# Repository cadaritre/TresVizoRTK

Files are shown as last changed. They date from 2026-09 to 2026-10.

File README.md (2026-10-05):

# TresVizoRTK

**Alimentación — 02/10/2026:** LiPo 1S 3.7 V / 3000 mAh confirmada. Lectura MAX17048 y apagado coordinado Mk2 implementados; falta identificar el elevador de 5 V y validar físicamente el conjunto con UM980. Ver `hardware/wiring.md` desde la raíz. La carga es autónoma por hardware; USB impide el corte total de batería.
TresVizoRTK es un proyecto personal para desarrollar un prototipo funcional de receptor GNSS RTK de triple banda con IMU y lector microSD, orientado a trabajos de topografía. El repositorio reunirá el firmware de un ESP32-S3, una aplicación móvil, la documentación electrónica, la lista de materiales y los archivos mecánicos de una carcasa imprimible en 3D. La cobertura de bandas del conjunto receptor y antena deberá verificarse con el hardware real.

El objetivo es disponer de un software de instrumento robusto en el ESP32-S3, tomando la experiencia de equipos Emlid como referencia de producto. El firmware concentrará la configuración y operación del equipo; una app independiente, todavía sin iniciar, resolverá levantamientos, replanteos y trazo. Esta referencia no implica equivalencia de funciones o rendimiento validada.

El objetivo de desarrollo es alcanzar aproximadamente 2 cm de precisión en condiciones favorables. Esa cifra no representa una capacidad implementada, medida ni garantizada. La operación bajo árboles es un interés de investigación del proyecto y tampoco implica una garantía de precisión bajo vegetación.

## Estado actual

El firmware **0.8.0** está adaptado y compilado para **SparkFun Thing Plus ESP32-S3 WRL-24408**. El equipo conserva el nombre **MeridianV**, el panel, BLE, NTRIP y los servicios GNSS. La nueva placa sustituye a la Tiny; las pruebas físicas históricas de esa placa no validan este montaje.

Esta entrega añade OLED SSD1306 I2C de 128×64, microSD integrada por SDIO y una identidad de hardware independiente para las imágenes firmadas. La pantalla muestra calidad GNSS, satélites, correcciones, grabación e IP; caduca la calidad cuando dejan de llegar datos. La tarjeta no se formatea automáticamente.

El panel identifica la placa, muestra el estado de OLED y microSD y controla el registro según la disponibilidad real y el cierre de archivos. Las descargas incompletas conservan `.part`. Cargador USB y diagnóstico BLE actualizados para la nueva placa; [detalle del software](docs/panel-campo.md).

El almacenamiento se llama **Memoria interna del dispositivo** en la interfaz y en las etiquetas de la API para aplicaciones; en la OLED, **MEM INT.**. El soporte físico sigue documentado como microSD. Grabación, cierre, catálogo y descarga implementados; comprobación física pendiente.

**Pendiente de banco:** primera carga en Thing Plus, OLED recibida, microSD, enlace UART y operación prolongada. La adaptación no cargó firmware en ningún equipo. **Encendido/apagado con el SparkFun Soft Power Switch implementado; prueba física pendiente.** Durante el banco, Thing Plus y UM980 mantienen alimentación USB separada y GND común.

**Sin integrar:** IMU, radio UHF y aplicación móvil. La carcasa diseñada para Tiny requiere revisión para la Thing Plus y la OLED; no se ha dado por compatible ni se ha regenerado CAD.

El [cableado vigente](hardware/wiring.md) reúne los pines y la primera instalación. Detalle de cambios y pruebas en el [README del firmware](firmware/esp32/README.md). Las imágenes OTA llevan la [firma del propietario](tools/firmware_signing/README.md).

## Alcance previsto

El prototipo busca llegar a:

- Operación como rover RTK o como base.
- Recepción y transmisión de correcciones por los enlaces que se validen.
- Acceso a correcciones NTRIP.
- Registro de observaciones GNSS para postproceso externo.
- Integración GNSS/IMU y compensación de inclinación del jalón, todavía por desarrollar y validar.
- Configuración y operación del instrumento gestionadas por el firmware del ESP32-S3.
- Aplicación móvil independiente para levantamientos, replanteos y trazo, con acceso a configuración y estado mediante el protocolo del instrumento.
- Registro de diagnósticos para análisis y mejora del sistema.

## Arquitectura resumida

- **Receptor GNSS:** calcula la solución GNSS/RTK y produce observaciones y mensajes compatibles con su modelo y firmware.
- **ESP32-S3:** controla el receptor, enruta RTCM, adquiere la IMU, gestiona tiempos, almacenamiento, comunicaciones y apagado seguro. La fusión GNSS/IMU es trabajo futuro.
- **IMU BMI088:** aporta aceleración y velocidad angular para la futura integración GNSS/IMU y compensación de inclinación.
- **Lector y tarjeta microSD:** proporcionan almacenamiento local de observaciones, datos IMU y diagnósticos bajo control del ESP32-S3.
- **Aplicación móvil independiente:** gestiona mapas, proyectos, levantamientos, replanteos, trazo e intercambio de archivos; consulta el estado y solicita cambios de configuración al firmware.

La aplicación se comunicará mediante un protocolo propio del instrumento, separado de los comandos específicos de Unicore o u-blox. BLE se prevé como enlace principal de control y telemetría; el objetivo de 20 Hz está pendiente de pruebas. Wi-Fi, conectado al hotspot del teléfono, permitiría al ESP32 acceder a NTRIP. USB se reserva para desarrollo y diagnóstico, y Wi-Fi o USB para transferencias grandes.

La [arquitectura](docs/architecture.md) describe las responsabilidades y los flujos de datos con mayor detalle.

## Hardware previsto

La base considerada incluye:

- Unicore UM980 en una placa de desarrollo o carrier como GNSS principal.
- u-blox ZED-F9P disponible para posibles pruebas.
- SparkFun Thing Plus ESP32-S3 WRL-24408, con 4 MB de flash y 2 MB de PSRAM Quad según fabricante.
- Bosch BMI088 en breakout.
- Socket microSD integrado de la Thing Plus, SDIO de cuatro bits y tarjeta FAT32.
- OLED Tecneu 0.96 pulgadas I2C, cuatro pines y 128×64; driver SSD1306 según referencia del vendedor.
- Antena Helix, cuya compra confirmó el propietario; modelo y bandas por verificar. La HA-901A mencionada inicialmente no está confirmada.
- Batería LiPo de una celda, nominal 3.7 V y 3000 mAh, confirmada por el propietario.
- SparkFun Soft Power Switch JST 2 mm comprado; integración de encendido/apagado implementado; prueba física pendiente.
- Carcasa cilíndrica impresa en 3D y montaje sobre jalón.

El enlace GNSS usa RX del ESP32 en **GPIO44** y TX en **GPIO43**, con GND común; ambos equipos reciben alimentación USB por separado. La OLED usa **SDA8/SCL9 y 3.3 V**. El pinout de la Tiny (18/17) queda como historial. La disponibilidad de PPS en la carrier UM980 concreta está pendiente de verificación. Consulta la [lista de materiales](hardware/bom.md) y el [cableado vigente](hardware/wiring.md).

## Mapa del repositorio

| Ruta | Contenido previsto |
| --- | --- |
| `firmware/esp32/` | Firmware del controlador ESP32-S3. |
| `app/` | Aplicación móvil del instrumento. |
| `hardware/` | BOM, módulos comerciales, conexiones y referencias del hardware vigente. |
| `mechanical/` | V1 para imprimir y fuentes necesarias para regenerarla. |
| `docs/` | Arquitectura, estado, hoja de ruta y entorno de desarrollo. |
| `tools/` | Puente USB, diagnóstico GNSS/BLE, empaquetado y actualización de firmware. |
| `tests/fixtures/` | Datos de prueba pequeños y anonimizados. |

## Documentación

- [Arquitectura del sistema](docs/architecture.md)
- [Estado del proyecto](docs/project-status.md)
- [Servicios actuales del ESP32 (0.5.0)](docs/esp32-services.md)
- [Configuración avanzada del receptor (0.6.0)](docs/gps-advanced.md)
- [Panel reorganizado para campo (0.6.0)](docs/panel-campo.md)
- [Hoja de ruta](docs/roadmap.md)
- [Entorno y prácticas de desarrollo](docs/development.md)
- [Lista de materiales](hardware/bom.md)
- [Identificación del hardware recibido](hardware/identification.md)
- [Interfaces y conexiones](hardware/wiring.md)
- [Mecánica vigente, V2.2](mechanical/README.md)
- [Auditoría de la carcasa V1](mechanical/AUDITORIA-V1.md)
- [BOM de tornillería](mechanical/v2.2/SCREW-BOM.md)
- [Revisión de integración de V1, antecedente](docs/INTEGRATION_REVIEW.md)

No se ha seleccionado una licencia. El contenido del repositorio no debe interpretarse como publicado bajo una licencia específica hasta que el propietario la defina expresamente.

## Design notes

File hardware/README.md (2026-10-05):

# Hardware vigente

- [power-modules](power-modules/README.md): alimentación por módulos comerciales, arnés, panel y compras.
- [bom.md](bom.md), [identification.md](identification.md) y [wiring.md](wiring.md): inventario e interfaces del receptor.
- `references/`: evidencia de la batería y esquemas de Waveshare usados como referencia; no son una PCB propia para fabricar.
- [V2.2 mecánica](../mechanical/v2.2/README.md): carcasa, soportes y montaje vigentes.

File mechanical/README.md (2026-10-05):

# Mecánica vigente — TresVizo V2.2

**Abrir [TresVizo-V2.2.FCStd](v2.2/generated/TresVizo-V2.2.FCStd) con FreeCAD**, o
`v2.2/view_v2_2.py` para verlo con colores. Generado y comprobado con FreeCAD 1.1.

| Carpeta / archivo | Uso |
| --- | --- |
| [v2.2](v2.2/README.md) | **Vigente.** Montaje, criterio de diseño, parámetros y límites. |
| [v2.2/generated/stl](v2.2/generated/stl/) | Imprimir: cinco piezas rígidas y dos bandas de TPU. |
| [v2.2/generated/step](v2.2/generated/step/) | STEP por pieza para otros CAD, en posición cerrada. |
| [v2.2/SCREW-BOM.md](v2.2/SCREW-BOM.md) | Compra: 15 tornillos, la tuerca de latón del jalón y el conector de carga JST-XH. Los dos del IMU, avellanados. |
| [AUDITORIA-V1.md](AUDITORIA-V1.md) | Por qué se rehízo la carcasa desde cero. |
| [referencias](referencias/) | Cotas de los componentes comprados y datum del BMI088. |

## Qué cambió de V2.1 a V2.2

| | V2.1 | V2.2 |
| ---: | ---: | ---: |
| Diámetro exterior | 69 mm | **64 mm** (67.4 con las bandas de TPU) |
| Altura, del asiento del jalón a la cara de la antena | 136.9 mm | **129.9 mm** |
| Batería | LiPo 955565 en el trineo | **18650 detrás del respaldo** |
| Panel frontal | 66° × 58 mm, con USB-C | **86° × 83 mm**, con OLED 0.96", botón metálico de 12 mm y conector de carga JST-XH |
| Rosca del jalón | inserto de McMaster con brida: solo entraba pausando la impresión | **tuerca hexagonal 5/8"-11 de latón**, metida por dentro de la base |
| Panel auxiliar | sí | **no** |
| Interior | trineo atornillado a la base | **respaldo ranurado en el tubo y cuatro toalleros**; todo se amarra con bridas |
| IMU | repisa del trineo, con los agujeros en el eje (el chip quedaba 5.65 mm fuera) | **plataforma incrustada en la tapa**, con el chip en el eje |
| Bayonetas | entraban en tres posiciones | **una sola posición** |
| Protección | — | **bandas de TPU** arriba y abajo |

Las versiones anteriores (V2, V2.1 y la opción del domo para V2.1) se quitaron
del repositorio el 04-10-2026. Siguen en el historial de git: la última vez que
están completas es el commit `94f00f9`.

## Regenerar

```sh
python3 mechanical/v2.2/regenerate.py
```

Localiza FreeCAD solo, también en macOS. Comprueba sólidos, mallas,
interferencias, el paquete y la 18650 en el respaldo, los toalleros, la entrada
de la tapa del panel con todo montado, los pilotos del IMU, las uñas de la
plataforma, las bayonetas indexadas, la alineación de los seguros, la tuerca
del jalón con sus retenes, el bolsillo del JST y los tornillos bajo las bandas,
y devuelve código distinto de cero si algo falla.

## Estado

**Nada de V2.2 se ha impreso ni ensayado.** La geometría es coherente en CAD; eso
no es validación. Antes de imprimir la plataforma del IMU hay que medir en la
placa real dónde está el chip (ver el README de V2.2), y medir la tuerca del
jalón y el header JST que se compren: el modelo usa las medidas de norma y del
plano de JST.

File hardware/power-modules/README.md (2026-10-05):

# Alimentación e interfaz con módulos comerciales

> **Histórico — 02/10/2026:** esta propuesta corresponde a la Tiny. La placa definitiva es Thing Plus ESP32-S3 y el control del Soft Power Switch está implementado; la distribución portátil del UM980 sigue pendiente. No aplicar este arnés al montaje nuevo; consultar [cableado vigente](../wiring.md).

Revisión del 20 de septiembre de 2026. Sustituye la propuesta de PCB personalizada por módulos comprables y un arnés. Se conservan la Tiny, su Tiny-Adapter y cable original, el UM980, BMI088, microSD y batería. El receptor V2 (hoy [V2.2](../../mechanical/v2.2/README.md)) integra los paneles y los soportes internos; el firmware se conserva.

**Resultado: tres módulos principales, pulsador y dos ventanas de luz en el panel.** El USB-C exterior se usa para alimentación/carga y para el USB nativo del ESP32. El botón exterior acciona el encendido electrónico; el cierre de archivos antes de apagar requiere integración en firmware. No hay PCB que mandar fabricar.

Es una selección y un diseño de interconexión para prototipo, contrastados con documentación. No es un montaje ensayado ni una declaración de cumplimiento USB. Las limitaciones concretas de corriente del host, detección VBUS y protección se indican abajo; no están resueltas simplemente por comprar las tres placas.

## Lista principal

Precios publicados al consultar; excluyen envío e impuestos adicionales. Se distinguen USD y MXN. Véase [suministro para México](SOURCING_MX.md) para vendedores y disponibilidad real observada.

| Función | Producto comprado ya montado | Cantidad | Precio |
| --- | --- | ---: | ---: |
| Cargador LiPo 1S, power-path y elevador | [Adafruit PowerBoost 1000C, 2465](https://www.adafruit.com/product/2465) | 1 | $19.95 |
| Pulsador electrónico, apagado por software y forzado | [SparkFun Soft Power Switch Mk2 JST 2 mm, PRT-26993](https://www.sparkfun.com/sparkfun-soft-power-switch-jst-2mm.html) | 1 | $7.32 |
| USB-C exterior y desconexión de datos | [Adafruit TS3USB30, 5871](https://www.adafruit.com/product/5871) | 1 | $3.95 |
| Pulsador bajo un actuador impreso al ras | [Steren AU-101, momentáneo NA](https://www.steren.com.mx/micro-switch-de-push-con-4-terminales.html) | 1 | $2 MXN |
| Indicador de estado RGB | [Steren LED-5/RGB, ánodo común](https://www.steren.com.mx/led-de-5-mm-rgb.html) | 1 | $5 MXN |

**Los tres módulos suman $31.22 USD; pulsador y RGB suman $7 MXN.** El presupuesto anterior de $35.72 USD empleaba dos periféricos Adafruit y queda sustituido por esta selección local. Añadir cable USB corto, cableado, resistencias, transistores, fusibles, tornillos, piezas ópticas y envío/importación. El costo total entregado no está cotizado; tampoco incluye una protección de batería adicional si el pack carece de ella ni las ampliaciones USB descritas abajo. No se compró nada.

El indicador de carga aprovecha los LEDs amarillo y verde del PowerBoost mediante guías ópticas hacia una segunda ventana. Así funciona con el receptor apagado y no requiere otra placa ni modificar las salidas del cargador.

## Conexión general

```mermaid
flowchart TD
  PC[Computadora o cargador USB] --> U[USB-C exterior: Adafruit 5871]
  U -->|USB_VBUS; ramal de carga desconectable| P[PowerBoost 1000C]
  B[Batería LiPo 1S protegida] <--> P
  P -->|VS: antes del elevador| S[SparkFun Soft Power Switch Mk2]
  BTN[Pulsador al ras] -->|BTN / GND| S
  S -->|VOUT: señal de habilitación| EN[EN del PowerBoost + 10 kohm a GND]
  EN --> P
  P -->|Salida regulada SYSTEM_5V| LOAD[Tiny + UM980 + demás cargas verificadas]
  U -->|D1+ / D1-; sólo datos y masa| C[Cable interno USB-C con alimentación separada]
  P -->|SYSTEM_5V al VBUS del cable interno| C
  C --> A[Tiny-Adapter original]
  A -->|FPC original, sin cambiarlo| ESP[ESP32-S3-Tiny externa]
  ESP <-->|PUSH / OFF| S
  ESP -->|GPIO y drivers del arnés| RGB[LED RGB detrás de ventana]
```

**USB_VBUS del conector exterior y SYSTEM_5V son redes distintas.** La alimentación del cable USB interno hacia Tiny-Adapter proviene de SYSTEM_5V. No se conecta a los pads de alimentación de las salidas del TS3USB30: esos pads están unidos a USB_VBUS y no son salidas aisladas.

El PowerBoost integra MCP73871 para reparto entre fuente/carga/batería y TPS61090 para elevar a aproximadamente 5.2 V. La protección contra descarga inversa del cargador y la separación del arnés evitan la ruta directa batería → host. Debe comprobarse el conjunto montado. [Esquema oficial](https://github.com/adafruit/Adafruit-PowerBoost-1000C), [MCP73871](https://www.adafruit.com/datasheets/MCP73871.pdf).

## Encendido y apagado

Se alimenta el SparkFun desde **VS**, no desde la salida de 5 V. Su salida controla **EN** del PowerBoost y una resistencia de 10 kΩ asegura el estado apagado. No transporta la corriente de todas las cargas. Esto permite apagar el elevador, cargar con el equipo apagado y conservar el apagado forzado por hardware.

El esquema oficial del PowerBoost Rev B tiene un pull-up de 200 kΩ en EN. Con 10 kΩ a masa, apagado queda nominalmente a 0.0476 × VS, por debajo del límite LOW de 0.2 × VS del TPS61090. Encendido sigue a VS y supera 0.8 × VS. Es un cálculo del circuito, pendiente de ensayo del conjunto. [Archivos Adafruit](https://github.com/adafruit/Adafruit-PowerBoost-1000C), [TPS61090](https://www.adafruit.com/datasheets/tps61090.pdf).

El pulsador se conecta a BTN/GND; PUSH informa al ESP32 y OFF alto corta. Una pulsación sostenida unos diez segundos corta por hardware. Abrir los jumpers de LEDs IN/OUT del SparkFun evita luz y consumo internos innecesarios. El consumo de toda la instalación apagada debe medirse; el dato de reposo del módulo no representa el sistema completo. [Guía SparkFun](https://docs.sparkfun.com/SparkFun_Soft_Power_Switch_Mk2/single_page/).

## Qué permite el puerto único

| Estado | Comportamiento previsto |
| --- | --- |
| Batería, equipo ON | Operación normal; el puerto exterior no suministra 5 V al host. |
| USB, equipo OFF | Carga; sin consola porque el ESP32 está apagado. |
| USB, equipo ON | Carga/alimentación y datos simultáneos, dentro de la corriente disponible. |
| Debug detenido en un breakpoint | Alimentación mantenida por el módulo; no necesita heartbeat del firmware. |
| Firmware bloqueado | Pulsación larga corta; para recuperar el firmware quedan BOOT/RUN del Tiny-Adapter. |

El USB nativo proporciona flashing, consola Serial/JTAG y depuración del **ESP32**. El UM980 se consulta desde esa consola mediante su UART y software de puente/diagnóstico que debe implementarse. **No se promete que el programa de actualización de Unicore pueda reflashear el UM980 a través del ESP32 sin ese puente y sin verificar su protocolo.** No hay acceso JTAG al UM980 a través del JTAG del ESP32. [Espressif USB Serial/JTAG](https://docs.espressif.com/projects/esp-idf/en/stable/esp32s3/api-guides/usb-serial-jtag-console.html).

## Límites que condicionan el montaje

1. **Corriente del USB.** PowerBoost está configurado para fuente de pared y carga de hasta 1 A; no negocia por sí mismo el presupuesto de un puerto de computadora. Para carga y operación simultáneas usar una fuente/puerto documentado de 5 V y al menos 2 A, compatible con su margen de entrada. Las resistencias CC de la placa USB no autorizan a tomar 2 A de cualquier puerto. Para un puerto de datos de capacidad desconocida, abrir el ramal interno `CHARGE_LINK` y operar desde batería: el mismo USB-C sigue dando datos. Para automatizar carga limitada en todos los puertos haría falta gestión adicional de corriente; no se presenta como resuelta.
2. **Batería.** La referencia 955565 anunciada es 1S, 3.7 V/5000 mAh. Antes de conectarla se comprueban polaridad, protección PCM y admisión de carga a 4.2 V/1 A. PowerBoost no sustituye una protección de pack ni incorpora un termistor pegado a esta batería. La carga de una celda cuya protección y límites se desconocen no queda validada. Se conserva la [evidencia original](../references/BATTERY_REFERENCE.md).
3. **USB self-powered.** El TS3USB30 permite desconectar los datos cuando está sin alimentación y seleccionar un canal vacío cuando Tiny está apagada. Eso **no demuestra** los umbrales de detección VBUS ni el tiempo de desconexión. Espressif indica detección válida por encima de 4.75 V, inválida por debajo de 4.35 V y señal baja en 3 ms al desconectar. Los condensadores de los módulos pueden retener VBUS. El prototipo requiere medirlo y completar detector/descarga si procede; no es una solución certificada. `self_powered` y `vbus_monitor_io` pertenecen a TinyUSB/OTG, no configuran Serial/JTAG ni ROM. [Espressif](https://docs.espressif.com/projects/esp-idf/en/v5.4/esp32s3/api-reference/peripherals/usb_device.html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), [TI TS3USB30](https://cdn-shop.adafruit.com/product-files/5871/ts3usb30.pdf).
4. **Protección y corriente del sistema.** El módulo USB no trae una matriz TVS dedicada; la especificación HBM del chip no acredita ESD del equipo. Para uso de campo debe completarse esa protección y ensayarse. El elevador se selecciona para un presupuesto inicial de hasta 1 A; comprobar arranque, radio, microSD, ruido GNSS y margen térmico con todos los módulos. Verificar las entradas de alimentación reales antes de distribuir 5.2 V. No aplicar 5.2 V al chip BMI088 ni a señales de 3.3 V.

Estos puntos separan el prototipo económico de la anterior propuesta de producto con protecciones adicionales; no deben ocultarse en una lista de compras presentada como equivalente.

## Archivos y alternativas evaluadas

- [Cableado y control](WIRING.md).
- [Montaje al panel y dimensiones para mecánica](PANEL.md).
- [CAD, STEP, STL y montaje de V2.2](../../mechanical/v2.2/README.md).
- [Proveedores para México](SOURCING_MX.md).
- [Diagrama inicial del reparto](panel-and-modules.svg), anterior a seleccionar pulsador y RGB Steren; no usar sus precios como presupuesto vigente.

El [Adafruit bq25185 + boost 6106](https://www.adafruit.com/product/6106), de $8.95, ahorra $11, pero su guía advierte arranque con cargas por encima de 200 mA y un temporizador de carga fijo de seis horas. No se elige sin resolver esas condiciones para el GNSS y la batería de 5 Ah. [Limitaciones oficiales](https://learn.adafruit.com/adafruit-bq25185-usb-dc-solar-charger-with-5v-boost-board/pinouts).

El [DFRobot MP2636 DFR0446](https://www.dfrobot.com/product-1613.html), de $8, es otra alternativa documentada con power-path, pero requiere cerrar corriente de carga/entrada, control OFF y transiciones de fuente de la placa concreta antes de sustituir el PowerBoost. El biestable verde que ya tiene el proyecto puede reutilizarse sólo después de identificar sus señales y comprobar apagado controlado/forzado; no se atribuyen esas funciones por su anuncio. CP2102N queda fuera.

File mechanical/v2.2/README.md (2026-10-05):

# TresVizo V2.2 — Ø64 × 130, panel con pantalla y botón, IMU en la tapa, bandas de TPU

Revisión de V2.1 pedida por el propietario el 2 de octubre de 2026:

1. **Diámetro máximo 64 mm** (sin contar las bandas de TPU) y altura de unos
   130 mm. La batería es una **18650**: no hace falta el ancho que pedía la
   955565 de V2.1.
2. Panel frontal con la pantalla OLED y el botón metálico de 12 mm que compró,
   cada uno con su montaje, más el conector de carga y los dos LEDs. Sin panel
   auxiliar.
3. Fuera el trineo universal. Todo se amarra con bridas a un respaldo que forma
   parte del tubo, con huecos grandes en sus costillas, o a cuatro toalleros.
4. El IMU va en una plataforma que se incrusta en la tapa de antena, con el
   **chip** en el eje del receptor, y con un paso amplio para el coaxial.
5. Tapa plana, como V2.1, y dos bandas de protección de TPU, arriba y abajo.

El 4 de octubre pidió dos cambios más: la rosca del jalón con una tuerca que se
compra hecha ([Tuerca del jalón](#tuerca-del-jalón)) y, en el panel, un JST-XH
de 2 pines en lugar del USB-C, para simplificar la carga.

El primer borrador de V2.2 medía Ø79 (commit `5d196e6`). El propietario fijó
después Ø64 como máximo. Entre medias, una revisión independiente del modelo
encontró fallos que quedan corregidos (ver [abajo](#lo-que-corrigió-la-revisión)).

V2.1, V2 y la opción del domo se quitaron del repositorio el 4 de octubre.
Siguen en el historial de git: la última vez que están completas es el commit
`94f00f9`.

**Nada de V2.2 se ha impreso ni ensayado.** La geometría es coherente en CAD y
pasa las comprobaciones automáticas; eso no es validación.

## Qué cambió frente a V2.1

| | V2.1 | V2.2 |
| --- | ---: | ---: |
| Diámetro exterior | 69 mm | **64 mm** (67.4 con las bandas) |
| Del asiento del jalón a la cara de la antena | 136.9 mm | **129.9 mm** |
| Largo útil interior | 114 mm | **107 mm** |
| Batería | LiPo 955565 en el trineo | **18650 detrás del respaldo** |
| Panel frontal | 66° × 58 mm: USB-C, botón de 10.4, dos LEDs | **86° × 83 mm**: OLED 0.96" en su marco, botón de 12 mm, JST-XH de carga a ras, dos LEDs |
| Panel auxiliar | 50° × 40 mm con USB-C | **no hay** |
| Rosca del jalón | inserto de McMaster con brida | **tuerca hexagonal 5/8"-11 de latón**, por dentro de la base |
| Interior | trineo atornillado a la base | **respaldo ranurado en el tubo y cuatro toalleros** |
| IMU | repisa del trineo, con los **agujeros** en el eje (chip 5.65 mm fuera) | **plataforma incrustada en la tapa**, con el **chip** en el eje |
| Bayonetas | tres dientes iguales: la tapa cerraba en tres posiciones | **un diente índice**: una sola posición |
| Protección | — | **bandas de TPU** arriba y abajo |
| Piezas | 6 | 7 (5 rígidas y 2 de TPU) |
| Tornillos con largo definido | 13 | 15 |
| Material rígido | 187 cm³ | 156 cm³ |

## Tuerca del jalón

La rosca del jalón es una **tuerca hexagonal 5/8"-11 UNC de latón**, estándar:
15/16" entre caras y 35/64" de alto. Sustituye al inserto de McMaster que venía
de V2, que solo entraba pausando la impresión.

- Entra **por dentro** de la base, con el tubo quitado, en un alojamiento
  hexagonal de 24.1 mm entre caras que no la deja girar.
- Apoya en un **anillo de 2 mm**. La cara de abajo de ese anillo es el asiento
  contra el bastón: se imprime sobre la cama, plana y a escuadra con el eje. Al
  apretar, el perno jala la tuerca contra el anillo y el anillo contra el hombro
  del bastón: todo trabaja a compresión.
- El perno cruza el anillo con 0.36 mm de holgura por lado, por una entrada a
  45°, y no rosca en el plástico.
- Por arriba la detienen **dos M3×8 con arandela ancha DIN 9021** (9 mm),
  frente a dos caras del hexágono. Cada arandela pisa 1.4 mm de tuerca y deja
  2.6 mm al perno. Solo trabajan mientras entra el perno o con el equipo suelto.
- Se imprime sin pausa, y si se daña la rosca se cambia la tuerca.
- La altura no cambia: la cara de arriba de la base sigue en z = 15.9 y el ARP
  en 129.9 mm.
- En un mismo bastón el receptor queda siempre en el mismo ángulo; en otro
  bastón, en otro. El frente es el panel: se gira el bastón para tenerlo
  enfrente, como pide Emlid con su Reach RS3.

**Qué tuerca comprar:** hexagonal estándar de 5/8"-11 UNC de latón (en ferretería,
"5/8 NC" o "rosca estándar", 11 hilos). No sirven la pesada (1-1/16" entre
caras), la de rosca fina 5/8"-18 ni las de seguridad con nylon. Una que se
encontró el 04-10-2026:
[Los Tornillos, "TUERCA HEXAGONAL NC ESTANDAR 5/8 LATÓN"](https://lostornillos.mx/products/tuerca-hexagonal-nc-laton-5-8-11),
51.79 MXN. Al recibirla, medirla: hasta 24.0 entre caras y 13.9 de alto entra
tal cual. Si no, se cambia `tuerca_jalon` en `parameters.json` y se regenera.

## El IMU: qué estaba mal en V2.1 y cómo queda

En el BMI088V1.0 los dos agujeros están en el borde largo **opuesto** a los
pines, y el chip queda **5.65 mm** hacia los pines. V2.1 ponía en el eje la línea
que une los agujeros (x = ±9.25, y = 0): el sensor acababa 5.65 mm fuera del eje,
y su ajuste de ±1.5 mm no alcanzaba para corregirlo. Además lo sujetaba con M2 en
ranuras, con tuerca y arandela.

Posición del chip en la placa, cruzando el plano del vendedor, un render del
programa de diseño del PCB (KAIHCHIP, AliExpress 1005009869623539) y dos fotos:

| Cota | Valor |
| --- | --- |
| Centro del chip a la recta de los agujeros, hacia los pines | **5.65 ± 0.15** |
| Corrimiento a lo largo de esa recta, lejos del selector IIC/SPI | **0.25 ± 0.15**: 9.0 del agujero lejano y 9.5 del de junto al selector |
| Agujeros | Ø3.0, a 18.5 entre centros |
| Hilera de pines | a 14.0 de la recta de los agujeros |
| Contorno | el plano dice 23.5 × 18; el render y las fotos, **23.1 × 17.4-17.7** |

Como el contorno no es fiable y la relación chip-agujeros sí, V2.2 coloca la
placa **por sus agujeros**:

- Los pilotos están en **x = −9.0 y +9.5, y = +5.65**: ahí tienen que caer los
  agujeros para que el centro del chip quede en X = 0, Y = 0.
- Se sujeta con dos **M2.5×6 de cabeza avellanada**. El cono de la cabeza
  asienta en el canto del agujero de 3.0 y centra la placa sobre el piloto. Con
  cabeza cilíndrica quedarían 0.25 mm de juego por lado.
- Alrededor no hay topes: queda sitio para la mayor de las dos placas, con la
  palanca del selector.
- Orientación: cara de componentes arriba, agujeros al frente (+Y), pines atrás,
  selector a +X. Los ejes serigrafiados (+X hacia el selector, +Y hacia los
  agujeros, +Z fuera de la cara de componentes) coinciden con los del equipo.
  Como la plataforma y la tapa solo entran en una posición, no pueden quedar
  girados.
- La cruz grabada en la plataforma, fuera de la placa, y la flecha al frente
  permiten comprobar el centrado con una regla con todo montado.

Error esperado del chip respecto del eje: ±0.15 de la posición del chip en la
placa más lo que se desvíe la impresión de los pilotos, unos ±0.1. Para
confirmarlo antes de imprimir, medir con vernier en la placa real la distancia del
centro del chip a la recta de los agujeros: si no da 5.65, se cambia
`imu.chip.desde_linea_agujeros` y se regenera.

## Plataforma del IMU

Cuarta pieza. Disco con falda que entra por abajo en el cuello de la tapa.

- **Centrado y altura.** La falda entra en el taladro del cuello con 0.2 mm de
  holgura por lado y su borde superior asienta contra la cara inferior de la
  tapa: la plataforma queda concéntrica con la antena y paralela a ella, porque
  las dos van en la misma pieza.
- **Retención.** Tres uñas en lengüetas de 12 × 6 × 1.6 entran en tres ventanas
  del cuello. La cara de retención va a 45° y la ventana se coloca de modo que la
  lengüeta quede todavía doblada 0.3 mm: ese resto empuja la plataforma contra la
  tapa y le quita el juego. Absorbe de −0.30 a +0.40 mm de error en la altura de
  la ventana. La flexión al entrar es del 1.2 %.
- **Para sacarla**, con la tapa fuera del tubo: tirar con firmeza. A 45° la uña no
  se autobloquea con rozamientos normales.
- **Una sola orientación.** Las uñas están a 35°, 145° y 320°: girada, alguna no
  encuentra su ventana.
- **Sitio para el coaxial.** Quedan 17.4 mm entre los componentes del IMU y la
  tapa, para el SMA macho acodado que conecta la antena (15 mm más margen). El
  coaxial y los cables del IMU salen por el **paso trasero**, de 70° y desde
  r = 15, justo encima del canal del respaldo.
- Separadores de 1.5 mm: el dorso de la placa no lleva componentes.

## Respaldo de amarre, 18650 y toalleros

**Respaldo.** Placa vertical de 49 mm de ancho casi en el centro del tubo (su cara
de apoyo en y = −7.5), unida a la pared trasera por dos costillas:

- **Delante**, el carrier UM980 y la Thing Plus, lado a lado.
- **Detrás**, en el canal entre las costillas, la **18650**. Queda a 0.6 mm de la
  pared y a 1.45 de cada costilla. Sin portapilas, que no cabe: la celda con su
  funda termoencogible, sobre una tira de fieltro o espuma.
- 24 ranuras cuadradas de 4.5 mm en cuatro columnas (x = ±5 y ±18.5) y filas cada
  10 mm, de z = 33 a 83. Admiten bridas de 2.5 a 3.6 mm en cualquier sentido.
  Una brida que entra por la ranura de −5 y sale por la de +5 rodea la 18650 por
  detrás de la placa.
- **Costillas con huecos:** cada costilla lleva tres huecos hexagonales de
  10 × 16 mm. Por ahí pasan bridas y cables de una celda del canal a otra.
- El canal está abierto abajo y arriba: por arriba bajan el coaxial y los cables
  del IMU desde la tapa.
- Los extremos libres de la placa quedan a 3.2 mm de la pared: una brida puede
  dar la vuelta por detrás.

**Toalleros.** Cuatro barras de amarre por dentro, para componentes extra:

| Barra | Ángulo | Altura z | Separación de la pared |
| --- | ---: | ---: | --- |
| Vertical | 30° | 40-80 | 4.5 mm |
| Vertical | 150° | 40-80 | 4.5 mm |
| Horizontal, 14 mm | 10° | 92 | 4.5 mm en los postes |
| Horizontal, 14 mm | 170° | 92 | 4.5 mm en los postes |

Barra de 4 × 4. Una brida la rodea por detrás. Los postes llevan escuadra a 45°
por debajo.

**Paquete comprobado** (objetos `ref_*` del modelo): 18650 del peor caso
(Ø18.6 × 69) detrás del respaldo, de z = 22 a 91; carrier UM980 y Thing Plus
delante, desde z = 22. Quedan **2.1 mm** entre el botón con sus cables y el UM980,
**11.7 mm** entre la pantalla con sus cables y las placas, y más de 5.2 mm hasta
los toalleros. Nada por debajo de z = 22: ahí está el collar inferior.

## Panel frontal

Tapa curva a ras de 86° × 83 mm. Todo va montado en la tapa y entra por la
ventana del tubo al cerrarla. Sus rebordes de arriba y de abajo, con sus dos
tornillos, quedan bajo las bandas de TPU.

| Elemento | Altura z | Montaje |
| --- | ---: | --- |
| Conector de carga JST-XH, 2 pines | 93.5 | Header vertical B2B-XH-A (7.4 × 5.75 × 7.0) en un bolsillo de 7.7 × 6.05, con la cara 0.25 mm bajo la superficie. Entra por fuera, cables primero, hasta el fondo; la ranura del fondo deja pasar las patas con los cables soldados y su termofit. Una gota de epóxico por dentro lo retiene al desconectar. |
| Dos LEDs | 93.5, a ±13.5 | Barrenos de 3.2, uno a cada lado del JST. |
| Pantalla OLED 0.96" | área activa centrada en 71.5 | Marco por dentro: el PCB apoya por la cara del vidrio en un plano en toda su altura; vidrio y mica en un bolsillo; cuatro M2×4 a sus agujeros. Ventana del área visible, con chaflán hacia fuera de 45° arriba y abajo, porque la pantalla se mira desde abajo, y de 20° a los lados. |
| Botón de 12 mm | 43.5 | Barreno de 12.3. Rebaje plano de 15 por fuera para la ceja y asiento plano de 18 por dentro para la tuerca: panel de 3.4 mm en el eje, 4.4 con la junta; el fabricante más restrictivo admite 6. |

- **Cables de la pantalla soldados.** A 64 mm de diámetro no caben los conectores
  Dupont detrás de la pantalla: los cuatro cables se sueldan a los pines o a los
  pads.
- **Mica:** lámina transparente de 1 mm (acrílico o PETG) recortada a
  **26.7 × 19.3**, delante del vidrio, en el mismo bolsillo. Sella la ventana. Si
  baila, una gota de silicón.
- La pantalla queda 4.5 mm detrás de la cara exterior en el centro, con 1.3 mm de
  tapa sobre el canto del bolsillo y 1.45 sobre los pilotos.
- Los agujeros de la pantalla son de 2.0 según el plano del vendedor: el M2 entra
  justo. Si no pasa, repasar con broca de 2.2 o usar M1.6.
- La tuerca del botón queda pegada al marco de la pantalla: apretarla con pinzas o
  una llave de 14 delgada, antes de montar la pantalla.
- **El LED del botón es de 12 V.** Con 3.3 o 5 V encenderá poco o nada.
- El tornillo de arriba de la tapa queda a 0.75 mm del cuello de la tapa de
  antena: es **M3×4** y no puede ser más largo.
- **El JST y los LEDs bajaron de 96 a 93.5.** El bolsillo del header sale 8 mm
  hacia dentro y tiene que pasar por la ventana del tubo, cuyo borde de arriba
  está en 98.4: queda 0.67 mm por debajo. Su cara de abajo va a 45° para
  imprimirse sin soporte.
- JST vende el XH como conector de placa, no como puerto para conectar y
  desconectar a diario: si se afloja, se cambia el header.
- El cambio es solo mecánico. Qué cargador entra por el JST y su polaridad los
  define la electrónica.

## Bandas de TPU

Piezas 6 y 7. Dos fundas de 2 mm de pared, para imprimir en TPU. Cada una tapa
entera la cabeza de los tornillos que tiene debajo: el seguro de bayoneta y un
tornillo de la tapa del panel.

- **Abajo:** de z = 0 a 34.5. Cubre la base, el arranque del tubo y el tornillo de
  abajo de la tapa del panel; su canto queda a 1.5 mm del botón.
- **Arriba:** de z = 97.4 a 129.9 (32.5 de alto). Cubre el final del tubo, la tapa y
  el tornillo de arriba de la tapa del panel; su canto queda a 0.9 mm del hueco
  del JST.
- Diámetro interior 0.6 menor que el cuerpo: el TPU se estira y aprieta. Por
  fuera miden 67.4.
- Por dentro, una **caja redonda en cada tornillo**, 2 mm mayor que su cabeza (Ø8)
  y 1.2 de fondo, por si la cabeza asoma. Entre la caja y el canto de la banda
  quedan 1.5 mm.
- Como las cajas no son corridas, la banda entra en una sola posición: una
  **muesca** de 1.2 × 1 en su canto libre va sobre el centro del panel.
- Se imprimen sin soporte: el techo de cada caja vuela 1.2 mm.
- Cantos exteriores redondeados.
- Para abrir la bayoneta o quitar la tapa del panel hay que quitar antes la banda.

## Detalles de acabado

- Tapa plana, como V2.1, con chaflán a 45° en su canto y una ranura fina de Ø48
  alrededor de la antena que enmarca su base.
- Chaflán de 0.5 en el canto exterior de la tapa del panel: la junta con el tubo
  queda como una línea en V y no como una rendija.
- Logo grabado de 32 mm en la espalda, opuesto al panel.
- Las líneas verticales de diseño y la ventana de la pantalla con su chaflán se
  conservan.

## Montaje

1. **Base:** meter la tuerca de latón por dentro hasta el anillo y poner los dos
   M3×8 con su arandela ancha.
2. **Tapa del panel:** botón con su tuerca por dentro; pantalla con la mica, sus
   cables soldados y cuatro M2×4; header JST con los cables soldados a sus patas
   y termofit, metido por fuera, cables primero, hasta el fondo, y una gota de
   epóxico por dentro; LEDs; cables con largo de sobra.
3. **Paquete:** 18650 detrás del respaldo, por el extremo de abajo del tubo, con
   una brida por las ranuras de ±5; UM980 y Thing Plus delante, por la ventana
   del panel y por los extremos del tubo.
4. **Tapa de antena:** antena con tres M2.5×10 desde dentro; SMA acodado; IMU en
   la plataforma con dos M2.5×6 avellanados; meter la plataforma por abajo hasta
   el clic, con el coaxial y los cables por el paso trasero.
5. **Tubo sobre la base:** el diente ancho por su entrada ancha, girar en
   sentido horario visto desde arriba hasta el tope y M3×10 del seguro.
6. **Tapa sobre el tubo:** bajar los cables del IMU y el coaxial por el canal del
   respaldo, conectar por la ventana del panel, diente ancho por su entrada, girar
   en sentido horario hasta el tope (28.7°: dejar cable de sobra) y M3×12 del
   seguro.
7. **Tapa del panel:** conectar pantalla, botón, JST y LEDs y cerrar con dos
   M3×4.
8. **Bandas de TPU:** deslizarlas, una por abajo y otra por arriba, con la muesca
   sobre el centro del panel.

La lista completa está en [SCREW-BOM.md](SCREW-BOM.md).

## Impresión

| Pieza | Material | Orientación | Soportes |
| --- | --- | --- | --- |
| `01-threaded-base` | PETG o ASA | Cara del jalón en la cama. | Los mismos que V2.1. Sin pausa: el alojamiento de la tuerca queda abierto por arriba. |
| `02-logo-tube` | PETG o ASA | De pie. | **Solo dentro de la ventana del panel**: su techo es una franja curva que no se puede puentear. La tapa del panel lo cubre. El respaldo, sus costillas y los toalleros se imprimen sin soporte; el canto inferior de la placa del respaldo es un puente de unos 22 mm. |
| `03-antenna-cap` | PETG o ASA | Boca abajo, con la cara de la antena en la cama. | **Bajo los tres dientes de la bayoneta**, apoyado en la placa: son su cara de carga. El refuerzo del seguro va unido a la placa y el canto que retiene cada uña es un puente de 6.3 mm. |
| `04-imu-platform` | PETG o ASA | Disco en la cama. | Ninguno. |
| `05-panel-cover` | PETG o ASA | De pie, sobre su canto inferior, con **brim**. | Ninguno: el techo del bolsillo de la pantalla es un puente de 27 mm; el del bolsillo del JST, uno de 7.7, y su cara de abajo va a 45°. |
| `06-bumper-bottom` y `07-bumper-top` | **TPU 95A** | De pie. | Ninguno. |

Las uñas flexionan 1.2 % al entrar: el PETG lo aguanta de sobra; el PLA también,
pero perdona menos y se ablanda al sol.

El barreno de 12.3 del botón se imprime en horizontal y puede salir algo cerrado
arriba: si el botón no entra, repasarlo con lima redonda.

## Altura del ARP: el firmware usa otra cifra

Del asiento del jalón (cara inferior de la base) a la cara de la tapa donde apoya
la antena hay **129.9 mm** en V2.2; en V2.1 eran 136.9. El firmware usa
`kCaseOffsetM = 0.10` (`firmware/esp32/include/base_plan.h:9`), una cifra
declarada y sin medir que no corresponde a ninguna de las dos. Aquí no se cambió:
se corrige cuando se imprima la carcasa y se mida la real.

## Lo que corrigió la revisión

Una revisión del modelo del primer borrador encontró:

| Hallazgo | Corrección |
| --- | --- |
| El barreno de accesorios de 324° apuntaba a la esquina de la batería. | Barrenos de accesorios desactivados (`accesorios.activo`). Flanqueaban el panel auxiliar, que ya no está. |
| El USB-C quedaba 2 a 3.6 mm hundido y el hueco no dejaba entrar el plástico de la clavija. | Asiento plano por dentro y hueco exterior del tamaño del sobremolde. El 04-10-2026 el USB-C se cambió por el JST-XH. |
| La tapa cerraba también girada 120° o 240°, con el IMU y la antena girados. | Diente índice en las dos bayonetas. |
| La uña a 30° absorbía poco error y casi se autobloqueaba. | Uña a 45°. |
| Los dos M2 de abajo de la pantalla apretaban contra el chaflán del marco. | Cara plana del marco en toda la altura del PCB. |
| La comprobación de las uñas no detectaba una ventana que faltara, y la de los pilotos repetía la fórmula del generador. | Uña por uña contra su valor de diseño; pilotos contra las distancias de las fuentes. |
| El refuerzo del seguro de la tapa quedaba en ménsula al imprimirla boca abajo. | Alma que lo une a la placa. |
| Pieles de 0.75 a 0.9 mm sobre la pantalla. | Pantalla más adentro y labio superior más ancho: 1.3 mm o más. |
| La mica de 27 × 19.5 no cabía con holgura. | 26.7 × 19.3. |
| El canto superior de la tapa era un escalón que, boca abajo, dejaba un voladizo visto. | Chaflán a 45°. |

Al pasar a Ø64 apareció otro: el piloto del seguro de la base llegaba sobre el
alojamiento de la brida del inserto y dejaba 0.2 mm de pared. Se acortó y lleva
un M3×10. Con la tuerca en lugar del inserto, quedan 6.8 mm hasta su
alojamiento.

## Pendientes

- **Posición del chip del IMU:** 5.65 ± 0.15 de la recta de agujeros, de
  fuentes del vendedor. Conviene medirla en la placa real (ver arriba). El
  espesor del PCB tampoco está publicado: se supone 1.6.
- **18650:** el modelo usa el peor caso con protección (69 mm). Medir la real.
- **Tuerca del jalón:** el alojamiento sale de la norma ASME B18.2.2. Medir la
  tuerca comprada antes de imprimir la base (ver [arriba](#tuerca-del-jalón)).
- **Header JST-XH:** las medidas son del plano de JST. Un clon puede variar:
  medirlo antes de imprimir la tapa del panel y, si hace falta, cambiar
  `panel.jst_xh`. Si la clavija no entra completa, `hundido` negativo saca el
  header.

## Piezas

| Archivo | Qué es |
| --- | --- |
| `01-threaded-base.stl` | Base: alojamiento hexagonal de la tuerca 5/8" de latón, anillo de asiento y bayoneta con diente índice. |
| `02-logo-tube.stl` | Tubo: logo grabado, respaldo de amarre, toalleros, panel frontal, líneas de diseño. |
| `03-antenna-cap.stl` | Tapa plana: cuello con las tres ventanas de la plataforma, bayoneta con diente índice y ranura alrededor de la antena. |
| `04-imu-platform.stl` | Plataforma del IMU: disco, falda, tres uñas, separadores con piloto, apoyos y cruz grabada. |
| `05-panel-cover.stl` | Panel principal: pantalla, botón de 12 mm, conector de carga JST-XH y dos LEDs. |
| `06-bumper-bottom.stl` | Banda de TPU de abajo. |
| `07-bumper-top.stl` | Banda de TPU de arriba. |

## Regenerar

```sh
python3 mechanical/v2.2/regenerate.py
```

Localiza FreeCAD y funciona también en macOS. Hace, en este orden:

1. Reparte el exterior y coloca el logo (`layout_check.py`).
2. Elige la tornillería (`bom.py`).
3. Construye y exporta las piezas, y dibuja los componentes de referencia.
4. Comprueba sólidos, mallas cerradas e interferencias de hasta 1 mm³ (las
   bandas de TPU, que aprietan por diseño, no cuentan).
5. Ejecuta `capacity_check.py`: paquete y 18650 en el respaldo, huecos de
   ranuras y costillas, toalleros, entrada de la tapa del panel con todo montado
   en 35 mm de recorrido, pieles sobre la pantalla, botón, pilotos del IMU, sitio
   para el SMA, uñas una por una, bayonetas indexadas, seguros, tuerca del
   jalón con sus retenes, tornillos del panel, tornillos bajo las bandas y
   bolsillo del JST.

Si algo falla, sale con código distinto de cero. Los resultados quedan en
[`generated/capacity.json`](generated/capacity.json).

Para verlo con colores, abrir `view_v2_2.py` desde FreeCAD. Los objetos `ref_*`
son los componentes comprados en su sitio: no se imprimen.

## Límites

- **Sin imprimir ni ensayar.** Sin datos de resistencia, ajuste, temperatura ni
  estanqueidad.
- Las holguras (0.2 en la falda de la plataforma, 0.3 en las ventanas de las
  uñas, 0.35 en la bayoneta) suponen una impresora que saca las cotas a ±0.1.
- El apriete de las bandas (0.6 en diámetro) depende del TPU y de la impresora.
- El interior va justo: entre el botón con sus cables y el UM980 quedan 2.1 mm, y
  la 18650 queda a 0.6 de la pared.
- La antena sigue siendo la HA-901A atornillada por fuera.

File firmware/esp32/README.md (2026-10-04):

# Firmware inicial del instrumento

**Alimentación — 02/10/2026:** LiPo 1S 3.7 V / 3000 mAh confirmada. Lectura MAX17048 y apagado coordinado Mk2 implementados; falta identificar el elevador de 5 V y validar físicamente el conjunto con UM980. Ver `hardware/wiring.md` desde la raíz. La carga es autónoma por hardware; USB impide el corte total de batería.
## 0.8.3 — Prioridad del operador (04/10/2026)

Las órdenes GNSS sustituyen el trabajo anterior; NTRIP, publicación y caster local aceptan cambios sin «detener primero». DNS, conexión y envío TCP son cancelables por una nueva decisión. Se descartan las respuestas y tramas de sesiones sustituidas, y un promedio cancelado no aplica después una base. La elección explícita de ninguna fuente también se respeta tras reiniciar.

La aceptación es inmediata y la confirmación sigue dependiendo del receptor. Se conserva la protección de archivos abiertos y de una actualización activa. Detalles y límites: [prioridad del operador](../../docs/connectivity/OPERATOR_PRIORITY_0.8.3.md). Pruebas nativas: `python3 tools/firmware_tests/run_native.py` desde la raíz.

## 0.8.2 — Transporte con las apps (04/10/2026)

BLE conserva cada fragmento hasta que la pila lo acepta, respeta congestión y cierra una respuesta atascada a los 4.5 s. Las líneas vencidas, desbordadas o con NUL se consumen hasta LF; la sesión nueva empieza con un acumulador vacío. Un error 413 conserva el `id` de la orden. La salud sólo actualiza su reloj de envío al aceptarse; las órdenes siguen antes que la telemetría.

WebSocket comprueba la edad de llegada de la posición al enviar, además del tiempo en cola: máximo 500 ms. Las sesiones tienen envío sin bloqueo verificado. OTA permite continuar y abortar la sesión aunque una tarea del arranque se active después; GNSS y autoconexión NTRIP esperan durante la actualización.

UUID, formatos binarios, límites, rutas y campos existentes de las apps se conservan. Informe y alcance de las pruebas: [auditoría del transporte](../../docs/connectivity/TRANSPORT_AUDIT_0.8.2.md). Banco repetible: `~/.platformio/penv/bin/python tests/protocol_transport_bench.py --stall` desde la raíz; `--fragment-bytes 0` usa el MTU negociado en todas las órdenes. El banco no guarda credenciales ni coordenadas. La comprobación visual de OLED sigue pendiente como indica `docs/firmware-validation.md`.

## 0.8.0 — Thing Plus ESP32-S3 y OLED (02/10/2026)

Placa seleccionada: **SparkFun WRL-24408, MINI-1-N4R2**. La definición local `boards/sparkfun_thing_plus_esp32s3.json` fija flash de 4 MB, PSRAM Quad de 2 MB, USB CDC/JTAG y el perfil de CPU. El entorno sigue llamándose `esp32s3_usb` para mantener las rutas de las herramientas. El cableado está en [hardware/wiring.md](../../hardware/wiring.md); las referencias posteriores a Tiny/18/17 son históricas.

- UART del UM980: **RX44/TX43**, COM2 a 115200. Pines centrales en `include/board_profile.h`.
- OLED SSD1306 128×64: **SDA8/SCL9**, dirección 0x3C o 0x3D, alimentación 3.3 V. Estado GNSS, satélites, RTCM, microSD e IP. Una tarea propia refresca a 1 Hz; sin GGA fresca en dos segundos deja de afirmar FIX. Sin pantalla continúa el resto del equipo. La ficha Tecneu indica SSD1306 o compatible; validar el controlador de la unidad recibida.
- Socket microSD integrado: **SD_MMC a cuatro bits / 20 MHz**, CLK38, CMD34, D0/1/2/3=39/40/47/33 y detección48 activa alta. Insertar FAT32 antes de encender. Sin formateo automático; después de retirar/reinsertar, reiniciar para montar. Se conserva el registro `.part`/`.bin` y la cola UART. Una extracción durante grabación no permite marcar la sesión completa.
- GPIO45 habilita únicamente el regulador de periféricos integrado. **Soft Power Switch Mk2:** PUSH=GPIO10/A0, OFF=GPIO14/A1; cierre antes del corte y lectura MAX17048.
- `/api/status` añade `hardware_id`, `board` y `subsystems.display`; microSD informa detección e interfaz. El `hardware_id` es **`tresvizo-thingplus-s3-4m-v1`**.
- La imagen conserva versión en byte 288 y añade identidad de placa en byte 320 (48 bytes, NUL). Ese campo pertenece a la imagen firmada: OTA y rollback rechazan otra placa aunque el manifiesto diga Thing Plus. Se conservan los registros de firma verificada introducidos en 0.7.14.
- Empaquetador, actualizador USB y cargador gráfico reconocen esta identidad. Para la placa nueva usar **Instalación completa** o `pio run -e esp32s3_usb -t upload` con su puerto confirmado. No cargar el binario nuevo a la Tiny.
- Panel adaptado: Diagnóstico muestra placa, UART, OLED y microSD desde la API. Registro bloquea acciones durante cierre y al perder el enlace; descargas incompletas conservan `.part`. `closing` se publica separado de `active` para reflejar el archivo aún ocupado en un cierre parcial. Puente USB y diagnóstico BLE actualizados. Detalle y pruebas de software en [panel-campo.md](../../docs/panel-campo.md).
- El almacenamiento se presenta como **Memoria interna del dispositivo**; la OLED muestra **MEM INT.** y la API añade `storage_label` para aplicaciones. Corregido el inicio de grabación desde el estado real `idle`, que el panel anterior no reconocía. La prueba local recorre inicio, parada, espera de cierre y descarga de contenido binario por bloques; no valida la escritura física.

**Verificado en esta entrega:** compilación y firma, 24 pruebas C++ host, 14 pruebas del banco GNSS, 12 pruebas del cargador (incluido el binario real), panel GNSS y preflight OTA del panel. La adaptación posterior del software añade pruebas de estados OLED/microSD, descargas y pérdida de enlace, más 14 pruebas de análisis BLE e inspección del panel en navegador con datos de prueba. La compilación final ocupa 101,024 bytes de RAM estática y 1,712,161 bytes de flash de aplicación (87.1% del slot). El paquete local está en `data/local/releases/0.8.0/`.

**Sin probar físicamente:** carga/arranque en Thing Plus, respuesta de la OLED, microSD/retirada de tarjeta, transición base/rover, OTA/rollback y estabilidad del conjunto. No se flasheó ningún equipo, se rediseñó la alimentación ni se modificó la carcasa. Las cifras históricas de validación de Tiny no se trasladan a esta placa.

## Historial anterior a Thing Plus

Versión 0.6.2 para el ESP32-S3 conectado por USB. El perfil usa 4 MB de flash comprobados por esptool. La placa de referencia de PlatformIO aporta la configuración de CPU/USB; no identifica la carrier como DevKitC ni autoriza sus pines externos. PSRAM Quad de 2 MB habilitada, con prueba de integridad y métricas separadas de RAM interna.

## Funciones del primer firmware

- Arranque sin esperar a que se conecte una consola USB.
- Red Wi-Fi propia protegida con una clave aleatoria por equipo, persistida en NVS y recuperable por acceso físico USB.
- Panel web en español con la identidad visual y el logo de TresVizo; los recursos están comprimidos en flash. No requiere microSD ni Internet.
- Estado real del controlador: tiempo encendido, memoria, flash, firmware y Wi-Fi.
- Ajustes persistentes: nombre, intervalo del panel y conexión a un hotspot protegido de 2.4 GHz. El AP permanece activo.
- Validación de tipos y límites, detección de conflictos de revisión y guardado de la configuración en una sola entrada NVS. Las solicitudes inválidas no modifican ajustes.
- Servidor HTTP de ESP-IDF con límites de cuerpo y espera; exclusión mutua para acceso desde HTTP/USB.
- Consola JSON USB con buffer acotado, tiempo límite y recuperación tras mensajes demasiado grandes.
- Reinicio solicitado y exportación de diagnóstico sin contraseñas ni nombres de redes.

Esa lista describe el primer firmware. GNSS, microSD, NTRIP, BLE y modos base/rover llegaron después; su estado real está en las secciones de versión de más abajo. Siguen sin implementarse la IMU y la compensación de inclinación, y la app de campo sigue sin iniciarse. No hay posiciones ni soluciones FIX simuladas.

## Compilar y cargar desde macOS

Abrir esta carpeta en VS Code con PlatformIO. Se usa PlatformIO Espressif32 6.12.0, Arduino-ESP32 2.0.17 y ArduinoJson 7.4.2. Esta base permite un primer arranque reproducible con las herramientas instaladas; los controladores posteriores pueden usar APIs ESP-IDF sin acoplarlos al panel.

Desde esta carpeta:

```sh
~/.platformio/penv/bin/pio run
~/.platformio/penv/bin/pio device list
~/.platformio/penv/bin/pio run -t upload --upload-port /dev/cu.usbmodem11201
```

El puerto puede cambiar. Detener el puente USB y cerrar otros monitores antes de cargar. La carga inicial contó con respaldo completo local de la flash, excluido de Git. No usar `erase_flash` como preparación habitual; borraría también ajustes y clave.

Los recursos web se empaquetan al compilar, sin `uploadfs`.

### Actualización por OTA: solo firmware firmado (desde 0.7.13)

Las dos particiones de aplicación permiten actualizar sin cable desde el panel,
las apps o `tools/firmware_upload.py` (por USB). **El equipo solo instala
`firmware-signed.bin`**: `firmware.bin` seguido de 72 bytes con la firma ECDSA
P-256 del propietario. `pio run` lo deja junto a `firmware.bin`
(`.pio/build/esp32s3_usb/`) si la clave privada está en la Mac; sin ella avisa y
compila igual, y `firmware.bin` sigue valiendo para cargar por USB con
`pio run -t upload`. Clave, respaldo y firma a mano en
[`tools/firmware_signing/`](../../tools/firmware_signing/README.md).

- `begin` recibe tamaño y SHA-256 del **archivo firmado**, como antes; a la flash
  solo va la imagen. En `finish`, tras el SHA del archivo, se comprueba la firma
  con la clave pública embebida (`include/firmware_signing_key.h`) **antes** de
  validar la imagen y de tocar el arranque. Sin firma: «El firmware no trae la
  firma del propietario. Usa el archivo firmware-signed.bin.» Firma que no
  verifica: «La firma del firmware no es válida; no se instala.» En los dos casos
  se invalida la partición destino y el arranque no cambia (estados
  `signature_missing` y `signature_invalid`).
- `/api/update/rollback` solo vuelve a una imagen que **también exija firma**
  (0.7.13 o posterior); si no, 409 «La imagen anterior no exige firma; no se
  restaura por la API. Usa el cable USB.». Volver a 0.7.12 reabriría la carga de
  firmware ajeno. La versión de la otra partición se lee de una identidad propia
  en el byte 288 de la imagen (`.rodata_custom_desc`), porque en Arduino-ESP32
  `esp_app_desc_t.version` dice siempre «esp-idf: v4.4.7 38eeba213a».
- `GET /api/update` informa `image_authenticity: "owner_signed_ecdsa_p256"`,
  `signature_required: true` y `previous_image_signature_required`.
- Formato y lógica en `lib/protocol/src/signed_firmware.h`, probados en
  `test/signed_firmware_test.cpp`. La verificación ECDSA en sí es de mbedtls y
  solo corre en el equipo.

## Abrir el panel

### Por USB desde la Mac

Desde la raíz del repositorio:

```sh
~/.platformio/penv/bin/python tools/usb_console.py serve
```

Abrir `http://127.0.0.1:8765`. El puente entrega los archivos web locales y obtiene estado y configuración del ESP32 real por USB. No contiene simulación. Sus archivos deben corresponder al firmware cargado. Solo escucha en loopback, restringe Host/Origin y exige una cabecera propia en la API. Usa el acceso físico USB para autenticar, sin devolver la clave al navegador.

Ctrl+C detiene el puente y libera el puerto. Con el puente abierto no debe usarse otro monitor serie. Al desconectar el equipo, la interfaz muestra pérdida de comunicación y oculta los valores anteriores; vuelve a intentar la conexión.

### Por Wi-Fi del instrumento

Con el puente detenido, consultar localmente la red y clave:

```sh
~/.platformio/penv/bin/python tools/usb_console.py access
```

Este comando muestra una credencial privada: no subir su salida al repositorio. Conectar el teléfono a la red `TresVizo-…`, abrir `http://192.168.4.1` e introducir la misma clave en el panel. La clave se mantiene solo en memoria de la pestaña; recargar puede exigir introducirla de nuevo.

El HTTP del prototipo depende de la protección y confianza de la red Wi-Fi. No exponerlo a Internet. Las credenciales de hotspot se guardan en NVS sin cifrado de flash; endurecimiento de credenciales y transporte queda pendiente antes de uso fuera del prototipo.

## API versión 1

Desde 0.6.2 ninguna ruta pide clave (`X-Device-Key` se retiró). No hay CORS habilitado.

| Método y ruta | Comportamiento |
| --- | --- |
| `GET /api/status` | Estado real, capacidades pendientes y campos GNSS nulos. |
| `GET /api/config` | Ajustes, revisión y disponibilidad NVS. Por HTTP y USB incluye `ap_password` (el panel la lee y la reenvía); **por BLE sale sin ella** desde 0.7.13. Las contraseñas de redes externas y NTRIP no salen nunca. |
| `PUT /api/config` | Actualización parcial con `revision` obligatoria; 409 si está obsoleta. |
| `POST /api/restart` | 202; programa reinicio después de responder. |

Cuerpo HTTP máximo: 1024 bytes; JSON con profundidad limitada. El nombre admite 1–32 caracteres ASCII de letras, números, espacios y guiones, sin espacios extremos. Intervalos del panel: 1000, 2000 o 5000 ms. El SSID admite hasta 32 bytes UTF-8; contraseñas de hotspot, 8–63 caracteres ASCII imprimibles. No se admiten redes abiertas en esta etapa. Vacío conserva la contraseña solo para la misma red; cambiar SSID exige contraseña nueva. `forget_wifi: true` elimina la red externa. Guardar sin cambios no vuelve a escribir en NVS.

La consola USB recibe una línea JSON de hasta 1024 bytes con `id`, `method`, `path`, `key` y `body` opcional; responde con `id`, `status` y `body`. Solo por USB existe `GET /api/access`, sin clave, para recuperar acceso físico. La consola es para diagnóstico; no fija el futuro protocolo BLE.

Las unidades de diagnóstico se indican en los nombres: milisegundos, bytes, MHz y dBm. El tiempo encendido es monotónico y no equivale a época GNSS. Las futuras mediciones deberán distinguir tiempo de medición, llegada, marco y referencia de altura.

## Verificación

Desde esta carpeta:

```sh
clang++ -std=c++11 -Wall -Wextra -Werror -I include test/config_rules_test.cpp -o /tmp/tresvizo-config-test
/tmp/tresvizo-config-test
node --check web/app.js
```

`test/secret_redaction_test.cpp` necesita además ArduinoJson, que queda en
`.pio/libdeps/` tras un `pio run`: añadir
`-I .pio/libdeps/esp32s3_usb/ArduinoJson/src`.

Desde la raíz, con el puente detenido:

```sh
~/.platformio/penv/bin/python tests/hardware_smoke.py
```

La prueba de hardware guarda ajustes temporales, reinicia el equipo y restaura los ajustes originales. No ejecutarla durante una operación de campo. Consultar los resultados y pendientes en `docs/firmware-validation.md`.

## Cambio de clave del equipo (0.2.0, retirado en 0.6.2)

> **Esta sección es histórica.** Desde 0.6.2 no hay clave de panel y el
> subcomando `set-access` se eliminó de `usb_console.py`. La contraseña del
> Wi-Fi propio es la única credencial y se cambia desde Configuración.

Con el puente detenido, ejecutar `python tools/usb_console.py set-access` e introducir dos veces la nueva clave en el prompt oculto. La operación solo existe por USB, requiere la clave actual (la consola la recupera por acceso físico), valida 8–63 caracteres ASCII imprimibles y reinicia después de guardar en NVS. Una solicitud inválida no cambia la clave. La clave anterior permanece activa hasta el reinicio; la nueva no se incluye en la respuesta ni en estado/configuración. No pasar credenciales como argumentos del shell ni guardarlas en el repositorio.

El panel representa estado GNSS, calidad y coordenadas recibidas por el ESP32, diferenciando datos antiguos y falta de posición. La tarea UART y el parser compartido se describen en [adquisición GNSS](../../docs/gnss-bringup.md). En 0.4.1 se habilita UART2 a 115200: RX GPIO18, TX GPIO17, tras confirmar el cableado TTL cruzado y GND común. Ambos equipos mantienen alimentación USB separada, sin unir alimentación. Tener ambos USB en la Mac por sí solo no los comunica.

## Apartados de operación (0.3.0)

El panel incluye Base / rover, Registro / PPK y Correcciones (entrada, publicación y caster local). El preparador de base valida datos y calcula altura elipsoidal ARP; permite exportar un plan JSON. No aplica comandos ni persiste ese plan. Los controles de registro/transferencia/cambio de modo permanecen deshabilitados con su motivo real.

- `GET /api/operations`: capacidades actuales; catálogo de sesiones nulo mientras no pueda consultarse almacenamiento.
- `POST /api/base/plan`: preparación autenticada con `method` (`known`/`average`) e `station_id`; devuelve `applied: false` y `persisted: false`. Los campos y límites se describen en [registro, base y NTRIP](../../docs/recording-base-ntrip.md).
- `python tests/operations_smoke.py`: valida la API en el ESP32 sin cambiar modo, guardar coordenadas ni transmitir correcciones.

## Versión 0.4.0

- Servicio BLE de control autenticado y telemetría; [protocolo y límites](../../docs/ble-protocol.md).
- OTA en doble partición, SHA-256, carga por bloques y recuperación; [paquetes y procedimiento](../../docs/firmware-updates.md).
- Router de correcciones desacoplado; solo BLE instalado en el firmware, UART aún deshabilitado sin verificar cableado.
- [Banco USB de Mac](../../docs/usb-bench.md) con GPS real, sesiones, conversión RINEX y NTRIP. No confundir sus controladores con capacidades autónomas del ESP32.

Las pruebas del controlador OTA están en `tests/update_smoke.py`; `--install` escribe la imagen compilada en la partición inactiva, reinicia y verifica el cambio de slot. No correr junto al puente USB ni a otro monitor.

## Versión 0.5.0

Control bidireccional UM980, PSRAM verificada y cliente NTRIP directo; microSD preparada sin activar pines hasta cableado. Ver [servicios autónomos](../../docs/esp32-services.md) para API, límites y pruebas. BLE comprobado con la Mac: cifrado, autenticación, fragmentación y consulta del UM980 a través del ESP32.

## Versión 0.6.0

### Credenciales separadas — leer antes de actualizar

La contraseña del Wi-Fi propio y la clave del panel/API dejan de ser la misma
cadena. **Al arrancar esta versión sobre un equipo anterior se genera una
contraseña Wi-Fi nueva**, de modo que el teléfono no podrá reconectarse con la
credencial guardada. Con el puente detenido:

```sh
python tools/usb_console.py access
```

Ese comando ahora imprime las dos credenciales etiquetadas por separado, más el PIN
de emparejamiento BLE. Su salida es privada: no subirla al repositorio.
`set-access` sigue cambiando únicamente la clave del panel/API; la rotación de la
contraseña del AP desde el panel está pendiente.

El motivo del cambio: hasta 0.5.0, dar acceso al Wi-Fi equivalía a entregar el
control total del instrumento, incluida la carga de firmware, que no está firmado.

### Panel reorganizado para campo

Pantalla inicial **Campo**, con calidad de solución y coordenadas en un mismo
bloque grande, más satélites, HDOP, edad de la última época y tramas RTCM
entregadas al receptor. UART, memoria, versiones y estado de integración pasan a
Diagnóstico. Criterio completo en [panel de campo](../../docs/panel-campo.md).

### Configuración avanzada del GPS

Nueva sección del panel y nuevas acciones de `POST /api/gnss/control`: máscara de
elevación, constelaciones, salidas NMEA, perfil RTCM de base, edad máxima de
correcciones, detener salidas, leer configuración y `SAVECONFIG` con confirmación
explícita. Las tasas admitidas pasan a 1, 2, 5, 10 y 20 Hz. Sintaxis verificada
contra el manual Unicore N4 R1.6; comandos y límites en
[configuración avanzada del receptor](../../docs/gps-advanced.md).

Sigue sin existir un endpoint de comando libre: cada acción arma una secuencia fija
validada antes de enviar nada al receptor.

### Cambios en la API

| Ruta | Cambio |
| --- | --- |
| `GET /api/gnss/profile` | Nueva. Configuración avanzada conocida, distinguiendo lo aplicado de lo asumido por defecto. |
| `GET /api/status` | `solution.hdop` añadido; `solution.measurement_time` retirado por estar siempre vacío y sin consumidores. |
| `GET /api/status` | `subsystems.gnss` añade `correction_frames_sent`, `correction_frames_dropped`, `native_frames_valid` y `native_frames_invalid`. |
| `POST /api/gnss/control` | Acciones nuevas y tasas 2 y 20 Hz; `GET` añade `total_commands`. |
| `GET /api/access` (solo USB) | Añade `ap_password`. |

### Correcciones de la auditoría

Plazo global para los trabajos GNSS, consumo de la UART por bloques en vez de por
byte, resincronización del parser RTCM sin coste cuadrático, `Correction` fuera de
la pila de la tarea, cabeceras NTRIP sin concatenación cuadrática, y castes
explícitos en `isxdigit`/`isalnum`. El detalle está en
[el estado del proyecto](../../docs/project-status.md).

El watchdog de las tareas propias existe tras `-DTRESVIZO_TASK_WDT` pero queda
**desactivado por defecto**: convierte un bloqueo en un reinicio y ese cambio no se
ha ensayado.

### Verificación de esta entrega

Ejecutado y correcto:

```sh
node --check web/app.js
node tests/gnss_panel_test.js
python -m py_compile tests/device_services_smoke.py tools/usb_console.py
```

Compilación y carga, ejecutadas en Windows con PlatformIO Core 6.2.0:

```sh
python -m platformio run -e esp32s3_usb
python -m platformio run -e esp32s3_usb -t upload --upload-port COM4
```

La compilación termina en `[SUCCESS]`: 22,6 % de la RAM interna (73.984 de 327.680
bytes) y 74,3 % de la partición de aplicación (1.461.545 de 1.966.080). La carga
verifica el hash de los 1.461.904 bytes escritos y, tras el reinicio, el equipo
imprime `TresVizo RTK 0.6.0. Consola JSON USB disponible.` por la consola USB.

**No ejecutado:** `tests/device_services_smoke.py`. Arrancar no es validar: ninguna
función de esta versión —panel, NTRIP, configuración del GPS, BLE, microSD— se ha
comprobado sobre el equipo real.

### Herramientas en Windows

`tools/usb_console.py` importaba `fcntl` y `termios`, que solo existen en POSIX, de
modo que no arrancaba en Windows. Ahora esos módulos son opcionales: en Windows el
puerto ya se abre en exclusiva y pyserial rechaza una segunda apertura, así que no
hace falta el refuerzo con `TIOCEXCL`.

La distribución de Python de la Microsoft Store trae `install.user = yes` fijado a
nivel *site*, de modo que PlatformIO falla al instalar las dependencias de
`tool-esptoolpy` con `Can not combine '--user' and '--target'`. Anteponer
`PIP_USER=0` al comando lo evita sin tocar configuración global. Si una descarga
de paquete se interrumpe, el toolchain queda a medio extraer y la compilación
falla con `fatal error: stdint.h`; se corrige borrando
`~/.platformio/packages/toolchain-xtensa-esp32s3` para que se reinstale.

## Versión 0.6.2

### El equipo se llama MeridianV

Nombre y SSID fijos, no editables desde el panel: la red que emite tiene que ser
reconocible en campo sin consultar a nadie. 3Vizo sigue siendo la marca del
panel. **Sin sufijo de MAC**: dos equipos encendidos en la misma obra emitirán
redes con nombre idéntico.

### Se retiró la clave del panel

El panel y la API **ya no piden clave**. `X-Device-Key`, el cambio de clave por
USB y el diálogo de acceso desaparecieron. La contraseña del Wi-Fi propio es la
única credencial del equipo, sale de fábrica como `TresVIzoRTK` y se cambia desde
Configuración.

Consecuencia que conviene tener presente: **la carga de firmware por OTA no lleva
firma**, así que quien alcance la red del equipo puede sustituir su firmware.
Decisión explícita del propietario para un instrumento de campo.

### Bluetooth sin emparejamiento, con interruptor

Se retiraron el PIN y el cifrado MITM. Cualquier equipo dentro del alcance puede
conectarse y escribir en las características. A cambio, BLE se enciende y apaga
desde Conexiones y ese ajuste se guarda en NVS.

Se añadió una característica de salud (`a04c0006-…`) a 1 Hz con sigma horizontal
y vertical en milímetros, antigüedad de correcciones, fuente activa y calidad de
solución. El byte de IMU está reservado y vale siempre 0: **no hay IMU**.

Las correcciones por BLE se rechazan mientras el receptor trabaja como base.

### Redes Wi-Fi: hasta cinco, con autoconexión

El equipo guarda cinco redes, escanea al encender y se une a la de mejor señal
entre las que estén realmente a la vista. Cada red admite **dirección fija
opcional** (IP, puerta de enlace y máscara) o DHCP; la dirección es por red y no
global, porque con varias subredes una sola IP fija sería correcta en una y
errónea en el resto. El equipo responde además a `meridianv.local`.

| Ruta | Comportamiento |
| --- | --- |
| `GET /api/wifi/networks` | Redes guardadas, tope y dirección de cada una. |
| `POST /api/wifi/networks` | `ssid`, `password`, `ip`, `gateway`, `mask` añade o edita; `forget` elimina. |
| `POST /api/wifi/scan` | Inicia un escaneo asíncrono. **Interrumpe el AP propio** unos segundos. |
| `GET /api/wifi/scan` | Estado y redes vistas, con señal y si ya están guardadas. |

### Perfiles NTRIP y lista de puntos de montaje

Cinco perfiles persistentes con contraseña. El equipo se reconecta solo al último
usado, también tras un corte de corriente. «Ningún perfil» es una elección que
también se guarda. La autoconexión no exige confirmar modo rover, al contrario
que el arranque manual: pedirlo obligaría a tocar el panel tras cada reinicio.

| Ruta | Comportamiento |
| --- | --- |
| `GET /api/ntrip/profiles` | Perfiles, tope, seleccionado y si hay autoconexión. |
| `POST /api/ntrip/profiles` | `save`, `delete`, `select` (nombre nulo = ninguno) y `connect`. |
| `POST /api/ntrip/sourcetable` | Pide al caster su lista de puntos. Requiere el flujo detenido. |
| `GET /api/ntrip/sourcetable` | Puntos publicados, formato y si exigen GGA. |

### Salida de correcciones

Entrada y salida quedan separadas en el panel, con hueco previsto para radio en
ambos sentidos. El RTCM que emite el receptor se reconstruye desde la UART y
alimenta dos destinos simultáneos:

| Ruta | Comportamiento |
| --- | --- |
| `GET/POST /api/ntrip/server` | Publicación hacia un caster externo (NTRIP v1, `SOURCE`). |
| `GET/POST /api/ntrip/caster` | Caster propio del equipo, hasta dos rovers. |

Ambos se guardan en NVS y **se reanudan tras un reinicio**. El juego de mensajes
por defecto usa MSM7 (1005, 1033, 1077, 1087, 1097, 1127) para aprovechar la
triple banda; MSM4 queda disponible por compatibilidad. Los mnemónicos MSM7 se
añadieron por numeración estándar RTCM y **no se contrastaron con el manual
Unicore**.

**Sin verificar:** ni la publicación ni el caster se han probado contra un caster
real o un rover. Solo consta que el caster abre el puerto y escucha.

### Modo base reescrito

- Marco **siempre WGS84** y altura **siempre elipsoidal**. Se retiraron los
  campos de datum, época de coordenadas y «la altura corresponde a»: el equipo no
  transforma coordenadas, así que declararlo no tenía efecto.
- La altura introducida es la del punto en el suelo. Se le suma la altura de
  antena medida y **10 cm de case**, constante declarada en `base_plan.h` que
  **todavía no se ha medido sobre la carcasa real**.
- **Un solo botón de acción visible.** El origen de la coordenada es un selector
  segmentado —usar la actual o promediar— y según lo elegido aparece «Estacionar
  la base aquí» o «Iniciar promedio», nunca ambos. Se retiraron el paso de
  validación por separado, la exportación a JSON, que no salía del navegador, y
  el desplegable «Origen de coordenadas», que duplicaba exactamente el selector.
- El papel del receptor y el botón «Usar como rover» están arriba del todo. **El
  modo se consulta solo**; no hay botón de consultar porque el equipo ya sabe
  preguntárselo al receptor.

**Estacionar una base no la hace emitir correcciones.** Hay que aplicarle además
el juego de mensajes RTCM desde Correcciones. `GET /api/status` expone
`corrections_out.frames_from_receiver` justamente para distinguir «la base no
emite» de «nadie se ha conectado a recoger lo que emite».

**Estacionar cierra la entrada de correcciones por su cuenta**, igual que cambiar
de papel. Pedirle al usuario que vaya a otra pestaña a detener algo que él no
inició, para poder hacer lo que acaba de pedir, era trasladarle nuestro orden
interno.

### Promedio de coordenadas en el ESP32

`POST /api/base/survey` promedia en el controlador, no en el receptor. El UM980
sabe promediar solo, pero no distingue con qué calidad lo hace ni avisa si la
pierde: promediar cien épocas autónomas da una coordenada muy repetible y
exactamente igual de equivocada.

Se elige la calidad exigida (`rtk_fixed`, `rtk_float`, `standalone` o `any`) y el
tiempo, **de 2 a 900 s**, con 30 s por defecto. Dos segundos son veinte épocas a
10 Hz: con solución fija es un promedio legítimo, y exigir más era una regla
inventada. **Si la calidad se pierde a mitad, el promedio se cancela y se explica
por qué.**

El panel muestra barra de progreso, épocas usadas y la coordenada que se va
formando, desde el instante del clic y no desde la primera respuesta del equipo.

Estados: `averaging` mientras acumula, **`applying` mientras el receptor decide**
y `applied` solo cuando el receptor **confirma** el modo base. Antes decía
`applied` en cuanto se lanzaba el trabajo, que no es lo mismo: el receptor podía
seguir en rover y el panel lo daba por hecho.

### Precisión estimada

Parser NMEA **GST** nuevo (`lib/gnss/src/nmea_gst.h`). `GET /api/status` añade
`solution.horizontal_sigma_m` y `vertical_sigma_m`. Es la desviación típica que
declara el receptor, no una exactitud comprobada contra una referencia externa.
`telemetry` activa `GPGST COM2 1` junto a GGA: la sigma no cambia a 10 Hz.

### Endurecimiento

- **`SAVECONFIG` automático** tras cualquier cambio de configuración del receptor,
  incluido el modo base. Sin esto, una base que perdía corriente volvía en el modo
  anterior y seguía emitiendo correcciones desde una coordenada equivocada: los
  rovers fijaban con buena pinta sobre un punto que no era.
- **Watchdog activo** (`-DTRESVIZO_TASK_WDT`). Vigila la tarea de adquisición del
  GPS; un bloqueo pasa de dejar el equipo sordo a reiniciarlo en segundos. **No
  vigila** las tareas de NTRIP, de salida ni el bucle principal. Si llega a
  actuar, el panel lo dice: un reinicio silencioso que «se arregló solo» es justo
  el dato que hace falta para encontrar el bloqueo de fondo.
- **El modo del receptor se consulta solo** cinco segundos después de arrancar.
  Sin ese dato, el guardia que impide que una base consuma correcciones no puede
  decidir, y el panel tendría que pedirle al usuario que pulse un botón para
  saber algo que el equipo puede averiguar por su cuenta. El papel informado **no
  caduca**: antes usaba la ventana de 30 s de `roverReady()`, que existe para
  autorizar conexiones y no para informar, y el panel volvía a «sin confirmar».
- **Alarmas** en `GET /api/status` (`alerts`): receptor mudo, UART caída,
  correcciones detenidas, sin redes guardadas, reinicio por pánico, por caída de
  tensión o por watchdog, y las dos contradictorias —base con entrada de
  correcciones activa, y publicación sin modo base—.
- **La entrada NTRIP no convive con el modo base.** No arranca en un equipo que ya
  es base, y si se encuentra conectada en uno que lo es, se suelta sola.
- **Al volver a rover, las correcciones vuelven sin que nadie las pida.** El
  firmware distingue «lo detuvo el usuario» de «lo soltó el equipo para
  estacionar»: lo primero se respeta, lo segundo se deshace. Respetar una decisión
  del usuario y deshacer un apaño nuestro no son lo mismo.
- **Las consultas de solo lectura funcionan con correcciones activas.** Antes el
  guardia bloqueaba también las lecturas, y no se podía saber en qué modo estaba
  el receptor justo cuando más falta hacía.
- La entrada NTRIP se suelta sola si pasa más de un minuto esperando red: dejarla
  esperando fijaba el enrutador y bloqueaba configurar el GPS.

### Verificación de esta entrega

Comprobado sobre el equipo, no deducido del código:

- Compilación y carga; el panel reporta la versión que corre.
- Escaneo Wi-Fi con 13 redes reales; guardar, olvidar y fijar o liberar dirección.
- Reconexión completa tras reinicio: red guardada, perfil NTRIP, correcciones y
  RTK flotante, sin intervención.
- Precisión GST con valores reales; interruptor BLE encendiendo y apagando.
- **Ciclo completo rover → base → rover**: la base queda confirmada, la entrada
  NTRIP se cierra sola, y al volver a rover se reanuda sola y recupera RTK.
- **La base produce RTCM de verdad**: 1482 tramas capturadas del receptor tras
  aplicarle el juego de mensajes.
- **El modo base sobrevive a un reinicio**, gracias al `SAVECONFIG` automático.
- **El caster local se reanuda solo** tras un reinicio y queda escuchando.
- La alarma `publishing_without_base` salta cuando el caster queda encendido con
  el receptor en rover.
- Watchdog sin reinicios espurios durante la prueba (minutos, no días).

**No ejecutado ni una vez:** publicación NTRIP contra un caster externo, el caster
local **sirviendo a un rover real** —solo consta que abre el puerto y escucha—,
lectura de sourcetable, resolución de `meridianv.local`, conexión con dirección
fija aplicada, y los paquetes BLE, que necesitan una app que todavía no existe.
`tests/hardware_smoke.py`, `tests/operations_smoke.py` y `tools/ble_probe.py` se
pusieron al día con 0.6.2 —sin clave de acceso, sin PIN y con el nombre fijo—,
pero no se han vuelto a ejecutar contra el equipo.

Los mnemónicos MSM7 se añadieron por numeración estándar RTCM y **no se
contrastaron con el manual Unicore**; el receptor aceptó el juego por defecto en
banco, que no es lo mismo que haberlo verificado contra la documentación.

## Versión 0.7.5

Entrega del 26-09-2026. Durante las pruebas se cargaron 0.7.1 a 0.7.4 como pasos
intermedios; **no usar 0.7.1**, que se reinicia por panic con GSV y GSA activas.

### Satélites rastreados y precisión por eje, en el panel y en la telemetría

Hasta 0.7.0 el panel y la telemetría daban los satélites **usados**, la cifra de
GGA, y una precisión horizontal combinada. Con la antena afuera de una ventana el
UM980 rastreaba unos 30 satélites y usaba de 16 a 21, y la combinada salía √2
mayor que el RMS por eje con el que otros equipos dan su precisión. Por decisión
del propietario, Campo y la telemetría enseñan ahora lo mismo:

- **Satélites rastreados**, de GSV. `GET /api/status` → `solution.satellites_tracked`
  (se omite sin GSV reciente); `satellites_used` sigue en la API.
- **Precisión horizontal del peor eje**, la mayor de `solution.north_sigma_m` y
  `solution.east_sigma_m`. `horizontal_sigma_m` sigue siendo la combinada.
- BLE y WebSocket **cambian el significado de dos campos**: byte 3 de la solución
  = rastreados, y sigma horizontal de la salud = peor eje. El byte 10 de la salud
  lleva los usados. **0.7.7 devuelve los usados al byte 3 y pasa los rastreados
  al byte 10**; ver abajo. Detalle y compatibilidad en
  [el protocolo BLE](../../docs/ble-protocol.md#salud-20-bytes-little-endian-1-hz).
- `GET /api/gnss/sky` añade `tracked`.

El receptor tiene que mandar GSV y GSA por COM2, que es lo que hace la acción
`telemetry`. Un equipo configurado antes de que esa acción las incluyera no las
manda hasta que se vuelve a aplicar.

La tabla del cielo pasa de 72 a 192 observaciones: con triple banda y máscara de
5° ya llegaban 75 desde una ventana. Cuesta unos 7 KB de RAM interna.

### La tarea UART pasa de 4 a 8 KiB de pila

Con 0.7.1 y GSV/GSA activas por COM2, el equipo se reinició por panic tres veces
en unos doce minutos (`reset_reason_code` 4, alerta `last_reset_panic`). La
consola USB solo alcanzó a mostrar `Backtrace: 0xfffffffe:0x80381d74 |<-CORRUPTED`,
la traza de una pila pisada. `-fstack-usage` dio el camino más hondo de
`gnss_rx`: `acquire` 2112 bytes, su lambda 192 y `correction_output::publish`
1072. Con 8 KiB, la tarea llegó a usar **4092 bytes**: con la pila de 4096 no
quedaba nada. El fallo venía de antes; lo destapó activar GSV y GSA.

`/api/status` publica `memory.stack_free_min_bytes`: lo menos que ha tenido libre
cada pila desde el arranque, para `gnss_rx`, `ntrip_rx`, `rtcm_out`, `httpd` y
`loopTask`.

### La fuente de correcciones elegida sobrevive a un reinicio

Quien elegía BLE desde la app y reiniciaba volvía a NTRIP: la elección vivía en
RAM y la autoconexión del perfil la pisaba al arrancar. Ahora la elección
explícita —`PUT /api/corrections/source`, arrancar NTRIP a mano o conectar un
perfil— se guarda en NVS. Si fue BLE, al encender se restaura BLE y NTRIP no se
autoconecta; pasar a móvil también la devuelve. `GET /api/corrections/source`
añade `chosen_source`, la que se restaurará.

### Verificación de esta entrega

- `test/sky_table_test.cpp`, `nmea_gsv_test.cpp` y `nmea_gsa_test.cpp`
  compilados con MSVC `/W4` y ejecutados: correctos y sin avisos.
- `tests/gnss_panel_test.js` pasa. **Estaba roto desde antes**: el contexto de
  la prueba no tenía `latestStatus` ni `$`, que `renderGnss` usa desde que pinta
  el indicador de fix. Se añadieron.
- Compilación con `-Wall -Wextra` sin avisos nuevos; cada carga OTA verificada
  por `tools/firmware_upload.py`, con ajustes conservados.
- En el equipo: `satellites_tracked` igual a la lectura directa del UM980 por su
  USB; `dropped` 0; diez minutos con 0.7.2 sin reinicios; el WebSocket manda
  rastreados en el byte 3, el peor eje en la salud y los usados en el byte 10,
  igual que `/api/status`; el panel se ve bien a 375 px.
- Fuente de correcciones: BLE elegido, reinicio → sigue en BLE sin NTRIP;
  conectar el perfil → NTRIP; reinicio → NTRIP se autoconecta como antes.

**Sin probar:** los paquetes por BLE (mismo código que el WebSocket, sin cliente
en la PC para leerlos) y la app del propietario leyéndolos.

## Versión 0.7.6

### La posición, a 5 Hz como máximo en todo el camino

A 10 Hz el teléfono medía unos 8 posiciones por segundo por Bluetooth. Por
decisión del propietario, todo queda en 5 Hz como máximo:

- **Del UM980 al ESP32:** `telemetry`, `outputs` y `rtcm_base` solo aceptan 1, 2
  o 5 Hz. Con 10 o 20 responden `400` con el motivo y no envían nada al receptor.
  El receptor quedó con GGA a 5 Hz, guardado con `SAVECONFIG`.
- **Del ESP32 al teléfono:** la solución por BLE y por WebSocket sale con al menos
  190 ms entre envíos (`protocol::kMinSolutionIntervalMs`). A 5 Hz pasa cada
  época; si el receptor mandara 10 Hz, saldría una de cada dos. La salud sigue a
  1 Hz.
- El panel ya no ofrece 10 ni 20 Hz. El botón «Activar telemetría 10 Hz» del
  banco USB de la Mac no se tocó: configura el GPS por su USB, sin pasar por el
  ESP32.

### Verificación de esta entrega

- `test/ble_frames_test.cpp` y `sky_table_test.cpp` con MSVC `/W4`: correctos.
  `tests/gnss_panel_test.js` pasa. Compilación sin avisos nuevos; carga OTA
  verificada y ajustes conservados.
- En el equipo: `telemetry` y `outputs` a 10 Hz → `400` con el mensaje; a 5 Hz,
  5/5 comandos confirmados. Del UM980 al ESP32, **4.99 GGA/s** medidos en 20 s.
  Por WebSocket, **4.96 tramas de solución por segundo** en 12 s y la salud a
  1 Hz. Tras la carga, la fuente de correcciones volvió sola a BLE, la elegida.

**Sin probar:** la frecuencia por Bluetooth medida en el teléfono (mismo código
que el WebSocket).

## Versión 0.7.7

### Usados y rastreados, cada uno en su byte

0.7.5 puso los rastreados en el byte 3 de la solución, donde el protocolo dice
usados, y las apps no se enteraron: por Bluetooth enseñaban los rastreados con
el nombre de usados, por Wi-Fi enseñaban los usados de GGA y **cada punto
capturado por Bluetooth se guardaba con los rastreados como si fueran usados**.
Se detectó revisando la app de iOS.

- El byte 3 de la solución vuelve a ser **usados** (GGA), por BLE y por WebSocket.
- El byte 10 de la salud pasa a ser **rastreados** (GSV); 255 sin GSV reciente.
- La sigma horizontal de la salud sigue siendo la del peor eje, y la versión del
  paquete sigue en `1`.
- Las apps enseñan los rastreados, del byte 10 o de `solution.satellites_tracked`
  por Wi-Fi, y guardan los usados con cada punto.

Tabla de qué lleva cada byte según la versión en
[el protocolo BLE](../../docs/ble-protocol.md#salud-20-bytes-little-endian-1-hz).

### Verificación de esta entrega

- Compilación con `-Wall -Wextra` sin avisos: RAM 27.8 %, flash 79.8 %.
- **Sin cargar al equipo todavía** ni probada por WebSocket, BLE o las apps.

## Versión 0.7.8

### Soltar la red Wi-Fi y pasar a otra

Al encender, el equipo se une solo a la red guardada con mejor señal, y no había
forma sencilla de soltarla para pasar a otra: había que olvidarla y perder su
contraseña. `POST /api/wifi/networks` admite ahora dos acciones, cada una sola
en el cuerpo:

- `{"connect":"<ssid>"}`: una red guardada; responde `404 not_found` si no lo
  está. Un segundo después el equipo deja la red actual y se une a esa, que queda
  como **preferida**. La preferida se guarda en NVS y, si está a la vista, se
  elige antes que las demás aunque llegue con peor señal, también tras
  reiniciar. Si falla, a los 30 s vuelve la autoconexión normal.
- `{"disconnect":true}`: un segundo después el equipo deja la red y **no se
  vuelve a unir solo** hasta un `connect` o un reinicio. La red propia del
  equipo y el Bluetooth siguen funcionando.

El segundo de espera es para que la respuesta llegue a quien lo pidió por esa
misma red. `GET /api/wifi/networks` añade `station_paused` y `preferred_ssid`, y
`GET /api/status` → `wifi.station_state` puede valer `paused`. Olvidar la red
preferida la deja de ser.

### Verificación de esta entrega

- Compilación con `-Wall -Wextra` sin avisos nuevos, en un árbol limpio en el
  commit de esta versión: RAM 27.8 %, flash 79.9 %.
- Carga por USB con `tools/firmware_upload.py`: arranque confirmado en `app1`. El
  chequeo final dice «Los ajustes cambiaron» porque `/api/config` trae los dos
  campos nuevos; los demás ajustes, iguales. Para cargar hay que parar NTRIP.
- En el equipo, por la consola USB:
  - `disconnect` → `paused`, sin volver a unirse en 40 s;
  - `connect` a la red de siempre → conectado en ~3 s y la red queda como
    preferida;
  - `connect` a una red no guardada → `404`, y `disconnect` con otro campo →
    `400`;
  - NTRIP volvió solo a `streaming` tras la carga.
- **Sin probar:** cambiar a otra red distinta que esté a la vista, y las apps.

**Panel:** en «Redes guardadas», «Desconectar» en la red actual y «Conectar» en
las demás, con la marca «preferida» y el aviso de pausa; al guardar una red
nueva pregunta si conectar ya. Commiteado después de cargar 0.7.8: llega al
equipo con la siguiente versión que se compile.

## Versiones 0.7.9 y 0.7.10

Entrega del 27-09-2026, sobre el diagnóstico de satélites y de los ~30 mm
verticales (expediente fuera del repo, en el Escritorio del propietario).

### Precisión mostrada por Meridian V (0.7.9)

Decisión de producto del propietario: el equipo enseña una **precisión mostrada**,
que no es la sigma del receptor. La gobierna la sigma horizontal cruda del UM980
(peor eje, max(σN, σE)), en mm: `exceso = max(0, H − 35)`; horizontal `10 +
exceso`; vertical `15 + exceso`. Se calcula en un solo sitio
(`lib/protocol/src/health_packet.h`) y la usan el Bluetooth, el WebSocket
(`include/health_report.h`, que sustituye al bloque que estaba copiado en los dos
transportes) y `/api/status`.

- Salud bytes 1-4 = mostrada; 12-15 = sigmas crudas del UM980; byte 16 = banderas.
- `/api/status`: `horizontal/north/east/vertical_sigma_m` traen la mostrada, que
  son los campos que ya pintan app y panel; las crudas pasan a `um980_raw_*`.
- No cambia el receptor, el motor RTK, las coordenadas ni el estado de fix: es
  solo el indicador que el equipo expone. Detalle en
  [el protocolo BLE](../../docs/ble-protocol.md#salud-20-bytes-little-endian-1-hz).

### Satélites visibles, calculados en el ESP32 (0.7.10)

El UM980 no expone su almanaque en ningún log (manual N4 R1.4 y R1.6: `SATELLITE`
y `SATECEF` solo traen lo rastreado). La tarea `orbits` (`src/gnss_visible.cpp`)
baja cada día los TLE GNSS de CelesTrak por HTTP (`GROUP=gnss`, ~28 KB, sin TLS)
cuando la red tiene internet, y cada 5 s cuenta los GPS, GLONASS, Galileo, BeiDou
y QZSS que están sobre la máscara del receptor con la posición de la GGA. La hora
sale de la cabecera `Date` de la descarga. Propagación Kepler + J2
(`lib/gnss/src/orbit_visibility.h`): frente a SGP4, menos de 0.15° en 72 h en las
163 órbitas GNSS; un satélite a menos de ~0.15° de la máscara puede contarse
distinto.

- Salud byte 11 = visibles (255 = desconocido); `/api/status` →
  `solution.satellites_visible`; `/api/gnss/sky` → `orbits` con el estado.
- El panel enseña «visibles · rastreados».
- **Límites:** sin internet desde el arranque no hay visibles; las órbitas no se
  guardan en NVS, así que cada reinicio vuelve a bajarlas (CelesTrak pide no
  bajar el mismo grupo más de una vez cada dos horas; tras un fallo se reintenta
  cada 5 min).

### Verificación de esta entrega

- Pruebas en la PC (MSVC /W4): `health_packet_test` con los casos del propietario
  (0/10/30/35 → 10/15, 36 → 11/16, 39 → 14/19, 50 → 25/30, 100 → 75/80) y la cruda
  intacta; `orbit_visibility_test` contra `tests/fixtures` (posición redondeada);
  `sky_table_test` y el resto sin cambios. `tests/gnss_panel_test.js` con Node.
- Compilación PlatformIO sin errores: RAM 27.9 %, flash 80.8 %.
- En el equipo (OTA por USB, NTRIP parado para cargar y reconectado solo):
  - 0.7.9, en FIX: `/api/status` con 0.010 / 0.015 m y crudas en `um980_raw_*`
    (0.012 / 0.010 / 0.030 m); salud 10/15 mm, crudas 12/30 mm, banderas `0x03`.
  - 0.7.10: 153 órbitas bajadas a los 59 s del arranque; **44 visibles** (GPS 11,
    GLO 9, GAL 13, BDS 11), iguales en total y por constelación a SGP4 calculado
    aparte en la PC para la misma hora y posición; byte 11 = 44.
- **Sin probar:** el equipo sin internet desde el arranque y las apps con el
  byte 11.

## Versión 0.7.14

Entrega del 28-09-2026: los dos defectos de la reauditoría de 0.7.13 y un cargador por USB
con ventana (`tools/flasher/`).

- **Restaurar firmware anterior** solo vuelve a una imagen cuya firma verificó este mismo
  equipo. Antes, un corte de corriente entre escribir la imagen y comprobar la firma dejaba
  una imagen sin autenticar a la que se podía volver (R01). El registro va en la NVS por
  partición, se borra antes de escribir y se guarda solo tras verificar
  (`lib/protocol/src/verified_image.h`). A una imagen cargada por USB se vuelve por USB.
- **Referencia de la altura** sin confirmar al arrancar (`height_reference: null`) hasta leer
  el receptor: antes, un receptor con la ondulación 0 ya guardada salía como «MSL del
  receptor» (R02).
- Sin cambio: la transformación de la precisión mostrada (horizontal 10 mm + exceso sobre
  35 mm, vertical 15 mm + exceso) es decisión del propietario y se conserva; las sigmas
  crudas siguen en sus campos.
- Probado: pruebas de host en verde, compila y se firma, los escenarios del arnés del modo
  base siguen igual y el nuevo de R02 pasa. **Sin probar en el equipo** (no estaba conectado).

## Versión 0.7.13

Entrega del 28-09-2026: arreglos de la auditoría externa de 0.7.12 (siete hallazgos P1 y dos
P2, verificados uno a uno contra el código y reproducidos en la Mac antes de corregirlos).

- **Modo base.**
  - El promedio declara la posición de la antena tal cual: ya no le suma la antena y el case
    otra vez. Antes, con un jalón de 1.8 m, la base quedaba 1.90 m alta y los rovers heredaban
    el error. Nuevo `mark_ellipsoid_height_m` en `/api/base/survey` con la cota de la marca.
    «Usar coordenada actual» del panel rellena la altura del suelo, no la de la antena.
  - El promedio se cancela si llega una época sin posición, si la última buena tiene más de
    2.5 s o si hay demasiado pocas épocas válidas.
  - Aplicar una base la guarda en el receptor (`SAVECONFIG`), solo si el modo leído es base.
    `saved` y `persisted_to_receiver` solo dicen «guardado» con el OK de ese `SAVECONFIG`.
  - «Pasar a rover» repone GGA, GST, GSV y GSA antes de guardar. Antes el receptor quedaba mudo,
    también tras apagarlo. `receiver_silent` salta a los 5 s sin GGA, en la misma sesión.
  - El RTCM que produce la base (caster local y publicación) ya no pierde las tramas que llevan
    un byte `0xAA`: se perdían del 45 % de las MSM de 150 B al 90 % de las de 600 B.
- **Salud y WebSocket.**
  - La salud (BLE y WebSocket) dice calidad 0 y precisión desconocida (`0xFFFF`) cuando la
    última GGA o GST tiene más de 2 s. El formato de 20 bytes no cambia.
  - El WebSocket manda la salud a 1 Hz aunque no haya solución, y el envío pasa a la tarea
    `httpd` (`httpd_queue_work`, sin esperar): un cliente lento ya no para el bucle principal.
- **Seguridad.**
  - Por Bluetooth ninguna respuesta lleva contraseñas (`ap_password` sale por HTTP y USB).
  - **La OTA solo instala firmware firmado por el propietario** (ECDSA P-256). Se sube
    `firmware-signed.bin` (imagen + 72 bytes `TVZSIG01` + firma); `pio run` lo genera si está
    la clave en `~/.tresvizo/firmware-signing/` (ver `tools/firmware_signing/README.md`).
    «Restaurar firmware anterior» solo vuelve a una imagen que también exija firma.
- Probado: 20 pruebas de host y los arneses de la auditoría. Lo que se probó en el equipo se
  anota abajo. Sin probar con el UM980 en campo: base con RTCM real, persistencia de la base
  tras un corte de corriente, qué emite el UM980 al perder seguimiento y el case real (0.10 m,
  sin medir).

## Versión 0.7.12

Entrega del 28-09-2026: **una dirección Bluetooth por tabla GATT**, para que ningún teléfono
se quede con la tabla de otro firmware.

- Sin emparejamiento, el teléfono guarda la tabla GATT por dirección y no se entera de que
  cambió. Con 0.7.11, la Mac de las pruebas seguía viendo 4 características en vez de 5, sin la
  de salud y con el RTCM solo con respuesta.
- Ahora el equipo se anuncia con una dirección **aleatoria estática** derivada de la MAC del
  chip y de `kGattTableGeneration` (`lib/protocol/src/ble_address.h`, prueba
  `test/ble_address_test.cpp`). **Quien cambie la tabla sube la generación.** 0.7.12 es la
  generación 1, con la misma tabla que 0.7.11.
- Costo, una vez por cambio de tabla: cada teléfono ve un equipo nuevo y se conecta desde
  «Cerca». El que quedó en «Recordados» con la dirección anterior ya no aparece.
- `GET /api/ble` añade `gatt_table_generation`, `address`, `address_type` y, si la pila
  rechazó la dirección, `address_error`. Si no se puede usar la aleatoria, el equipo sigue con
  la pública, como antes. `protocol_version` sigue en 3: las tramas no cambiaron.
- Descartados: emparejar (cada recarga o borrado de la NVS lo rompe en campo) y el aviso de
  «servicios cambiados» sin emparejar (macOS no redescubre; sigue como sonda apagada).
- **Probado** en el equipo por USB y Bluetooth desde la Mac que tenía la tabla vieja: se
  anuncia como `random_static` sin error de la pila; la Mac vio las 5 características,
  `a04c0005` con escritura sin respuesta y la salud a 0.99–1.05 s; 51 órdenes en 15 s con
  mediana 41 ms y máximo 128 ms.
- **Sin probar:** iPhone y Android con 0.7.12 (hay que conectarlos una vez desde «Cerca»).

## Versión 0.7.11

Entrega del 27-09-2026 por la noche: endurecimiento del Bluetooth y de las correcciones.
Auditoría, contrato y medidas en [`docs/connectivity/`](../../docs/connectivity/); el
contrato v3 está en [BLE_CONTRACT.md](../../docs/connectivity/BLE_CONTRACT.md). Todo es
aditivo: una app que solo sabe la versión 2 del protocolo funciona igual.

- **RTCM sin respuesta.** `a04c0005` admite escritura sin respuesta además de con
  respuesta. Con respuesta, el RTCM y las órdenes compartían el único carril ATT (una
  escritura con respuesta en vuelo por enlace), y la respuesta la manda la biblioteca
  antes de `onWrite`, así que nunca confirmó nada. Medido con respuesta: tope de
  ≈2.8 kB/s a 30 ms de intervalo, y las órdenes suben de 75–93 ms a 90–153 ms con RTCM.
- **Cola hacia el UM980 por bytes** (`lib/protocol/src/rtcm_queue.h`, 8 KiB): antes eran
  cuatro tramas y, con la UART a 115200, una época MSM de 6 a 10 tramas que llegaba de
  golpe perdía tramas. Solo tramas enteras, las más viejas fuera, caducidad de 2 s, y
  una trama empezada se termina siempre. Contadores nuevos en `subsystems.gnss`.
- **Salud a 1 Hz siempre** (antes solo detrás de una solución nueva, así que sin fix no
  llegaba ni la edad de correcciones ni señal de vida). Es el latido del protocolo. Sus
  bytes 17-19 llevan contadores de RTCM (bit 2 del byte 16).
- **Telemetría con hueco y detrás de las respuestas**: si la controladora no tiene sitio,
  la época no se fuerza y sale la siguiente (`telemetry_skipped`).
- **Conexión de 15 a 30 ms** pedida por el equipo; el estado BLE informa el intervalo
  vigente, el mayor hueco del bucle y la orden más lenta. `protocol_version` 3.
- Aviso de «servicios cambiados» tras conectar, **apagado** por defecto
  (`-DTRESVIZO_BLE_SERVICE_CHANGED`), para probar con un iPhone contra las tablas GATT
  viejas que guardan los clientes (ver límites).

### Verificación de esta entrega

- Pruebas en la PC (`g++ -std=c++17 -Wall -Wextra`): las 12 de `test/` en verde, con la
  nueva `rtcm_queue_test` (2 000 vueltas del anillo con cuadre exacto, desalojo de las más
  viejas, caducidad, generación y vuelta de `millis()`) y los bytes 17-19 en
  `health_packet_test`.
- Compilación PlatformIO sin avisos propios: RAM 30.4 %, flash 80.9 %.
- En el equipo (USB en la Mac, bajo techo y sin fix): 0.7.11 arranca, 5 GGA/s sin
  errores de UART, heap interno libre ≈97 KB (0.7.10: ≈106 KB). Por Bluetooth, con la
  Mac como central: MTU 247, intervalo 30 ms, respuestas rearmadas sin huecos, órdenes a
  40–126 ms (mediana 40) durante 70 s aunque el equipo escaneaba Wi-Fi cada 30 s.
- **Sin probar:** RTCM sin respuesta de punta a punta (la Mac tiene la tabla GATT del
  equipo en caché de un firmware viejo: no ve la característica de salud, que existe, ni
  la escritura sin respuesta), fix, NTRIP real, sesión larga y las apps.

## Logo de inicio OLED

El logo TresVizo monocromo tiene un plazo de 10000 ms desde el inicio del subsistema de pantalla, al principio de `setup`, antes de Wi-Fi, memoria y BLE. Los reintentos de I2C no reinician ese plazo. Al vencer se oculta primero el logo y se dibuja la pantalla principal; si los servicios todavía no están listos, se muestra «INICIANDO». UART, USB, BLE y lectura de batería siguen funcionando; una solicitud de apagado interrumpe el logo. `subsystems.display.screen` conserva `logo`, `main`, `shutdown` y `none`, y añade `starting` para esa espera explícita. El refresco y la planificación de tareas añaden una tolerancia pequeña al plazo; un bus físicamente bloqueado no permite garantizar cuándo cambia el panel.

Desde 0.8.1 se conserva estable la alimentación de Qwiic y se usa I2C a 100 kHz, suficiente para el refresco de 1 Hz y con más margen de señal en el arnés. Se reinicializa el controlador mediante comandos completos: apagado, offset y geometría 128×64 explícitos. Se enciende sólo tras enviar los 1024 bytes y comprobar cada transacción. Un NACK o escritura corta deja `state: i2c_error` y provoca reinicialización y reenvío completo. Adafruit GFX conserva el dibujo en un framebuffer; el transporte SSD1306 comprobado está en `include/oled_transport.h`.

La OLED consulta el estado de almacenamiento sin esperar por archivos ni bloqueos de SD; cuando está ocupado muestra «MEM INT. OCUPADA». El reinicio solicitado por la app/USB y el posterior a OTA esperan a que la tarea I2C apague la pantalla y cierre el bus, con límite de 300 ms para no quedar atrapados por una avería. Repetir `POST /api/restart` no retrasa el reinicio; durante esa espera se rechazan nuevas operaciones de escritura.

Regresiones nativas: `test/display_boot_test.cpp` (plazo, detección tardía, reintentos, apagado y rollover), `test/oled_transport_test.cpp` (8192 píxeles, NACK y escritura corta en cada paquete, recuperación completa) y `test/display_status_test.cpp`. La prueba de placa `tests/display_boot_bench.py` solicita reinicios sin cambiar configuración y mide la transición `logo` → `main`; la imagen física necesita comprobación visual.

El vector está en `assets/tresvizo-logo.svg`; la imagen final es `assets/tresvizo-oled.png` (128×64, 1 bit). `tools/oled_logo.py` desde la raíz regenera contornos SVG y `include/boot_logo.h` a partir del logo original del panel, con Pillow. El bitmap ocupa 1024 bytes en flash y no depende de la memoria interna del dispositivo.

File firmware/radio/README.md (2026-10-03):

# Firmware del módulo de radio LoRa

Aparato aparte del MeridianV: un ESP32-S3 con una **Ebyte E22-900M30S** (SX1262 + amplificador,
hasta 30 dBm a 915 MHz). Diseño, protocolos y pendientes en
[`docs/radio/RADIO_MODULE.md`](../../docs/radio/RADIO_MODULE.md).

```bash
cd firmware/radio
~/.platformio/penv/bin/pio run                 # compila
~/.platformio/penv/bin/pio run -t upload       # carga por USB
```

## Qué hace

- **Bluetooth** «TresVizo Radio XXXX»: la app le pasa la red y la contraseña del Wi-Fi de su
  MeridianV (por omisión, las de fábrica: `MeridianV` / la del README del firmware) y puede
  cambiar red, canal y potencia. La contraseña se escribe pero nunca se lee de vuelta.
- **Wi-Fi**: se une a la red propia del MeridianV y abre TCP a su puerta de enlace
  (`192.168.4.1:2102`). Si se corta, reintenta cada pocos segundos.
- **Papel**: lo decide el MeridianV según su modo. En **base** transmite el RTCM que le llega
  (tira lo que lleve más de 2 s esperando); en **rover** escucha, rearma el RTCM con el parser
  RTCM3 y entrega al MeridianV solo tramas con CRC válido.
- **Estado** cada segundo al MeridianV y a la app: papel, red, canal, potencia, RSSI y SNR del
  último paquete, paquetes enviados, recibidos, perdidos y de otras redes.

## Cableado (por confirmar con la placa real)

Los pines viven en `platformio.ini` (`-DRADIO_PIN_*`): si la placa es otra, se cambian ahí.

| E22-900M30S | ESP32-S3 | Nota |
| --- | --- | --- |
| VCC | 5 V | A 1 W consume ≈650 mA transmitiendo: no la alimentes del 3V3 de la placa |
| GND | GND | |
| SCK | GPIO 12 | SPI |
| MISO | GPIO 13 | SPI |
| MOSI | GPIO 11 | SPI |
| NSS | GPIO 10 | Selección del SPI |
| BUSY | GPIO 9 | |
| DIO1 | GPIO 8 | Aviso de paquete recibido o enviado |
| NRST | GPIO 7 | Reinicio del SX1262 |
| TXEN | GPIO 6 | Conmutador de antena: emitir |
| RXEN | GPIO 5 | Conmutador de antena: recibir |
| ANT | — | Antena de 915 MHz **siempre conectada antes de encender**: transmitir sin antena daña el amplificador |

El TCXO de la E22 se alimenta por DIO3 a 1.8 V (`RADIO_TCXO_VOLTS`), según Ebyte; por
confirmar con la hoja de datos del lote.

## Sin probar

Nada se ha probado con hardware: compila, y la lógica del aire y del enlace está probada en
el host (`firmware/esp32/test/radio_air_test.cpp`, `radio_link_test.cpp`). Falta: que la E22
arranque con estos pines y este TCXO, potencia real a la salida, alcance, y una base y un rover
de punta a punta.

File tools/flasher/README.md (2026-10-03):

# Cargador de firmware por USB

**Desde 0.8.0:** el MeridianV de este cargador es la **SparkFun Thing Plus ESP32-S3 WRL-24408**, hardware `tresvizo-thingplus-s3-4m-v1`. No usar su imagen en la Tiny. El hardware se lee del campo firmado en byte 320; ya no se identifica buscando una cadena suelta dentro del binario. La placa nueva requiere **Instalación completa**. Ver [cableado y montaje](../../hardware/wiring.md).

Ventana para cargar el firmware del **MeridianV** por el cable USB, sin
abrir la terminal ni recordar direcciones. Por dentro hace lo mismo que
`pio run -t upload`: el esptool de PlatformIO, las mismas direcciones y el mismo modo de
flash.

## Abrirlo

- Doble clic en **`Cargar firmware.command`** (macOS). La primera vez, si macOS lo bloquea:
  clic derecho › Abrir.
- O desde la terminal: `python3 tools/flasher/meridian_flasher.py` (Python de python.org,
  que trae tkinter).

Necesita PlatformIO instalado (`~/.platformio`), que es con lo que ya se compila el firmware.
Sin PlatformIO sirve cualquier Python con `pip install esptool pyserial`.

## Pasos

1. **Modelo**: **MeridianV** o **Radio LoRa** (el módulo de radio aparte, con su propio
   ESP32: `firmware/radio/`, `docs/radio/RADIO_MODULE.md`). El radio no tiene consola USB:
   no se lee antes ni después de cargarlo; se comprueba desde la app por Bluetooth.
2. **Imagen**: `firmware-signed.bin` (o `firmware.bin`) de `firmware/esp32/.pio/build/<modelo>/`
   o de un paquete de `tools/firmware_package.py`. La ventana dice de qué modelo es, su
   versión y si trae la firma del propietario.
3. **Puerto**: el del equipo conectado por USB («Buscar» los vuelve a leer).
4. **Cargar firmware**.

## Qué comprueba

- Que la imagen sea de aplicación para ESP32-S3 (no un bootloader ni un volcado entero).
- **Que la imagen sea del modelo elegido**, por su `hardware_id` (el de cada producto está en
  `firmware/esp32/src/firmware_update.cpp`). Si no coincide, no deja cargar.
- Si trae firma, que sea válida con la clave pública embebida en el firmware. Una firma
  inválida bloquea la carga. Por USB también se puede cargar una imagen sin firma (el cable
  es acceso físico); la OTA por Wi-Fi o por las apps, no.
- Antes de cargar lee el equipo conectado. **Si es de otro modelo, pregunta antes de
  cargarlo.**
- Después de cargar espera a que arranque, lo vuelve a leer y confirma modelo y versión.

## Actualización o instalación completa

- **Actualización** (por omisión): escribe la aplicación en `0x10000` y `boot_app0` en
  `0xe000`, que devuelve el arranque a esa partición. Sin `boot_app0`, un equipo que se
  actualizó antes por OTA seguiría arrancando la otra partición.
- **Instalación completa** (placa nueva): además `bootloader.bin` en `0x0` y
  `partitions.bin` en `0x8000`, tomados de junto a la imagen o de la compilación de ese modelo.
- Ninguna de las dos borra los ajustes guardados en el equipo (red Wi-Fi, perfiles NTRIP,
  contraseña del AP). A la flash va la imagen sin los 72 bytes de la firma, igual que en una OTA.

## Pruebas

`python3 -m unittest tools/flasher/test_meridian_flasher.py` — reconoce el modelo y la
versión de imágenes de prueba y de las compiladas por `pio run`, rechaza lo que no es una
imagen de aplicación, arma la orden de esptool con las direcciones de PlatformIO y lee el
progreso.

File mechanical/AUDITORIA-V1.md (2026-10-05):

# Auditoría de la carcasa V1

Revisión del 22 de septiembre de 2026, en rama aislada `worktree-case-v2-simplificado`.
No modifica V1. Mediciones tomadas de los STL entregados con
`mechanical/audit/measure_stl.py`, que no necesita FreeCAD.

## Lo que hay hoy, medido

| Pieza | X | Y | Z | cm³ |
| --- | ---: | ---: | ---: | ---: |
| 01 cuerpo | 74.0 | 74.0 | 138.2 | 75.2 |
| 02 chasis-base | 64.3 | 64.3 | 163.6 | 74.7 |
| 03 cuna batería/IMU/power | 60.6 | 37.2 | 122.3 | 55.7 |
| 04 tapa antena | 74.0 | 74.0 | 23.6 | 17.6 |
| 05 panel USB/botón | 28.0 | 25.5 | 53.0 | 3.9 |
| 06 prensa IMU | 30.0 | 10.0 | 4.0 | 1.1 |
| 07 actuador botón | 13.0 | 13.0 | 3.4 | 0.3 |
| 08 cartucho botón | 24.1 | 13.0 | 7.2 | 0.9 |
| 09 + 10 difusores | 5.5 | 5.5 | 3.6 | ~0 |
| 11 plantilla IMU | 35.0 | 20.0 | 21.3 | 1.7 |
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

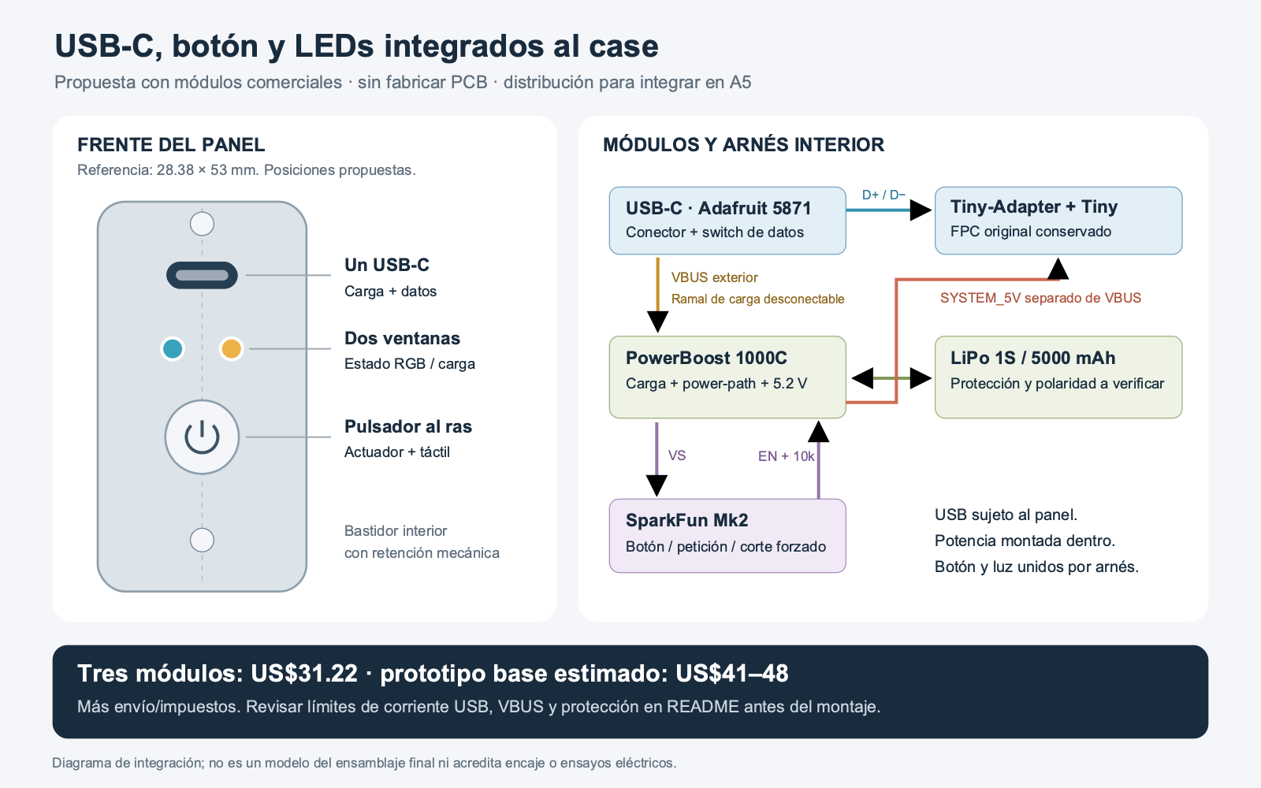
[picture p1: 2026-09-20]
hardware/power-modules/panel-and-modules.png

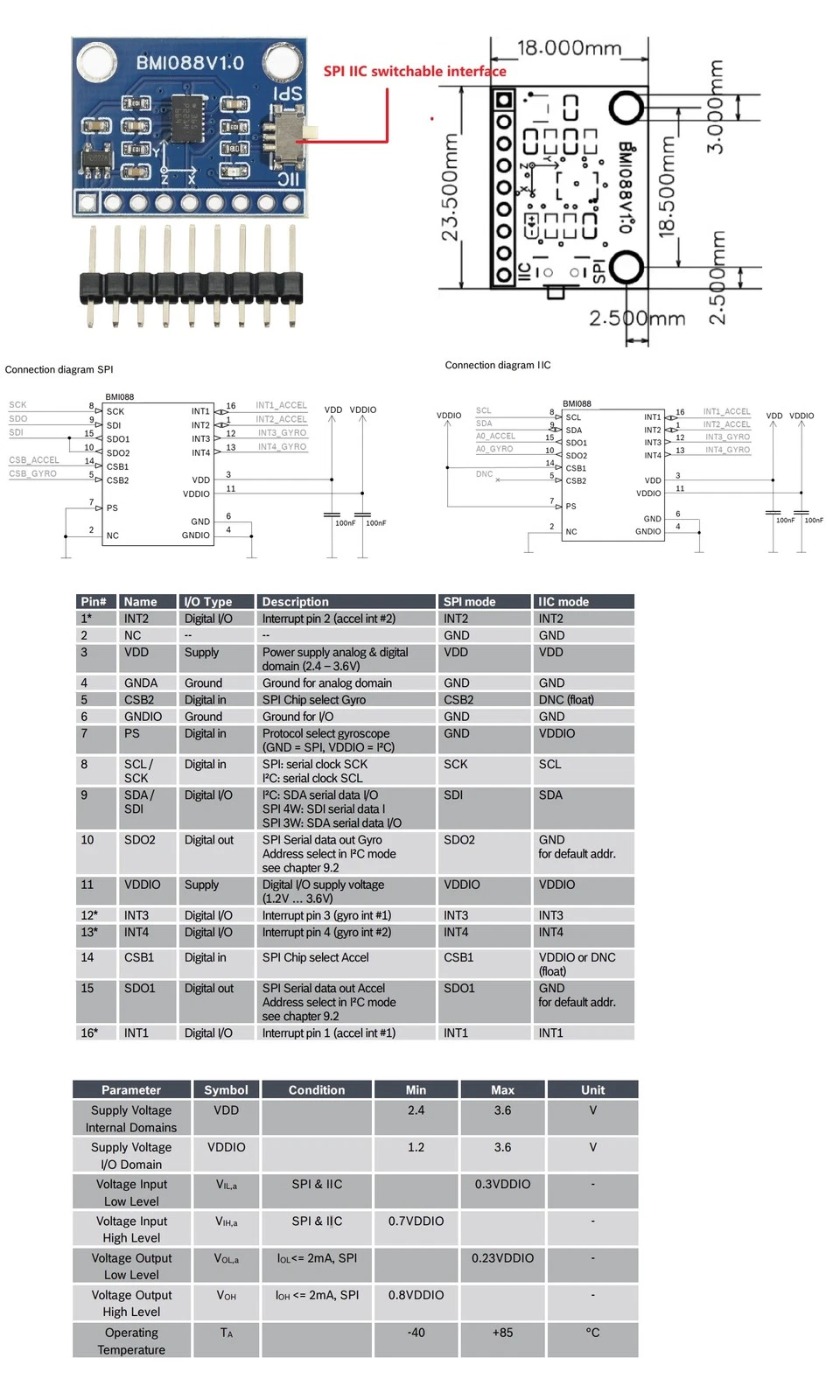
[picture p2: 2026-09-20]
mechanical/referencias/BMI088-V1-dimensions.webp

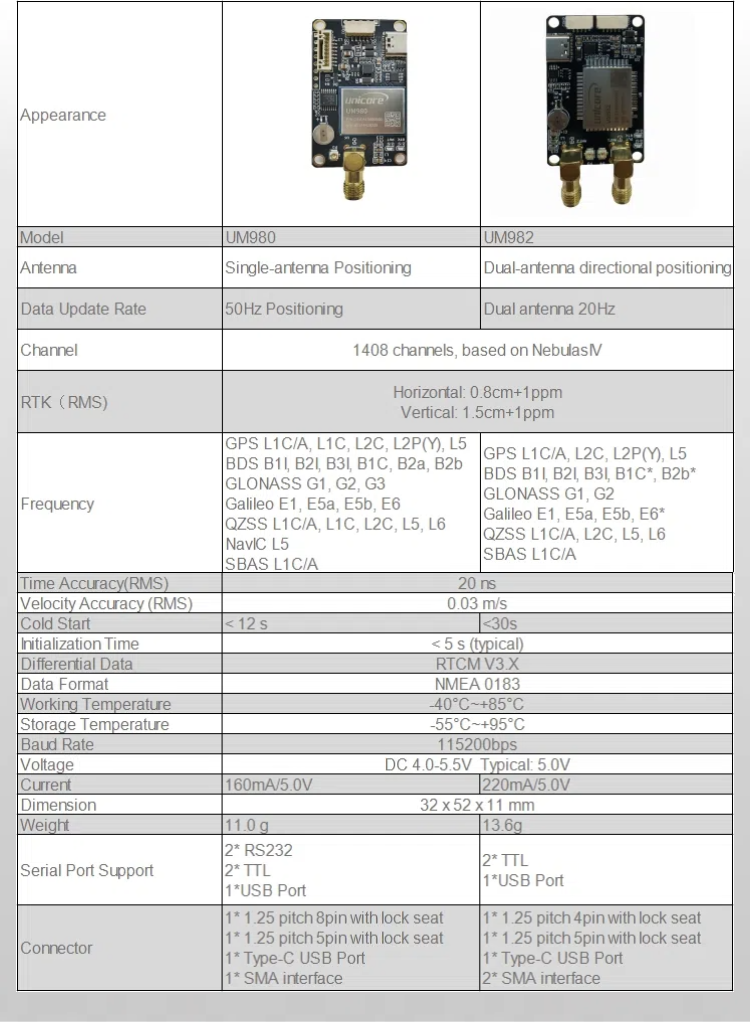
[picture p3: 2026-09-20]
mechanical/referencias/BDLX-UM980-specifications.png

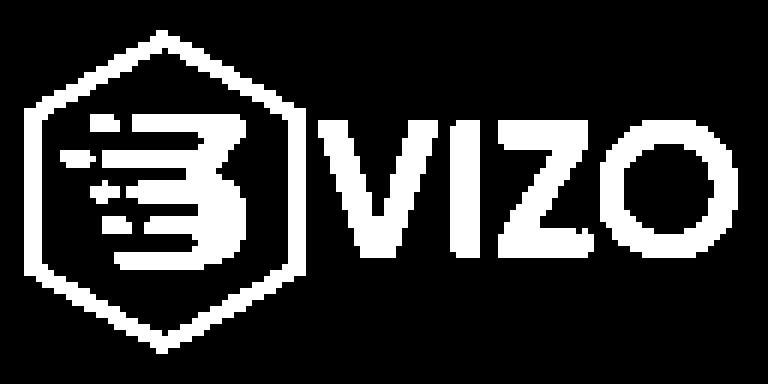
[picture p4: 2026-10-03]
firmware/esp32/assets/tresvizo-oled-preview.png

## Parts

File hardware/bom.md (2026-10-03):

# Lista de materiales — hardware seleccionado

**Alimentación — 02/10/2026:** LiPo 1S 3.7 V / 3000 mAh confirmada. Lectura MAX17048 y apagado coordinado Mk2 implementados; falta identificar el elevador de 5 V y validar físicamente el conjunto con UM980. Ver `hardware/wiring.md` desde la raíz. La carga es autónoma por hardware; USB impide el corte total de batería.
**Selección del 02/10/2026:** Thing Plus ESP32-S3 WRL-24408, OLED Tecneu 0.96 I2C 128×64 y SparkFun Soft Power Switch JST 2 mm. Firmware y cableado actualizados; encendido/apagado implementado; prueba física pendiente.

Esta lista documenta la configuración prevista, no un diseño electrónico cerrado. No confirma compatibilidades eléctricas o mecánicas entre componentes. La mayoría de los componentes se reporta como recibida, pero falta realizar y documentar un inventario físico detallado; la referencia de batería ya fue indicada y su caracterización sigue pendiente.

| Componente | Función | Modelo previsto | Estado de confirmación | Observaciones |
| --- | --- | --- | --- | --- |
| Receptor GNSS principal | Solución GNSS/RTK y generación de observaciones | Unicore UM980 en placa de desarrollo o carrier | Previsto; carrier concreta por identificar | Verificar modelo de placa, firmware, conectores, interfaces y acceso real a señales. PPS en el conector queda pendiente de verificación. |
| Receptor GNSS alternativo | Pruebas y comparación | u-blox ZED-F9P | Disponible para posibles pruebas | No es el receptor principal definido y no implica que ambos receptores sean intercambiables. |
| Microcontrolador | Control y comunicaciones | ESP32-S3 en Thing Plus | Seleccionado | Configuración específica en firmware/esp32/boards; no es una DevKitC ni una Tiny. |
| Placa del microcontrolador | Control, Wi-Fi, BLE y USB | SparkFun Thing Plus ESP32-S3 WRL-24408, MINI-1-N4R2 | Compra y elección definitivas del propietario | 4 MB flash / 2 MB PSRAM Quad según fabricante; sustituye a la Tiny. Firmware 0.8.0 compilado; prueba física pendiente. |
| IMU | Aceleración y velocidad angular | Bosch BMI088 en breakout | Prevista; breakout por identificar | Verificar fabricante de la placa, orientación de ejes, interfaz, niveles y requisitos de montaje. |
| Lector y tarjeta microSD | Registro local | Socket SDIO integrado de la Thing Plus + tarjeta FAT32 | Lector definido; tarjeta por verificar | Backend de cuatro bits habilitado; reemplaza el módulo SPI externo. |
| Antena GNSS | Recepción GNSS | Helix; modelo exacto por confirmar | Compra confirmada por el propietario | Verificar bandas, conector, alimentación, montaje y referencia del centro de fase. La HA-901A mencionada inicialmente no está confirmada. |
| Batería | Alimentación portátil | LiPo 1S, 3.7 V / 3000 mAh / 11.1 Wh nominales | Capacidad corregida por el propietario; sin caracterización física | Dos cables en imagen; capacidad real, dimensiones, conector, PCM, corriente admisible y NTC por confirmar. Ver [referencia de batería](references/BATTERY_REFERENCE.md). |
| Alimentación y carga | Operación de banco y futura batería | USB-C de Thing Plus y USB propio del UM980 durante pruebas | Encendido/apagado en espera | La Thing Plus incorpora cargador y MAX17048; no se ha cerrado distribución portátil ni alimentación de UM980. |
| Carcasa | Protección y referencia mecánica | Cilíndrica, impresa en 3D | Concepto previsto | Dimensiones y material pendientes; debe mantener alineación entre antena, IMU y jalón. |
| Interruptor | Encendido/apagado futuro | SparkFun Soft Power Switch JST 2 mm | Compra confirmada | PUSH=GPIO10/A0, OFF=GPIO14/A1; pendiente de banco. |
| Interfaz de usuario física | Estado local | OLED Tecneu 0.96 pulgadas, I2C, cuatro pines, 128×64 con estuche | Compra confirmada | Driver SSD1306 según referencia del vendedor, dirección 0x3C/0x3D y VCC a 3.3 V; validar unidad recibida. |

Cableado vigente en [hardware/wiring.md](wiring.md). La carcasa diseñada para Tiny requiere revisión mecánica antes de alojar Thing Plus/OLED; no se ha regenerado CAD con dimensiones supuestas.

## Antes de cerrar la BOM

- Fotografiar e identificar cada placa, revisión y conector sin publicar números de serie sensibles.
- Contrastar las marcas de los módulos con sus manuales oficiales.
- Medir las dimensiones y masas relevantes para la carcasa.
- Confirmar requisitos eléctricos y térmicos antes de elegir regulación, carga y batería.
- Registrar sustituciones como decisiones explícitas, sin asumir equivalencia por nombre de chip.

La [identificación de componentes](identification.md) conserva la evidencia y las diferencias entre opciones de la tienda y unidades verificadas.

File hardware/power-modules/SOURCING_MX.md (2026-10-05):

# Compra de componentes desde México

> Actualización mecánica: para la variante de integración revisada, la [lista de tornillería de V2.2](../../mechanical/v2.2/SCREW-BOM.md) sustituye esta lista. El resto de esta página conserva la consulta comercial original; no es una compra ni una verificación de stock posterior.

Consulta del **20 de septiembre de 2026**. Precios publicados por unidad, antes de envío y cargos que correspondan. Existencia web no garantiza inventario en una sucursal de Chihuahua. No se realizó ninguna compra.

| Pieza y cantidad | Dónde conseguirla | Precio observado | Resultado |
| --- | --- | --- | --- |
| 1 pulsador AU-101 | [Steren México](https://www.steren.com.mx/micro-switch-de-push-con-4-terminales.html) | **$2 MXN** | En stock web. Momentáneo NA de cuatro terminales; dos pares internamente comunes. Verificar continuidad. Cotas no publicadas: cartucho mecánico ajustable. |
| 1 LED-5/RGB | [Steren México](https://www.steren.com.mx/led-de-5-mm-rgb.html) | **$5 MXN** | En stock web. Ánodo común; Ø5, longitud de cuerpo publicada 8.45. Sustituye al RGB Adafruit del presupuesto anterior. |
| 1 PowerBoost 1000C **2465** | [DigiKey México, 1528-1349-ND](https://www.digikey.com.mx/es/products/detail/adafruit-industries-llc/2465/5356834) | **$19.95 USD** | 279 en stock al consultar. Venta mediante distribuidor para México; no significa almacén local ni envío incluido. |
| Alternativa del mismo 2465 | [Newark México, 98Y0120](https://mexico.newark.com/adafruit/2465/powerboost-1000-lipo-charger-5v/dp/98Y0120) | $20.53 USD | 6 en stock al consultar. Elegir un solo proveedor para este módulo. |
| 1 USB-C + switch TS3USB30 **5871** | [DigiKey México, 1528-5871-ND](https://www.digikey.com.mx/en/products/detail/adafruit-industries-llc/5871/22596394) | **$3.95 USD** | 85 en stock al consultar. Es la placa comercial cuyos cuatro agujeros usa el panel. |
| 1 encendido electrónico **PRT-26993** | [SparkFun, versión JST 2 mm](https://www.sparkfun.com/sparkfun-soft-power-switch-jst-2mm.html) | **$7.32 USD** | En stock en fabricante. **No encontré stock mexicano confirmado**; considerar importación. Su [política de envío internacional](https://www.sparkfun.com/support) describe transportistas y cargos adicionales; costo/plazo a la dirección final no cotizado. |

**Base seleccionada: $31.22 USD en los tres módulos + $7 MXN en pulsador/RGB.** No convertir esa suma en un total entregado: faltan envíos, importación cuando corresponda, cableado, fusibles, resistencias, transistores, óptica y tornillería. Conviene agrupar 2465 y 5871 en el mismo pedido de DigiKey. El envío separado de SparkFun puede pesar más que su placa.

La compra de Steren reemplaza únicamente pulsador y RGB; el AU-101 acciona BTN/GND del módulo electrónico, no interrumpe directamente la corriente del GNSS.

## Mercado Libre y AliExpress

La [publicación mexicana de PowerBoost AF-2465 por Sandorobotics](https://www.mercadolibre.com.mx/cargador-powerboost-1000--version-micro-usb-arduino/up/MLMU976897609) sí identifica el producto, pero el resultado consultado indica **“no está disponible por el momento”**. No se usa como oferta en stock ni se inventa precio. El AF-2030 de ese vendedor es la versión básica y no sustituye el cargador 1000C.

Se encontraron módulos genéricos “UPS 15 W / 3 A” y combinaciones TP4056/elevador en Mercado Libre, pero sin evidencia suficiente para trasladar a ellos el power-path, apagado y ausencia de alimentación inversa de esta propuesta. El [módulo TP4056 USB-C vendido por UNIT en Mercado Libre](https://www.mercadolibre.com.mx/modulo-tp4056-usb-c-carga-18650-con-proteccion-cable-usb/p/MLM74619274) es un cargador de celda; no es por sí solo un USB de datos ni un reemplazo completo de los tres módulos.

**AliExpress no pudo verificarse:** el acceso fue bloqueado por la política de navegación de esta sesión. No se publican precios, enlaces de compra ni existencias de AliExpress como si se hubieran comprobado.

El biestable que ya posee el proyecto sigue siendo candidato para reutilizar. Hace falta identificar la placa y sus señales antes de asignarle el apagado por firmware y forzado del PRT-26993. No se exige comprar otro sólo para fijar el diseño de la cara del panel.

## Consumibles y especificaciones para pedir localmente

| Elemento | Cantidad inicial / condición |
| --- | --- |
| Tornillos USB | 4 M2 × 5, cabeza compatible con zona libre Ø4 del módulo; pilotos impresos Ø1.7. Probar roscado y apriete. |
| Tornillos cartucho | 2 M2 × 8, cabeza hasta Ø3.6 para la reserva modelada. |
| Tornillos panel | 2 M3 avellanados 90°, cabeza ≤Ø5.6; longitud según la tuerca/boss conservada del case. |
| Cable USB 2.0 de datos interno | USB-C macho compacto hacia Tiny-Adapter; conservar par trenzado/apantallado. El enchufe modelado es una reserva, no una referencia de compra ya seleccionada. |
| Cable USB exterior | Sobremolde que quepa en el rebaje frontal 14 × 6.5. Comprobar ambas orientaciones. |
| NPN y resistencias | Según [WIRING](WIRING.md); seleccionar pinout del transistor real, termoencogible y arnés soldado/aislado. |
| Fusibles y cable de potencia | Según WIRING, tras medir picos y verificar batería. No sustituir un fusible por una protección de celda. |
| Difusores / guía de carga | Dos piezas translúcidas según STL; guía desde los LEDs del cargador. Trayectoria/longitud y brillo aún por probar. |

Los consumibles de esta última tabla no tienen una oferta ni precio verificados en esta consulta; son requisitos de montaje, no una cotización cerrada. El [CAD vigente, V2.2](../../mechanical/v2.2/README.md), contiene los soportes y las holguras para prototipar.

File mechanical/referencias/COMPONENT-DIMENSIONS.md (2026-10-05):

# Dimensiones de los componentes comprados

> Referencia heredada de A5. Para fabricar y montar usar [V2.2](../v2.2/README.md); sus cambios y estado sustituyen los pendientes históricos de este documento.

Investigación: 19 de septiembre de 2026. Unidades: mm. Este documento separa las cotas publicadas, la correspondencia visual con la compra y las reservas del CAD. No constituye una inspección dimensional de las piezas recibidas. Actualización del 20 de septiembre: el montaje ajustable del BMI088 ya está incorporado en `TresVizo-A5.FCStd`; véase [montaje y centrado](IMU-ALIGNMENT.md).

## Resultado

| Componente | Datos encontrados | Alcance de la evidencia |
|---|---|---|
| BMI088 azul V1.0 | PCB 18 × 23.5; dos agujeros Ø3; separación 18.5; centros a 2.5 de los bordes próximos | Plano de vendedor con fotografía coincidente con la placa comprada. Resuelve el patrón publicado de fijación. |
| Carrier UM980 BDLX | 32 × 52 × 11 | Ficha del fabricante; no incluye patrón acotado de agujeros. |
| microSD azul | PCB 42 × 24; patrón 38 × 20, tornillos M2 | Ficha de vendedor de la misma familia; no está demostrada la identidad del fabricante o lote de AliExpress. |
| Batería 955565 | Compra confirmada: 3.7 V, 5000 mAh, 18.5 Wh; nominal 9.5 × 55 × 65 | Identificación aportada por el propietario. El máximo del paquete terminado no queda fijado por el código de celda. |
| Antena HA-901A | Ø43.5 × 40.8; 3-M2.5×6 sobre círculo Ø26.6 | Etiqueta del propietario y plano del vendedor; montaje ya incorporado en A5. |
| Waveshare ESP32-S3-Tiny | PCB 18 × 23.5; perfil publicado 2.45 | Plano oficial; los pads de conexión no son agujeros de montaje. |
| Adaptador USB Waveshare | PCB 18 × 18; patrón 14 × 14, centros a 2 de bordes | Plano oficial; no confundir la cota 2 del borde con diámetro de agujero. |

## BMI088: plano localizado

[Anuncio con la placa y su plano](https://www.ebay.com/itm/206558450820). [Imagen original](https://i.ebayimg.com/images/g/pIEAAeSw-1lqoAi0/s-l1600.webp). [Copia de consulta](BMI088-V1-dimensions.webp).

Coinciden la serigrafía BMI088V1.0, el PCB azul, los dos agujeros en el mismo borde, la hilera de nueve conexiones en el borde opuesto y el selector IIC/SPI. La procedencia es un vendedor de una placa sin marca declarada; no una certificación del fabricante del lote comprado.

Coordenadas para trasladar el plano a CAD, mirando la cara de componentes con la hilera de conexiones abajo: origen en esquina inferior izquierda del PCB; X hacia la derecha, Y hacia arriba. Contorno 23.5 en X × 18 en Y. Agujeros centrados en **(2.5, 15.5)** y **(21.0, 15.5)**, diámetro **3.0**. Son coordenadas derivadas aritméticamente de las cotas, no medidas por píxeles. Alternativamente, en la orientación del dibujo publicado: contorno 18 × 23.5 y centros (15.5, 2.5), (15.5, 21).

No están acotados el espesor del PCB, la altura del selector y pines ni la posición exacta del encapsulado sensor respecto a esos agujeros. No usar el centro geométrico de la placa como supuesto centro del sensor. A5 ya incorpora este patrón en la referencia PCB y un asiento ajustable: dos M2.5 y una plantilla removible alinean el encapsulado real con el eje del receptor. `IMUReserve` usa espesor provisional de 1.6 mm; `IMUTarget` es un objetivo de alineación, no la posición medida del sensor. Véase [montaje y límites](IMU-ALIGNMENT.md).

## UM980: carrier correcto, agujeros sin plano publicado localizado

[Página oficial BDLX](https://www.bdlxgnss.com/?list_22/101.html=). [Tabla oficial de dimensiones](https://www.bdlxgnss.com/static/upload/image/20250804/1754279536807539.png), guardada en [sources](BDLX-UM980-specifications.png). [Fotografía de ambas caras](https://www.bdlxgnss.com/static/upload/image/20250804/1754279537213094.png).

La ficha publica 32 × 52 × 11 y las fotografías permiten reconocer la familia de carrier RTK_UM98_V1.0.1. Se revisaron las doce imágenes de detalle y el enlace Download: éste devuelve una imagen promocional, no un plano mecánico. No se encontró en ellas diámetro, coordenadas ni distancias entre centros de sus cuatro agujeros. Tampoco se especifica inequívocamente si las dimensiones máximas incluyen todas las salientes de los conectores.

Se buscaron la revisión de serigrafía, BDLX, BD LOCATOR y las dimensiones; el anuncio alternativo en [Joom](https://www.joom.com/nb/products/69e9bfbe042817016c51668c) identifica BD LOCATOR pero no aporta esas cotas. Los planos del encapsulado UM980 de Unicore y de las placas de SparkFun no corresponden a este carrier.

Datos que faltan concretamente: diámetro de los cuatro barrenos, centros respecto a dos bordes del PCB y envolventes/posición de SMA, USB y conectores con sus cables enchufados. Para cerrar fijaciones rígidas hace falta el dibujo mecánico de esta revisión o medir la placa. No se adopta un patrón supuesto de 26 × 46 obtenido por proporción de fotografías. Los soportes ajustables propuestos por el propietario siguen siendo una opción para este carrier. Para el IMU, el propietario autorizó después ajuste durante montaje con indicador de centrado y bloqueo rígido final; no debe quedar flotante en uso.

## microSD: patrón de la familia, no certificación del lote

[Ficha del módulo de Robot Pi Shop](https://robotpishop.com/products/micro-sd-card-reader-module): 42 × 24, fijaciones M2 con separación 38 × 20. [Ficha de Flux Workshop BFAA100021](https://fluxworkshop.com/products/bfaa100021-micro-sd-blue): misma familia, envolvente publicada 42 × 24 × 7. La consulta directa de Flux falló en esta revisión; la información recuperada del buscador no sustituye un plano descargado.

El anuncio del propietario muestra la familia azul con regulador y conversor de nivel, seis pines y cuatro agujeros. El patrón encontrado sirve de referencia para soportes ajustables. No se deduce de la denominación M2 el diámetro exacto del barreno, ni se fijan centros a 2 mm del borde sin confirmar que el patrón esté centrado. Falta la cota de la ranura de tarjeta respecto al PCB y el recorrido de inserción/extracción para cerrar el acceso de la carcasa.

## Batería comprada: 955565 de 5000 mAh

El propietario confirmó con captura la [batería comprada](https://es.aliexpress.com/item/1005008867815394.html): 955565, 3.7 V, 5000 mAh y 18.5 Wh, dos cables y conector de dos contactos. El resumen comercial indica 9.5 × 55 × 65. No identifica de forma verificable el fabricante de la celda, el paso del conector, la polaridad de su carcasa ni tolerancias del paquete. El acceso automatizado a AliExpress está bloqueado; no se obtuvo de allí un plano adicional.

Se encontró una **especificación real con plano de otro paquete 955565**, fabricado por Shenzhen Dazheng para Ciel Light: [PDF, página 5](https://ciellight.com/data/item/DZ955565/955565-3.7V-5000mah%20XBL-MP4439A%201.25-2P.pdf). Define máximos **10 × 55.5 × 68**, cables 60 ±5 y conector 1.25-2P para SU producto. El alcance del propio documento restringe su aplicación a ese fabricante. Por tanto, ni el conector ni las especificaciones eléctricas de ese PDF se atribuyen a la batería del propietario.

La diferencia demuestra por qué 9.5 × 55 × 65 de celda nominal no basta para diseñar un alojamiento ajustado. La reserva existente en A5 es 56 × 12 × 69 (ancho × espesor × largo): contiene aquella envolvente de referencia, pero **no demuestra ajuste del paquete comprado ni espacio suficiente para cableado o cambios de espesor durante uso**. Debe sujetarse sin comprimir la bolsa y conservar espacio para la salida de cables; no cambiarla a un hueco exacto de 9.5 × 55 × 65.

La identificación eléctrica y el diseño de carga pertenecen a [BATTERY_REFERENCE.md](../../hardware/references/BATTERY_REFERENCE.md); este hallazgo no cambia las decisiones de la PCB en desarrollo.

## Fuentes ya disponibles: antena y Waveshare

Antena: [plano HA-901A](https://i.ebayimg.com/images/g/F2sAAOSwLzJl8nTm/s-l1600.webp), [anuncio XYANT Wireless](https://www.ebay.com/itm/315222778620). El montaje incorporado, la tornillería y las verificaciones están descritos en [V2.2](../v2.2/README.md).

Waveshare: [documentación oficial ESP32-S3-Tiny](https://www.waveshare.com/wiki/ESP32-S3-Tiny) y [plano mecánico oficial](https://docs.waveshare.com/assets/images/ESP32-S3-Tiny-details-1-3cb57dcb7847e1db49d2faee9722d6df.webp). El adaptador USB separado no es un cargador de batería. Botón, USB-C de carga y LEDs siguen sujetos a la PCB que se está diseñando; no se seleccionan módulos nuevos ni se cierran perforaciones del panel en esta investigación.

El inserto del jalón tampoco queda definido por estos planos electrónicos: sigue pendiente una referencia comercial concreta con rosca y dimensiones de anclaje documentadas. No se añade una pieza metálica de fabricación especial.

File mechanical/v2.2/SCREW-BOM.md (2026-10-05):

# Tornilleria de V2.2

Generado por `bom.py` desde `parameters.json` (lo ejecuta `regenerate.py`). Las longitudes salen de
la geometria del modelo, no de una estimacion: se mide desde el asiento
de la cabeza hasta el fondo del barreno y se elige la medida comercial que cabe.

**Nada de esto se ha montado ni ensayado.**

## Carcasa

| Pieza | Largo | Cant. | Donde | Calculo |
| --- | ---: | ---: | --- | --- |
| M3 cabeza boton ISO 7380 | 10 mm | **1** | Seguro de la base. Rosca en el macizo de la base. | piloto util 10.5 mm; rosca 5.4 mm |
| M3 cabeza boton ISO 7380 | 12 mm | **1** | Seguro de la tapa. Rosca en el refuerzo del cuello. | piloto util 12.5 mm; rosca 7.4 mm |
| M3 cabeza boton ISO 7380 | 4 mm | **2** | Tapa del panel principal. Rosca en el engrosamiento. | rosca 3.1 mm; la punta no sale del engrosamiento |
| M2.5 cilindrica ISO 4762 | 10 mm | **3** | Antena. Sube desde dentro y rosca en la antena. | tapa 5 + 5 de 6 de rosca en la antena |
| M2.5 cabeza avellanada ISO 10642 o DIN 965 | 6 mm | **2** | BMI088 sobre la plataforma. Rosca en el separador. | cabeza 1.0 sobre la placa + PCB 1.6 + piloto 4.0 |
| M2 cilindrica ISO 4762 o cabeza plana | 4 mm | **4** | Pantalla OLED contra su marco. Rosca en el marco. | PCB 1.6 + piloto 3.0 |
| Tuerca M12x0.75 del boton | — | **1** | Viene con el boton. Asienta en el plano interior de la tapa. | panel de 3.4 mm en el eje del boton |
| M3 cabeza boton ISO 7380 | 8 mm | **2** | Detienen la tuerca del jalon por arriba, con arandela ancha. | arandela 0.8 + rosca 7.2 mm en un piloto de 8.5 |
| Arandela plana ancha M3 DIN 9021 (9 x 0.8) | — | **2** | Bajo los dos M3: pisan 1.4 mm de la tuerca. | la de 7 mm (DIN 125) pisa menos de 1 mm |
| Tuerca hexagonal 5/8-11 UNC de laton | — | **1** | Rosca del jalon. Entra por dentro de la base, en su hexagono. | estandar: 15/16 in entre caras, 35/64 in de alto; hueco de 24.1 entre caras |

**15 tornillos con longitud definida.** Ninguno lleva tuerca: todos roscan en el plastico o en la antena. La unica tuerca es la del jalon.

## Conector de carga

| Pieza | Cant. | Donde |
| --- | ---: | --- |
| Header JST-XH de 2 pines, vertical, B2B-XH-A (o clon "XH 2.54 2P macho recto") | 1 | Panel, a ras, en su bolsillo de 7.7 x 6.0. Cables soldados a sus patas. |
| Carcasa XHP-2 con 2 terminales SXH, o un cable XH de 2 pines ya armado | 1 | Del lado del cargador. |

JST lo vende como conector de placa, no para conectar y desconectar a diario.

## Lo de dentro

Nada de lo de dentro se atornilla: la 18650 va detras del respaldo y el
carrier UM980 y la Thing Plus delante, amarrados con bridas; lo demas,
al respaldo o a los cuatro toalleros. Varias de esas placas no tienen
patron de agujeros publicado.

## Advertencias

- Tornillos del panel: NO poner uno mas largo que el de la lista. El de arriba queda a menos de 1 mm del cuello de la tapa, que gira al cerrar la bayoneta: si asoma, la tapa no cierra.
- Los tres tornillos de la antena van ANTES que la plataforma del IMU: sus cabezas quedan dentro del cuello de la tapa.
- Los dos M2.5 del IMU tienen que ser de cabeza AVELLANADA: el cono asienta en el canto del agujero de 3.0 y centra la placa sobre el piloto. Con cabeza cilindrica quedan 0.25 mm de juego por lado y el chip ya no cae en el eje. Sin tuercas ni arandelas.
- Los agujeros de la pantalla son de 2.0 segun el plano del vendedor y el M2 entra justo. Si no pasa, repasar el agujero con broca de 2.2 o usar M1.6x4.
- La tuerca del boton queda a unos 10 mm del marco de la pantalla: apretarla con pinzas o con una llave de 14 delgada, antes de montar la pantalla.
- Tuerca del jalon: hexagonal ESTANDAR de 5/8-11 UNC (5/8 NC, 11 hilos), de laton. No sirve la pesada (1-1/16 in entre caras, no entra), ni la de rosca fina 5/8-18, ni una de seguridad con nylon. Medirla al comprarla: hasta 24.0 entre caras y 13.9 de alto entra en el hueco tal cual. Va con el tubo quitado: se mete por dentro de la base hasta el anillo y se ponen los dos M3 con su arandela.

## Consumibles

| Consumible | Cantidad | Uso |
| --- | ---: | --- |
| Brida de 2.5 a 3.6 mm, 150-200 mm | 10-15 | Placas y 18650 al respaldo |
| Epoxico de 5 minutos | unas gotas | Header JST-XH en su bolsillo, por dentro |
| Termofit de 2.5 mm | 5 cm | Patas del header JST soldadas a sus cables |
| Brida de 2.5 mm, 100-150 mm | 4-8 | Componentes extra en los toalleros |
| Lamina transparente de 1 mm (acrilico o PETG), 26.7 x 19.3 | 1 | Mica de la pantalla |
| Filamento TPU 95A | ~35 g | Las dos bandas de proteccion |
| Cinta de espuma o fieltro adhesivo | 1 tira | Entre la 18650 y el respaldo |
| Llave Allen 2 mm | 1 | M3 cabeza boton y M2.5 cilindrica de la antena |
| Llave Allen 1.5 mm o desarmador Phillips 0 | 1 | M2 de la pantalla y M2.5 avellanado del IMU |
| Llave de 14 mm o pinzas | 1 | Tuerca del boton |

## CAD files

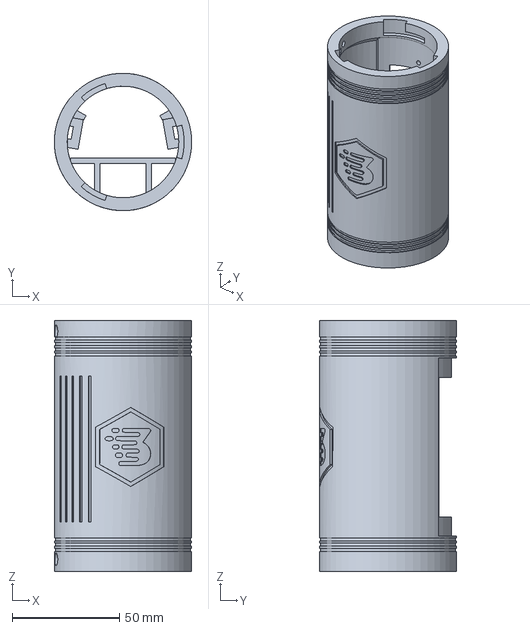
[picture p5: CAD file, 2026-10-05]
mechanical/v2.2/generated/step/02-logo-tube.step
64.0 x 64.0 x 116.9 mm

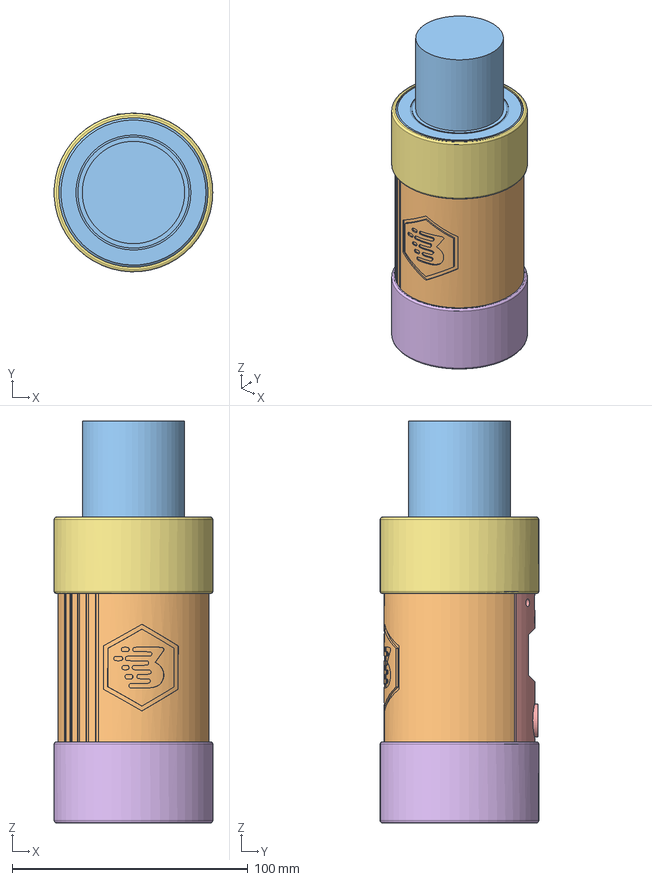
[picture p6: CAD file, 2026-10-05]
mechanical/v2.2/generated/TresVizo-V2.2.FCStd
67.4 x 67.4 x 170.7 mm
Base con rosca 5/8
Tubo con logo y respaldo de amarre
Tapa de antena
Plataforma del IMU
Tapa del panel principal
Banda de TPU de abajo
Banda de TPU de arriba
Ref: PCB del BMI088
Ref: chip BMI088, centrado en el eje
Ref: SMA macho acodado y coaxial
Ref: antena HA-901A
Ref: OLED 0.96 in con pines y cables soldados
Ref: boton 12 mm con tuerca y cables
Ref: 18650, peor caso, detras del respaldo
Ref: carrier UM980
Ref: Thing Plus ESP32-S3
Ref: tuerca 5/8-11 de laton
Ref: arandelas y cabezas de los M3 que detienen la tuerca
Ref: header JST-XH B2B-XH-A con sus cables

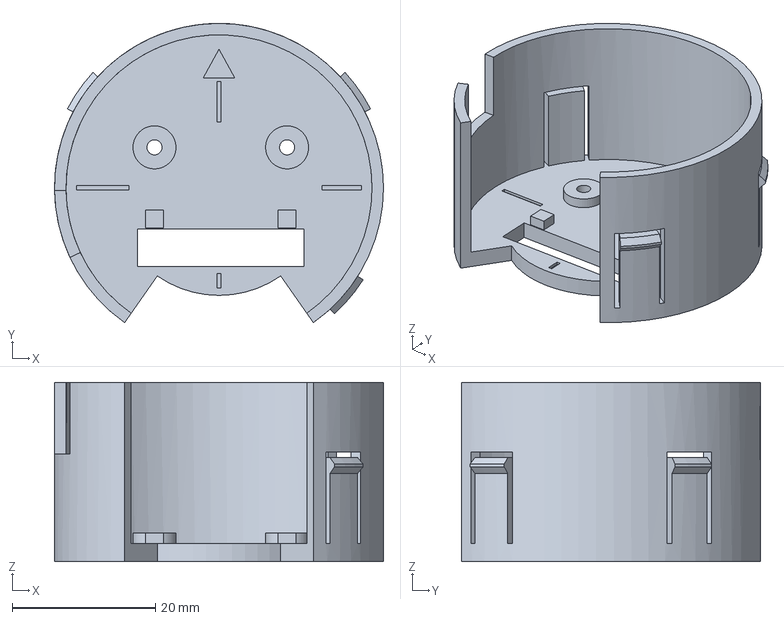
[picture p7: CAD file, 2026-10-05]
mechanical/v2.2/generated/step/04-imu-platform.step
45.9 x 41.7 x 25.0 mm

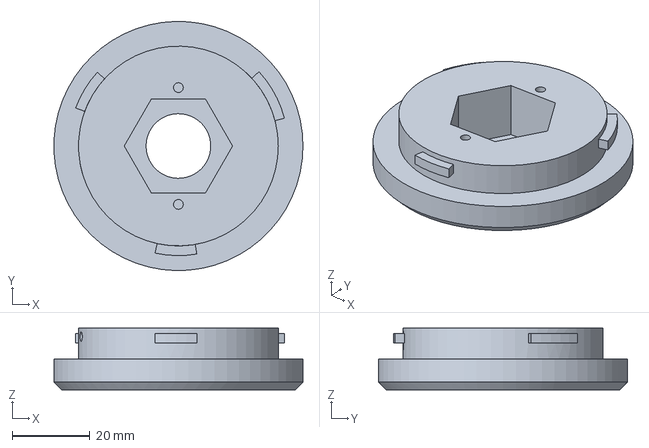
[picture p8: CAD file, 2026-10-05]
mechanical/v2.2/generated/step/01-threaded-base.step
64.0 x 64.0 x 15.9 mm

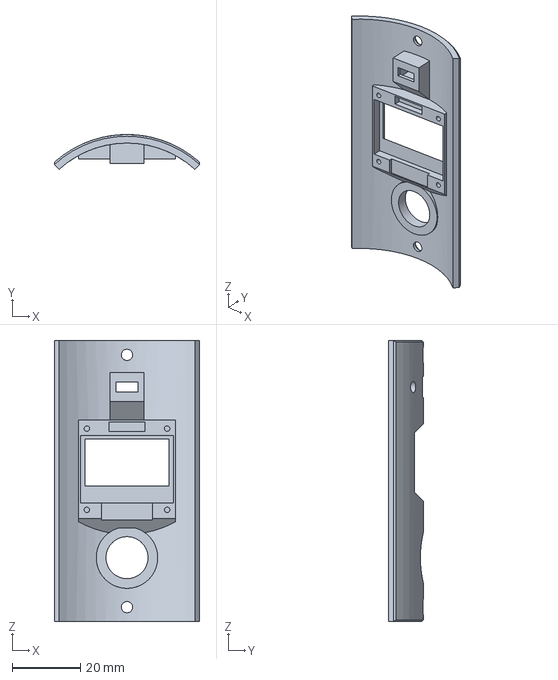
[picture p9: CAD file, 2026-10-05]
mechanical/v2.2/generated/step/05-panel-cover.step
42.5 x 10.2 x 82.3 mm

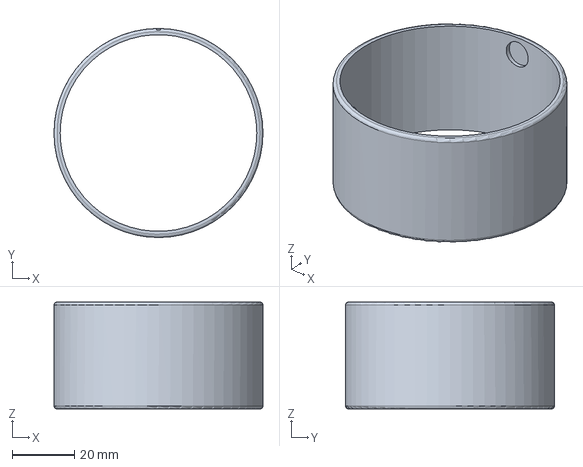
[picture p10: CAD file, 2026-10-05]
mechanical/v2.2/generated/step/06-bumper-bottom.step
67.4 x 67.4 x 34.5 mm

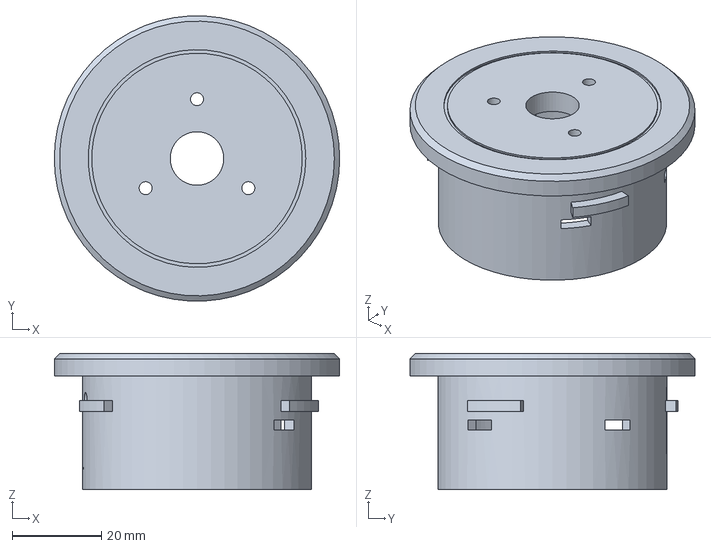
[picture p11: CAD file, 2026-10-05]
mechanical/v2.2/generated/step/03-antenna-cap.step
64.0 x 63.9 x 30.5 mm

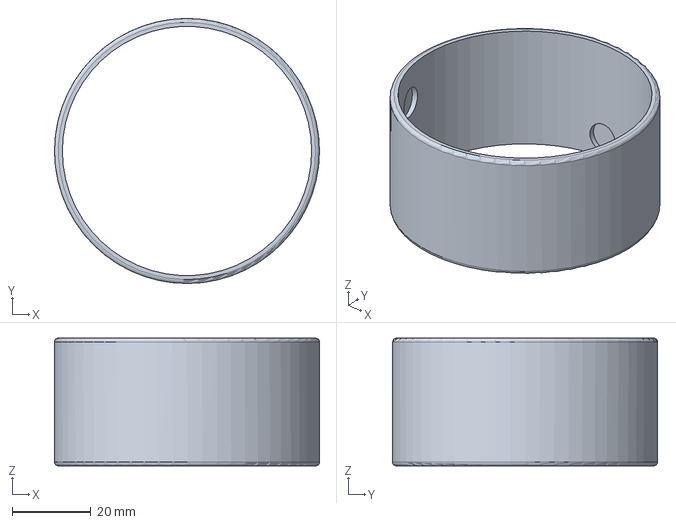
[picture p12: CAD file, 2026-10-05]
mechanical/v2.2/generated/step/07-bumper-top.step
67.4 x 67.4 x 32.5 mm

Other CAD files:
mechanical/v2.2/generated/stl/01-threaded-base.stl
mechanical/v2.2/generated/stl/02-logo-tube.stl
mechanical/v2.2/generated/stl/03-antenna-cap.stl
mechanical/v2.2/generated/stl/04-imu-platform.stl
mechanical/v2.2/generated/stl/05-panel-cover.stl
mechanical/v2.2/generated/stl/06-bumper-bottom.stl
mechanical/v2.2/generated/stl/07-bumper-top.stl

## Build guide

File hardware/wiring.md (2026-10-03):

# Cableado vigente — Thing Plus ESP32-S3 + UM980 + OLED

Revisión del 2 de octubre de 2026. Placa definitiva seleccionada por el propietario: **SparkFun Thing Plus ESP32-S3, WRL-24408**, con OLED Tecneu I2C de 0.96 pulgadas y 128×64. Firmware **0.8.0**. Sustituye el cableado de la Tiny de las notas de septiembre. La integración del Soft Power Switch Mk2 ya está implementada. Batería confirmada: **LiPo 1S, 3.7 V, 3000 mAh**. Falta identificar el elevador de 5 V del UM980; el arnés portátil completo no está validado.

## Conectar ahora

Hacer las conexiones sin alimentación y seguir los nombres impresos en cada módulo, no el orden de los pines de otra fotografía. Los números de esta tabla son GPIO, no posiciones en la hilera.

| Pin del módulo | Pin de la Thing Plus | Función |
| --- | --- | --- |
| UM980 **TTL_TXD2** | **RX / RXI — GPIO44** | Del GNSS al ESP32. |
| UM980 **TTL_RXD2** | **TX / TXO — GPIO43** | Órdenes y RTCM del ESP32 al GNSS. |
| UM980 **GND** | **GND** | Referencia común de señales. |
| OLED **VCC** | **3V3 / 3.3V** | Alimentación a 3.3 V. No usar V_USB/5 V. |
| OLED **GND** | **GND** | Tierra común. |
| OLED **SDA** | **SDA — GPIO8** | Datos I2C. |
| OLED **SCL** | **SCL — GPIO9** | Reloj I2C. |

El UM980 conserva su puerto **COM2 a 115200 baud, 8N1**. Se emplean los terminales **TTL** de la carrier BDLX ya utilizados con la Tiny; **no** los terminales RS232. El ESP32 espera señales de 3.3 V. El historial confirma comunicación, pero no una medición eléctrica independiente de esa carrier.

Por ahora, alimentar **Thing Plus por su USB-C** y **carrier UM980 por su propio USB**, como en el banco anterior. Compartir GND, sin unir sus líneas de 5 V, batería ni reguladores de 3.3 V. La alimentación del GNSS desde la batería del instrumento requiere un elevador todavía no identificado. No alimentarlo desde el pin 3V3 de la Thing Plus por inferencia del pinout.

El conector Qwiic también lleva SDA/SCL/3.3 V/GND. Puede usarse un cable Qwiic a terminales para la OLED, respetando las señales. Basta una de las dos formas de conexión.

## microSD integrada

Insertar la tarjeta en el **socket de la propia Thing Plus**, antes de encender. No se usa el lector SPI externo de la compra anterior. El firmware monta FAT32 sin formatear automáticamente. La tarjeta debe permanecer puesta durante la sesión; después de extraerla/reinsertarla, reiniciar el equipo para volver a montarla.

| Señal interna | GPIO |
| --- | --- |
| CLK | 38 |
| CMD | 34 |
| D0 / D1 / D2 / D3 | 39 / 40 / 47 / 33 |
| Detección de tarjeta | 48, HIGH cuando está insertada |

Estas conexiones ya están en el PCB; **no se cablean ni se reutilizan para otros módulos**. El backend usa SD_MMC a cuatro bits y 20 MHz. Una sesión empieza como `stream.part`; solo termina como `stream.bin` tras el cierre sin pérdidas. La extracción durante una grabación no se considera un cierre correcto. No se ha ensayado todavía el comportamiento físico de una tarjeta retirada.

## OLED

El driver configurado es **SSD1306**, con detección de dirección **0x3C o 0x3D**. Se eligió según la ficha de Tecneu del módulo de cuatro pines; la publicación de Mercado Libre no fue accesible para inspección automatizada. La ficha dice SSD1306 «o compatible»: queda pendiente confirmar la unidad entregada. Un ACK I2C confirma dirección, no modelo de controlador; si responde pero no dibuja, revisar esa compatibilidad antes de cambiar cableado.

La pantalla muestra versión, calidad GNSS, satélites, fuente/edad de RTCM, grabación y dirección IP. El FIX caduca a los dos segundos sin nuevas GGA, igual que el paquete de salud. No presenta FIX como precisión garantizada. Si la pantalla no responde, el firmware continúa con GNSS, BLE, USB y Wi-Fi; vuelve a buscarla cada segundo desde una tarea independiente.

`GET /api/status` informa `subsystems.display` con estado, dirección, controlador y GPIO, y `subsystems.microsd` con disponibilidad, detección y estado de grabación. Sin OLED o tarjeta no se inventan estados de éxito.

## Pines reservados y trabajo pendiente

- **GPIO19/20:** USB nativo; sin cables de sensores.
- **GPIO45:** enable del regulador de periféricos integrado. El firmware lo mantiene alto para I2C/microSD; esto no implementa apagado del equipo. Conservar los jumpers como vienen de fábrica.
- **GPIO0/46:** BOOT/LED de estado y RGB integrados; sin nuevas conexiones.
- **MAX17048 en 0x36:** lectura de voltaje y porcentaje cada segundo, desde la misma tarea I2C que la OLED, incluso sin pantalla. No se reinicia el medidor al arrancar.
- **Soft Power Switch Mk2:** PUSH a A0/GPIO10; OFF a A1/GPIO14. Secuencia y límites abajo.
- **IMU BMI088, PPS y radio:** siguen pendientes de identificar/integrar; esta revisión no les asigna pines ni habilita sensores inexistentes.

## Primera instalación

Conectar solamente la **nueva Thing Plus** por USB-C y cargar el perfil `esp32s3_usb`, que ahora usa la definición local `sparkfun_thing_plus_esp32s3`. No cargar este binario a la Tiny: los GPIO son distintos.

```sh
cd firmware/esp32
pio run -e esp32s3_usb
pio run -e esp32s3_usb -t upload --upload-port PUERTO_DE_LA_THING_PLUS
```

La segunda orden es una instrucción para el montaje: no se ejecutó durante esta adaptación. En una placa nueva, el cargador gráfico necesita **Instalación completa**. Si no entra al cargador: mantener BOOT, pulsar y soltar RESET, soltar BOOT y volver a buscar el puerto. La consola del instrumento usa el USB nativo, no ocupa RX44/TX43.

Comprobar después: versión 0.8.0 e identidad `tresvizo-thingplus-s3-4m-v1`, PSRAM detectada, pantalla con datos y microSD disponible. Verificar GNSS con antena conectada y cielo visible; probar una grabación corta y cerrarla antes de retirar la tarjeta. Estas comprobaciones físicas siguen pendientes.

El panel, en Diagnóstico, informa la placa, OLED y microSD. La prueba física `tests/hardware_smoke.py` admite `--require-oled --require-sd` para exigir pantalla y tarjeta detectadas; cambia temporalmente ajustes y reinicia el equipo. No se ejecutó en esta adaptación. La respuesta I2C no sustituye comprobar que la OLED dibuja correctamente.

## Referencias

- [Esquema oficial SparkFun, revisión v1.0](https://cdn.sparkfun.com/assets/5/e/6/5/0/SparkFun_Thing_Plus_ESP32-S3.pdf): redes UART/I2C, SDIO y regulador de periféricos.
- [Hardware y pinout de la Thing Plus](https://docs.sparkfun.com/SparkFun_Thing_Plus_ESP32-S3/hardware_overview/).
- [Ejemplos oficiales SparkFun](https://docs.sparkfun.com/SparkFun_Thing_Plus_ESP32-S3/arduino_example/): USB CDC/JTAG, PSRAM Quad, GPIO45 y detección de tarjeta.
- [Ficha Tecneu: OLED 0.96 I2C de cuatro pines](https://www.tecneu.com/products/modulo-de-pantalla-led-oled-7-pin-0-96-i2c): 128×64, alimentación 3.3–5 V, SSD1306 o compatible. Aquí se usa 3.3 V.
- [Soft Power Switch comprado](https://www.sparkfun.com/sparkfun-soft-power-switch-jst-2mm.html), pendiente de integración.
- [Historial del enlace TTL con UM980](../docs/gnss-bringup.md).

## Batería, carga y encendido/apagado

La batería actual es **LiPo 1S 3.7 V, 3000 mAh** (11.1 Wh nominales). Sustituye la referencia anterior de 5000 mAh. Capacidad declarada, no medida; comprobar polaridad y protección del pack. No conectar una celda LiHV ni varias en serie.

| Origen | Destino | Condición |
| --- | --- | --- |
| LiPo + / − | Soft Power Switch **IN + / GND** | Verificar polaridad del JST con multímetro. |
| Switch **OUT + / GND** | JST de batería de Thing Plus **+ / −** | No conectar a 3V3 ni V_USB. |
| Switch **PUSH** | Thing Plus **A0 / GPIO10** | Entrada activa baja, pull-up interno a 3.3 V. |
| Switch **OFF** | Thing Plus **A1 / GPIO14** | Mk2: HIGH corta, LOW permite funcionar. |
| Pulsador externo, opcional | **BTN ↔ GND** del switch | Pulsador momentáneo normalmente abierto. |
| USB-C de Thing Plus | Fuente USB de 5 V | Alimentación USB y cargador integrado. |
| Qwiic negro / rojo | OLED **GND / VCC** | 0 V / 3.3 V. |
| Qwiic azul / amarillo | OLED **SDA / SCL** | GPIO8 / GPIO9; seguir señales, no orden físico de la OLED. |
| Futuro elevador **5 V regulados** | Entrada USB de alimentación de la **carrier UM980** | **Pendiente del modelo del elevador y confirmación de carrier. No cablear un VIN desconocido.** |
| UM980 TTL_TXD2 / TTL_RXD2 / GND | Thing Plus RX44 / TX43 / GND | COM2, 115200, señales TTL; no RS232. |

El cargador MCP73831 trabaja por hardware. Su STAT va al LED de carga, no a un GPIO; no soldarlo directamente al ESP32: ese circuito incluye VUSB. El firmware no puede activar/desactivar la carga ni cambiar su corriente. La guía indica 214 mA y el esquema publicado muestra R16=2 kΩ / 500 mA: comprobar la revisión y R16 de la unidad antes de fijar corriente o tiempo de carga. No se presupone una carga de 1 A por tener 3000 mAh.

El Soft Power Switch permite el retorno de corriente del cargador hacia la batería según SparkFun. **No es un power-path ni un cargador**. Con USB conectado la Thing Plus sigue encendida aunque se corte el switch. Un elevador colgado del nodo de batería puede consumir corriente del cargador y afectar su terminación; no considerar resuelta la carga simultánea con el UM980. El elevador elegido necesita revisar EN, bloqueo de corriente inversa, consumo, tensión mínima y distribución. No unir dos salidas de 5 V ni alimentar UM980 desde 3V3 de Thing Plus. Hasta resolverlo, mantener el banco con los USB independientes y tierra común.

Secuencia implementada: soltar el botón de encendido; después sostenerlo **2 s** para apagar, o usar «Apagar dispositivo» en el panel. Se bloquean nuevas operaciones, se drena la cola de grabación, se cierra archivo/manifiesto y sólo entonces se lleva OFF a HIGH. Durante OTA se rechaza el apagado por software. Si el almacenamiento no termina de cerrar, no se fuerza el corte por temporizador. El botón físico puede forzarlo tras aproximadamente **10 s** y perder datos: esa función de hardware no la puede impedir el firmware.

Si sigue llegando alimentación tras solicitar OFF, OLED y API lo indican. No se afirma «apagado» ni se identifica USB sin medirlo. El equipo queda bloqueado para nuevas operaciones hasta reiniciar o quitar alimentación externa; no es un modo de suspensión. La batería se muestra como estimación de porcentaje/voltaje; «cargando», presencia de batería y presencia de USB quedan desconocidos, porque la placa no proporciona esas señales al firmware. Con USB, VBAT puede tener tensión sin una celda conectada. El aviso de batería baja (≤10 % o ≤3.4 V) no sustituye la protección del pack; no hay corte automático por una lectura del medidor.

Fuentes: [esquema oficial Thing Plus](https://github.com/sparkfun/SparkFun_Thing_Plus_ESP32-S3/blob/main/docs/assets/board_files/SparkFun_Thing_Plus_ESP32-S3.pdf), [guía Thing Plus](https://docs.sparkfun.com/SparkFun_Thing_Plus_ESP32-S3/hardware_overview/), [guía Soft Power Mk2](https://docs.sparkfun.com/SparkFun_Soft_Power_Switch_Mk2/single_page/), [driver de referencia MAX1704x](https://github.com/sparkfun/SparkFun_MAX1704x_Fuel_Gauge_Arduino_Library).

Validación pendiente en hardware: carga real, polaridades, lectura del medidor, caída de tensión, apagado con y sin USB, cierre con grabación activa, consumo total/picos de UM980 y compatibilidad de su alimentación. Las pruebas de compilación y lógica no reemplazan estos ensayos.

### Verificación de alimentación de la carrier BDLX

La [tabla publicada por BDLX](https://www.bdlxgnss.com/static/upload/image/20250804/1754279536807539.png) especifica **4.0–5.5 V, típico 5.0 V** para su placa UM980. La [fotografía posterior del mismo producto](https://www.bdlxgnss.com/static/upload/image/20250804/1754279537213094.png) muestra la revisión **RTK_UM98_V1.0.1** y el terminal **5V_IN**, coincidentes con la identificación conservada. La entrada externa de esta carrier no debe confundirse con VCC del módulo UM980: [Unicore especifica 3.0–3.6 V](https://en.unicore.com/uploads/file/UM980_User%20Manual_EN_R1.7.pdf) para el módulo sin carrier.

Una LiPo convencional llena puede alcanzar 4.2 V y hacer arrancar la carrier, pero al bajar de 4.0 V queda fuera del rango publicado; arrancar no valida la descarga completa. Para la alimentación portátil a través de esta entrada se mantiene la necesidad de regulación: OUT del switch → elevador 5 V → **5V_IN de la carrier**, con GND común. Modelo del elevador y gestión de fuentes simultáneas pendientes; no conectar simultáneamente 5V_IN y USB sin verificar el aislamiento de la placa.

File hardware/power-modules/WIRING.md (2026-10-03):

# Arnés del prototipo

> **Histórico — 02/10/2026:** esta propuesta corresponde a la Tiny. La placa definitiva es Thing Plus ESP32-S3 y el control del Soft Power Switch está implementado; la distribución portátil del UM980 sigue pendiente. No aplicar este arnés al montaje nuevo; consultar [cableado vigente](../wiring.md).

Usar con las limitaciones de [README](README.md). Es cableado entre módulos, no un nuevo esquemático de PCB. Todos los nombres siguientes son señales funcionales, no números de contactos FPC ni una asignación nueva de GPIO.

## Alimentación

| Origen | Destino | Observación |
| --- | --- | --- |
| USB-C exterior de Adafruit 5871, VBUS | Fusible de entrada → `CHARGE_LINK` → pad **USB** del PowerBoost | No al pad 5V. Jumper/cable desmontable de carga, dimensionado al menos 2 A. Abierto para datos desde un puerto de capacidad desconocida. |
| Batería protegida, positivo/negativo verificados | BAT/GND o conector de batería del PowerBoost | No identificar polaridad por color o por el aspecto del conector. Fusible del ramal próximo al pack. |
| PowerBoost **VS** | SparkFun **VIN** | VS es la salida del power-path, no BAT ni la salida del elevador. |
| SparkFun **VOUT** | PowerBoost **EN** | Añadir 10 kΩ EN–GND. Mantener esta unión corta. |
| PowerBoost **5V** | `SYSTEM_5V` → fusible de salida → distribución | Aproximadamente 5.2 V. Dejar sin montar el conector USB-A que viene suelto. |
| Masas de los tres módulos y cargas | GND común | Sin aislamiento galvánico. |

Fusibles comerciales en línea: punto de partida 2 A en entrada USB, 3 A en batería y 1 A en distribución; ajustar tipo/curva con los picos medidos y la capacidad del cable/pack. No confundirlos con limitación precisa de corriente USB ni con protección de la celda. El fusible integrado del SparkFun, en esta conexión de control EN, **no protege la salida principal**.

Usar cable de potencia corto, inicialmente 22–24 AWG, y arnés USB 2.0 apantallado. Mantener la batería próxima al cargador; la guía recomienda menos de unas tres pulgadas en su conexión. Las ramas de datos deben conservar el par y la masa; evitar conexiones Dupont largas o protoboard en la ruta USB.

## Conectar Tiny sin alterar el FPC

Se conserva el **Tiny-Adapter y el FPC original de la unidad**. El cable interno hacia el USB-C de ese adaptador se hace a partir de un cable USB 2.0 de datos corto con extremo USB-C macho; se identifica cada conductor por continuidad, sin dar por cierta una convención de colores.

| Conductor del USB-C macho interno | Conectar a |
| --- | --- |
| D+ | D1+ del TS3USB30 |
| D− | D1− del TS3USB30 |
| GND | GND común |
| VBUS del cable interno | **SYSTEM_5V**, después de su protección de salida |

**Los pads VBUS/V+ de ambos canales del TS3USB30 quedan sin conectar al cable interno.** Comparten eléctricamente el VBUS del puerto exterior. Un cable de cuatro hilos directo desde ese módulo al Tiny-Adapter anularía el apagado y podría unir las dos alimentaciones. Aislar y sujetar individualmente las derivaciones.

El [Tiny-Adapter oficial](https://files.waveshare.com/wiki/ESP32-S3-Tiny/Tiny-Adapter.pdf) lleva los datos al FPC y conserva BOOT/RUN. El [plano Tiny](https://files.waveshare.com/wiki/ESP32-S3-Tiny/ESP32-S3-Tiny-Sch.pdf) es de una variante que no certifica la N8R8 física; por eso se reutiliza el conjunto original, sin fabricar otro conector ni trasladar numeración supuesta. El adaptador queda dentro del equipo y su puerto no es un segundo puerto exterior.

## Desconexión de datos y presencia del USB

El [esquema del Adafruit 5871](https://github.com/adafruit/Adafruit-TS3USB30-PCB) tiene `S` a 3.3 V mediante 47 kΩ y `/OE` a GND mediante 47 kΩ. Se usa el canal 1 para Tiny y se deja **todo el canal 2 sin cablear**.

- Q1: NPN de señal, por ejemplo PN2222A. Emisor a GND; colector a S. Base desde **3V3 de la Tiny** mediante 47 kΩ y 100 kΩ base–emisor. Con Tiny encendida selecciona canal 1; apagada queda canal 2 vacío. La base usa la alimentación de la placa, no un GPIO que cambie durante ROM/debug.
- `/OE` se mantiene en su estado predeterminado bajo. La alimentación del switch procede exclusivamente del USB exterior por su regulador incorporado. Su función Ioff limita la fuga con VCC=0; no es una garantía de comportamiento a cualquier tensión intermedia.
- Q2 opcional para información de presencia: base desde 3.3 V **del módulo USB** por 47 kΩ, 100 kΩ base–emisor; emisor GND; colector hacia `USB_PRESENT_N` con pull-up de 10 kΩ a 3V3 de Tiny. No une ambas fuentes de 3.3 V. Permite leer presencia de alimentación USB sin poner 5 V en el ESP32. **No es el detector calibrado VBUS_VALID** exigido para conformidad USB.

La desconexión con host ausente y el estado intermedio al descargar sus condensadores necesitan ensayo. Para TinyUSB, añadir/configurar el detector indicado en README; para Serial/JTAG o ROM, cualquier corrección que deba funcionar con firmware detenido debe ser autónoma. No considerar resuelto el límite de 3 ms por este circuito básico.

## Botón y firmware

| Señal | Conexión |
| --- | --- |
| Pulsador momentáneo | Entre BTN y GND del SparkFun; confirmar qué terminales cambian de abierto a cerrado. |
| PUSH | Entrada ESP32 con pull-up a su propia 3V3; estado activo bajo. |
| OFF | Salida ESP32, iniciar en LOW. HIGH solicita el corte al Mk2. |

El firmware debe esperar la liberación de la pulsación de arranque. Una petición posterior de apagado detiene adquisición, cierra/sincroniza microSD, guarda lo necesario y finalmente eleva OFF. No poner primero OFF y después intentar cerrar archivos. La pulsación larga de emergencia puede perder el último registro: es un corte independiente.

No se ha implementado esa secuencia aquí ni elegido nuevos números de GPIO. La asignación se cruza con UART/PPS del GNSS, SPI/SD e IMU existentes al cablear. La placa de encendido no necesita que el ESP32 mantenga una señal HOLD durante una sesión JTAG. [Guía Mk2](https://docs.sparkfun.com/SparkFun_Soft_Power_Switch_Mk2/single_page/).

## Indicadores

El RGB seleccionado es [Steren LED-5/RGB](https://www.steren.com.mx/led-de-5-mm-rgb.html), de ánodo común; reemplaza al Adafruit 159. Steren publica 1.8 V rojo y 2.8 V verde/azul. Se conservan tres NPN como sumideros para usar la alimentación conmutada de 5 V sin llevarla a los GPIO: ánodo a SYSTEM_5V; emisor a GND, colector al cátodo a través de **1 kΩ**, base desde GPIO a través de **4.7 kΩ** y **100 kΩ** base–emisor. Corrientes nominales de unos 2–3 mA por color con 5.2 V, sujetas a Vf y saturación reales. Se puede montar y aislar este pequeño arnés sin encargar PCB. Identificar E/B/C con la ficha del transistor comprado; no intercambiar pinouts de PN2222A y 2N3904 por apariencia.

Las resistencias limitan cada canal a unos pocos mA. Ajustar brillo por PWM después de probar la ventana óptica, especialmente a la luz del día. Estado propuesto: azul conexión, verde solución válida según el firmware, rojo aviso. El LED por sí solo no certifica precisión GNSS. Al apagar, la alimentación del RGB desaparece.

Para carga, llevar luz del LED amarillo del PowerBoost a la ventana CHG mediante guía óptica. Si se desea visualizar fin de carga, incorporar también su LED verde a esa ventana con dos trayectos ópticos. No puentear ambos LEDs eléctricamente, no conectar sus salidas al ESP32 y no confundir ausencia de luz con batería llena. Su alimentación es independiente del encendido del equipo. [Pinouts y LEDs PowerBoost](https://learn.adafruit.com/adafruit-powerboost-1000c-load-share-usb-charge-boost/pinouts).

## Comprobación del montaje

Antes de conectar computadora: verificar separación USB_VBUS/SYSTEM_5V, masas, polaridad, EN alto/bajo, apagado con USB presente y ausencia de tensión suministrada hacia el puerto exterior desde batería. Medir también con resistencias de carga; una lectura en vacío no descarta corriente de retorno.

Después: arranque con GNSS/Wi-Fi/SD, consumo/tensión de entrada y salida, temperatura de cargador/celda, pulsación corta/larga, cierre de archivo y recuperación BOOT/RUN. Probar USB en ambas orientaciones, flashing, consola y JTAG; conectar/desconectar con firmware detenido y comprobar tiempos de VBUS/datos. Ninguna de esas pruebas físicas se ha ejecutado durante esta entrega.

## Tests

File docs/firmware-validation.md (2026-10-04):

# Validación inicial del firmware

Fecha: 19 de septiembre de 2026. Versión del instrumento: 0.1.0. Estas comprobaciones cubren la base de control; no validan un receptor RTK ni precisión topográfica.

## Equipo y preparación

- El propietario confirmó que el ESP32 era el único equipo conectado por USB y que ningún módulo externo estaba cableado.
- esptool 4.9.0 identificó ESP32-S3 QFN56 revisión 0.2, flash XMC integrada de 4 MB y PSRAM AP de 2 MB; flash quad a 3.3 V. La variante Tiny seleccionada en la captura concuerda con esas capacidades.
- Se leyó la flash completa antes de la primera carga: 4,194,304 bytes. Respaldo privado en `logs/local/esp32-before-first-flash.bin`, excluido del historial.
- SHA-256 del respaldo: `a604c71d12946300e9a16ff0ac53d4fd650569a501baa30e31f09b6edef29dfb`.
- Perfil de arranque con flash DIO de 4 MB y PSRAM desactivada. No se inicializaron interfaces externas.

## Comprobaciones realizadas

| Área | Evidencia |
| --- | --- |
| Compilación | `pio run` y carga con PlatformIO Espressif32 6.12.0, Arduino-ESP32 2.0.17 y ArduinoJson 7.4.2 completados. |
| Tamaño final | 762,457 bytes de programa (38.8% de la partición de aplicación de 1,966,080 bytes) y 44,280 bytes de RAM estática. El uso dinámico se comprueba por separado. |
| Carga USB | esptool escribió el firmware y verificó los hashes de los segmentos. Reinicio posterior realizado. |
| Validadores locales | Prueba C++ compilada con Clang y `-Wall -Wextra -Werror`: límites, caracteres, tipos admitidos y temporizadores con desbordamiento de 32 bits. |
| JavaScript | `node --check` sin errores de sintaxis. |
| Hardware real | `tests/hardware_smoke.py`: 28 comprobaciones superadas. Incluyen estado, ausencia de datos GNSS simulados, autenticación, campos inválidos, límites, conflictos de revisión, persistencia, reinicios, recuperación del parser y restauración de ajustes. |
| Buffer USB | Una prueba inicial de mensaje de 1200 bytes detectó pérdidas con la cola predeterminada de 256 bytes. Se configuró una cola de 2048 bytes, manteniendo el límite lógico de 1024; la prueba posterior verificó rechazo 413 y recuperación. |
| Memoria dinámica | Veinte consultas consecutivas devolvieron más de 100 KB libres. Esta prueba corta no demuestra estabilidad prolongada. |
| Panel conectado | Navegador mediante puente USB local: datos reales, navegación, edición del intervalo, guardado y recuperación tras recargar. Se restauró el intervalo de 2000 ms. |
| Adaptación móvil | Inspección visual en escritorio y viewport de 390 × 844. Navegación móvil ajustada para mostrar las cuatro secciones. |
| Pérdida del enlace web | Al detener el puente se mostró “Sin conexión” y los valores dinámicos pasaron a `—`. Al restablecerlo, el panel recuperó automáticamente el enlace. |
| Puente local | Siete comprobaciones HTTP: recursos accesibles, cabecera de cliente obligatoria, rechazo de Host/Origin ajenos, ruta de credenciales inaccesible y recorrido fuera del directorio rechazado. |
| Identidad visual | Logo original del sitio y paleta documentados en `firmware/esp32/web/assets/README.md`. Recursos locales empaquetados en flash. |

El diagnóstico en ejecución expone lo que informa la versión de SDK utilizada. Su campo de revisión de chip puede mostrar la revisión mayor (`0`) y no la revisión completa `0.2` de esptool. El código de motivo de reinicio `0` significa que el SDK no lo identificó; no se presenta como un reinicio normal confirmado.

## Límites y pruebas pendientes

- El panel se verificó por el puente USB, que sirve los archivos locales y transporta solicitudes al firmware real. Esto no sustituye una prueba de descarga de recursos HTTP directamente desde el ESP32 por radio.
- Se comprobó que el controlador inició su AP. Quedan pendientes conexión de teléfono al AP, autenticación por HTTP directo y conexión/reconexión a un hotspot real.
- Límites HTTP implementados, pero pruebas de tráfico lento, saturación y carga concurrente sobre Wi-Fi directo pendientes.
- Sin ensayos prolongados de memoria, consumo, temperatura, brownout ni interrupción de alimentación durante escritura NVS.
- GNSS, RTCM, NTRIP, BMI088, sincronización, microSD, apagado coordinado y BLE sin implementar ni probar. No hay pruebas de campo ni de exactitud.
- El módulo biestable no está integrado y no demuestra cierre seguro de registros ni protección/carga de batería.

## Repetición

Los comandos y precauciones específicas del puerto están en el [README del firmware](../firmware/esp32/README.md). La prueba de hardware cambia temporalmente nombre e intervalo y reinicia el ESP32; debe ejecutarse con el puente y otros monitores cerrados. Cada nueva integración requiere pruebas propias, además de estas comprobaciones de base.

## Actualización 0.2.0 — 19 de septiembre de 2026

- Compilación y carga al ESP32 completadas. Flash de programa: 766293 bytes; RAM estática: 44280 bytes.
- Cambio de clave por USB aplicado en NVS y comprobado después del reinicio, sin incluir la credencial en el repositorio. AP iniciado con la nueva configuración y autenticación USB verificada. Contraseñas cortas, mayores de 63 caracteres, NUL incrustado y solicitud no autenticada rechazadas.
- Las 28 comprobaciones de `tests/hardware_smoke.py` volvieron a pasar sobre 0.2.0, incluidos reinicios y restauración de ajustes.
- `node tests/gnss_panel_test.js`: coordenadas cero válidas, referencia de altura, ausencia de posición, datos antiguos y desconexión. Sintaxis JS/Python comprobada.
- Panel local recargado y revisado en navegador: versión 0.2.0, conectado al ESP32, sin enlace GNSS y sin coordenadas inventadas.
- El UM980 por USB a la Mac entrega UTC a 10.00 Hz en el segmento continuo observado, con 0 duplicados y máximo intervalo de llegada de 102 ms. Se detectó una discontinuidad inicial de hora. No hubo solución válida: calidad 0, satélites usados 0. Son épocas de mensajes, no diez posiciones válidas por segundo.
- Quedan pendientes prueba Wi-Fi desde otro cliente con la nueva clave, cableado y adquisición física UART, BLE, RTCM y sensores. El refresco HTTP sigue siendo diagnóstico, no la tasa de adquisición.

## Actualización 0.3.0 — apartados de registro/base/NTRIP

- Compilación y carga verificadas. Captura de GNSS y modo del receptor no modificados en esta entrega.
- `tests/operations_smoke.py`: 27 comprobaciones de capacidades, coordenadas, límites, tipos, autenticación, altura ARP sin doble suma y conservación de ajustes. La primera ejecución detectó un error de comparación en la prueba (ID de solicitud variable); se corrigió para comparar el cuerpo de configuración y la ejecución posterior pasó.
- `base_plan_test.cpp`: límites y cálculo con AddressSanitizer/UndefinedBehaviorSanitizer. Pasó también `tests/gnss_panel_test.js`.
- Navegador: revisados los tres apartados, controles pendientes deshabilitados y un plan sintético con altura del punto 100 m + antena 2 m que devolvió ARP 102 m. Plan de prueba retirado recargando, sin persistencia ni aplicación al GPS.
- Ajustada y revisada visualmente la navegación de siete apartados en pantalla estrecha. Grabación real, RINEX, aplicación de base y conexiones NTRIP no probadas porque sus controladores siguen pendientes.

## Actualización 0.4.0 — OTA, BLE y banco USB

- Compilación del firmware estándar y de la variante UART con GPIO 18/17 completadas. Solo se cargó la variante estándar, sin habilitar GPIO externos. Nueva imagen instalada por OTA en `app0`, arranque confirmado y ajustes NVS idénticos antes/después.
- `tests/hardware_smoke.py`: 29 comprobaciones en placa; `tests/operations_smoke.py`: 27. `tests/update_smoke.py --install`: 27 comprobaciones de rechazo/abortado y actualización completa. Incluyen hardware/tamaño/hash inválidos, autenticación, duplicados, offsets, imagen incompleta y rechazo de restauración de un candidato inválido.
- Cargas posteriores mostraron reinicios `USB_UART_CHIP_RESET`, perdiendo la sesión antes de activar el candidato. Se añadió exclusividad del dispositivo (`TIOCEXCL`, además del flock de pyserial) y diagnóstico de arranque al cliente USB. La siguiente carga completa pasó. Esto no demuestra todavía la causa externa exacta ni resistencia prolongada a desconexiones. No abrir monitores simultáneos; una transferencia interrumpida se inicia de nuevo.
- CRC/fragmentación RTCM3 C++ con AddressSanitizer/UndefinedBehaviorSanitizer; 14 pruebas Python de banco GNSS y 3 de NTRIP por sockets reales de loopback; pruebas de render GNSS y sintaxis JS superadas.
- Registro real del UM980: 393285 bytes, cero pérdidas de cola, 105 observaciones binarias con CRC válido. Conversión RTKLIB produjo RINEX 3.04 con 105 épocas OBS y 35 registros NAV. No constituye procesamiento PPK ni validación de precisión.
- BLE iniciado en el ESP32 y capacidades consultadas; pendientes emparejamiento de un cliente real, latencia/rendimiento y transferencia de correcciones hasta el GPS. NTRIP se ejecuta en banco Mac, no en firmware ESP32.
- Pendientes: Wi-Fi OTA con cliente independiente, restauración manual de ida/vuelta, fallo inducido antes de confirmar arranque, firmas de distribución, base real, caster externo, UART cableado, microSD e IMU. No se exige posición GNSS para confirmar un arranque: el receptor fue trasladado al interior.

## Validación UART física — 0.4.1, 2026-09-20

Cableado confirmado por el propietario: GPS TTL_TXD2 → ESP32 GPIO18, TTL_RXD2 → GPIO17, GND común; alimentación USB separada sin unir los pines de alimentación. Perfil predeterminado actualizado. Compilación, OTA a app1 y conservación de ajustes comprobadas.

En 58.969 s entre muestras: 589 GGA nuevos (9.988 mensajes/s), cero rechazos, desbordes y errores UART; 332 consultas USB, todas en estado receiving. RAM libre final: 138024 bytes. Sin UTC ni posición válida en interior, por lo que esto demuestra transporte de mensajes cercano a 10 Hz, no diez soluciones de posición por segundo. Métricas locales sin coordenadas: captures/local/uart-20260920-validation.json.

El panel prioriza UART del ESP32 sobre el banco USB de la Mac. Pasaron las pruebas existentes de render GNSS y comprobaciones de sintaxis JS. Pendientes transmisión ESP32→GPS, correcciones reales, pérdidas bajo carga completa y persistencia del perfil COM2 tras apagar (no se envió SAVECONFIG).

## 0.5.0 — 2026-09-20: servicios autónomos y PSRAM

- PSRAM Quad habilitada: 2094703 bytes de heap utilizable; prueba de 1 MiB con tres patrones superada. RAM interna libre observada ~154 kB, PSRAM libre ~2066 kB. No implica que cada servicio futuro esté validado bajo carga simultánea.
- Control UART real: VERSIONA identificó UM980 R4.10Build13504; MODE confirmó rover; cambios de GGA a 5 Hz y 10 Hz verificados en recepción. Se deja 10 Hz. Base aplica planes validados pero coordenadas/convergencia siguen pendientes de prueba exterior. No se aplicaron coordenadas sintéticas.
- BLE físico con Mac: cifrado SC+MITM (auth mode 13), clave inválida rechazada, respuestas fragmentadas recompuestas, recuperación de credenciales bloqueada y consulta VERSIONA/MODE realizada por BLE→ESP32→UART. Repetido después de reinicios con PIN persistente. Telemetría con UTC y RTCM real por BLE pendientes.
- Cliente NTRIP Wi-Fi implementado y panel disponible. Validación de parámetros y espera sin red comprobadas; flujo real con caster pendiente de que el propietario configure su cuenta. Inicialmente v1/TCP, sin TLS/GGA para VRS; no confundir con servicio plenamente validado.
- Controlador SD de flujo original, cola, cierre, catálogo y lectura por bloques preparado. Perfil con SD compilado, pero nunca cargado; pines de esa compilación son solo para verificar código. El propietario confirma lector desconectado. Perfil instalado mantiene SD not_configured, sin conducir pines supuestos.
- Pruebas: 24 comprobaciones API de servicios; 27 de operaciones; 29 de hardware; 14 Python GNSS y 3 NTRIP de banco. Parser de binario con sanitizadores y render GNSS JS superados. Primera prueba corta de frecuencia capturó transición; se añadió estabilización y cálculo por tiempo real del ESP32: 4.96 y 10.12 Hz en ventanas de unos 5 s. Pruebas históricas se actualizaron para UART activo y respuesta 503 de SD ausente.
- Firmware instalado por OTA, arranque confirmado y ajustes conservados. Detalles y límites: [servicios del ESP32](esp32-services.md).

## 0.8.1 — 2026-10-04: arranque y reinicio de la OLED

Cambios implementados:

- La tarea de pantalla arranca antes de la inicialización de red, almacenamiento y BLE. El plazo único del logo es 10000 ms; no se reinicia al recuperar I2C. Si setup sigue ocupado al vencer, se muestra «INICIANDO».
- SSD1306 inicializado apagado, offset y geometría completos, framebuffer comprobado por transacción y encendido sólo al terminar los 1024 bytes. Se conserva alimentación estable de Qwiic y se usa I2C a 100 kHz.
- Consulta de almacenamiento sin espera desde la OLED. Reinicio de API y OTA coordinado con cierre de I2C, con límite de 300 ms. Peticiones de reinicio repetidas no prolongan el plazo y las nuevas escrituras se rechazan mientras se reinicia.

Comprobado:

- Compilación PlatformIO y firma verificadas. Carga directa por USB finalizada con verificación de hashes; lectura posterior confirma versión 0.8.1. SHA-256 de firmware-signed.bin: `a8dc81b5910d9d3b1f3bde26690baa958604d28f368124d2674176bb276805f1`.
- Configuración idéntica antes y después de la carga, comparada mediante SHA-256 del JSON canónico sin guardar sus credenciales en el informe.
- Pruebas nativas `display_boot`, `oled_transport`, `display_status` y `power_sequence` completadas con `-Wall -Wextra -Werror`. Las dos nuevas también pasaron con UndefinedBehaviorSanitizer. AddressSanitizer se bloqueó dentro de su inicialización en macOS, antes de entrar al programa; se terminó ese proceso y no se cuenta como prueba superada.
- 643 comprobaciones estáticas del contrato de apps superadas; permanecen las cuatro discrepancias previas documentadas en el contrato.

Limitaciones de la prueba física:

- El primer intento de OTA fue rechazado por el firmware anterior al activarse la reconciliación GNSS durante la transferencia. Se utilizó carga USB directa sin borrar NVS.
- Antes de la carga, 0.8.0 detectaba la OLED en 0x3C. Tras una primera variante que pulsaba la alimentación Qwiic, la OLED dejó de responder; esa maniobra fue retirada. No está confirmada la causa física ni se atribuye el fallo al cableado.
- En la última consulta con la versión final 0.8.1, el medidor MAX17048 responde, pero la OLED sigue en `not_detected`. No se pudo ejecutar la secuencia de tres reinicios ni confirmar visualmente el logo. Se solicitó retirar USB y batería durante cinco segundos y reconectar para comprobar un arranque desde cero.
- La prueba repetible está en `tests/display_boot_bench.py`. No se afirma resuelto en hardware el recorte ni medida la duración física del logo hasta completar ese ensayo y la comprobación visual.

## 0.8.2 — 2026-10-04: transporte con las apps

Se corrigieron avance de offset ante rechazo BLE, líneas vencidas interpretadas como otra orden, pérdida del `id` en errores 413, caducidad de posición al salir del WebSocket y bloqueo de OTA por tareas del arranque. También se verifican resultados de notificación, se coordina la respuesta antes de desactivar BLE y se añaden códigos NTRIP que las apps ya reconocen. Contrato y formatos conservados.

Compilado, firmado y cargado por USB con verificación de hashes. 32 suites C++ con UBSan, 86 pruebas del banco BLE, 35 del comprobador de contrato, 644 comprobaciones estáticas y 320 sobre el equipo por USB. El listado de sesiones no se validó: devolvió 503 sin tarjeta instalada.

Banco físico BLE: 246 respuestas completas en dos series de tres conexiones, cero errores de reensamblado. Con MTU 247: mediana 64.7 ms, P95 210.1 ms; recuperación de respuesta bloqueada en 4.54 s. Los descartes y timeouts provocados coincidieron con lo inyectado; sin fallos GATT ni envíos forzados. Configuración conservada. OTA parcial cruzó el umbral de arranque, aceptó un bloque duplicado y se canceló sin cambiar el slot activo; la partición inactiva de prueba se borró.

Wi-Fi físico no accesible desde la Mac y STA sin configurar; iPhone/Android, RTCM sostenido y OLED visual siguen pendientes. Detalles, reproducción y SHA-256 del binario final: [auditoría 0.8.2](connectivity/TRANSPORT_AUDIT_0.8.2.md).

## 0.8.3 — 2026-10-04: prioridad del operador

38 suites C++ con UBSan, 644 comprobaciones estáticas y 320 sobre el equipo. Cinco órdenes consecutivas aceptadas por USB en 6.0 ms de mediana; reinicio durante consulta aceptado en 4.7 ms. BLE: 123 respuestas, cero errores de reensamblado y P95 de 209.3 ms. Compilación, firma y carga USB terminadas. Configuración conservada.

NTRIP con caster real, RTCM sostenido, cambios de base con GNSS y OLED visual siguen pendientes. Informe, límites y reproducción: [prioridad 0.8.3](connectivity/OPERATOR_PRIORITY_0.8.3.md).

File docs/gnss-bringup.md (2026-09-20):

# Primera adquisición GNSS

## Estado

**Actualización 2026-09-20:** el propietario confirmó TTL_TXD2 → GPIO18, TTL_RXD2 → GPIO17 y GND común, sin unir alimentación; cada placa se alimenta por su USB. Firmware 0.4.1 habilita UART2 a 115200 y se instaló por OTA con arranque confirmado y ajustes conservados. El UM980 confirmó `CONFIG COM2 115200` y `GPGGA COM2 0.1` enviados por COM3 USB. No se envió SAVECONFIG; la persistencia del perfil GNSS tras apagar sigue pendiente. La identificación eléctrica de la carrier a 3.3 V no se ha medido con instrumental.

El panel principal prioriza la adquisición UART del ESP32; la lectura USB directa a la Mac permanece separada como banco. La recepción de GGA confirma GPS→ESP32. No demuestra todavía el enlace de transmisión ESP32→GPS, ni RTCM real, ni precisión. Las secciones siguientes conservan el historial anterior, cuando UART estaba desactivada.

El receptor conectado a la Mac responde a `VERSIONA` como UM980, firmware `R4.10Build13504`, por `/dev/cu.usbserial-1110` (USB 1A86:7523). El puerto físico puede cambiar al reconectar. Respondió `devicename,COM3` a 115200 baudios. El ESP32 continúa conectado por separado; los datos USB del GPS no llegan al ESP32 por el hecho de compartir la Mac.

El receptor aceptó `GPGGA 0.1` en su puerto actual. No se envió `SAVECONFIG`. La captura inicial posterior contiene mensajes GGA sin hora ni posición: esto demuestra comunicación, pero no demuestra diez posiciones distintas por segundo ni RTK. Las capturas y la respuesta completa de versión se guardan en `captures/local/`, excluido de Git.

## Código

- `firmware/esp32/lib/gnss/src/nmea_gga.h`: parser incremental compartido por firmware y herramienta de banco. Memoria fija; checksum obligatorio; validación de coordenadas, calidad, hora, unidades y números. Resincroniza al recibir `$` y descarta líneas demasiado largas. Un mensaje válido sin fix sustituye la posición anterior por datos ausentes.
- `firmware/esp32/src/gnss_receiver.cpp`: tarea UART dedicada, independiente del refresco HTTP, con buffer de recepción de 8192 bytes y snapshot protegido. Registra errores UART y de parser. No envía comandos al GPS.
- La adquisición física está desactivada en el perfil predeterminado: solo se activa al definir conjuntamente `TRESVIZO_GNSS_RX`, `TRESVIZO_GNSS_TX` y `TRESVIZO_GNSS_BAUD`, después de comprobar conexiones y niveles. No conectar señales RS232 directamente al ESP32.
- `/api/status` incorpora los contadores GNSS. Con UART habilitada distingue espera, recepción y datos antiguos; después de 500 ms sin GGA válido omite la solución vigente. No interpreta el código de calidad como garantía de precisión.
- GGA proporciona UTC de hora del día, no fecha; se conserva separado del tiempo monotónico de llegada. Altitud MSL y separación geoidal permanecen separadas. El datum y el modelo de geoide del receptor necesitan verificación. No equivale a sincronización PPS ni a latencia absoluta medida.

## Prueba de software

Desde la raíz del repositorio:

```sh
c++ -std=c++17 -Wall -Wextra -Werror -fsanitize=address,undefined -I firmware/esp32/lib/gnss/src firmware/esp32/test/nmea_gga_test.cpp -o /tmp/tresvizo-gga-test
/tmp/tresvizo-gga-test
```

## Captura pasiva USB

```sh
c++ -std=c++17 -Wall -Wextra -Werror -I firmware/esp32/lib/gnss/src tools/gnss_probe.cpp -o /tmp/tresvizo-gnss-probe
mkdir -p captures/local
/tmp/tresvizo-gnss-probe /dev/cu.usbserial-1110 captures/local/um980-new-session.nmea
```

Verificar el puerto antes de ejecutar. La herramienta abre el puerto en exclusiva a 115200 8N1 durante 60 s y no transmite comandos. No sobrescribe archivos existentes; crea la captura con permisos 0600. Rechaza puertos `usbmodem` para evitar confundir la consola ESP32 con GNSS en este banco.

Muestra mensajes aceptados/rechazados, duplicados, discontinuidades, frecuencia de épocas UTC y de llegada de épocas distintas. La frecuencia se refiere al segmento temporal continuo actual. Sin UTC no calcula una frecuencia de posiciones. Antigüedad y máximo intervalo de llegada se refieren a la Mac y pueden incluir agrupación por USB; no prueban latencia GNSS absoluta. Si no se informó el número de satélites muestra -1. Código de salida 2 indica que no se decodificó ningún GGA; 1 señala un error de puerto/archivo.

## Pendiente de banco

- Antena con cielo visible, solución válida y comprobación sostenida de 10 épocas distintas/s.
- Confirmar niveles TTL de la carrier y cablear UART al ESP32. Verificar la tasa/configuración de COM2 independientemente de COM3.
- Validar pérdidas, interrupciones UART, caída de alimentación, carga concurrente HTTP/BLE y microSD.
- BLE, RTCM/NTRIP, observaciones crudas/RINEX e IMU no se implementan en esta etapa de adquisición GGA.

## Fuentes

- [Unicore: comandos y estructura GGA para productos N4](https://en.unicorecomm.com/uploads/file/Unicore%20Reference%20Commands%20Manual%20For%20N4%20High%20Precision%20Products_V2_EN_R1.13.pdf).
- [Unicore: salida NMEA y periodos en productos NebulasIV](https://www.unicorecomm.com/assets/Html/N4/N4-NTRIP.html).
- [SparkFun: verificación de UM980 mediante VERSIONA](https://docs.sparkfun.com/SparkFun_UM980_Triband_GNSS_RTK_Breakout/verification/).

## Resultado de la captura de 60 segundos

La captura `um980-gga-validated.nmea` contiene 600 líneas GGA completas sin fix, además de una línea inicial con ruido previo al encabezado. El parser resincronizó; el último reporte periódico registró 594 GGA aceptados, 0 rechazos y 0 desbordes antes del cierre. Todos los GGA carecían de UTC y posición: hay salida de mensajes cercana a 10 Hz, pero aún no se han validado 10 soluciones/s.

Las pruebas del parser pasaron con AddressSanitizer y UndefinedBehaviorSanitizer. Compilaron el perfil predeterminado y la variante UART habilitada (solo compilación, sin cargar esta última). No se cargó nuevo firmware al ESP32 durante esta sesión. La clave Wi-Fi sigue pendiente del cambio solicitado anteriormente.

### Captura posterior con UTC

`um980-sky-epochs.nmea` y su archivo de métricas muestran 10.00 Hz de épocas UTC distintas y 10.00 Hz de llegada en el segmento continuo final. Sin duplicados; una discontinuidad inicial de UTC; máximo intervalo de llegada observado 102 ms. La calidad continuó en 0 con cero satélites usados. No se interpreta como una solución topográfica a 10 Hz. Después de esta prueba se cargó firmware 0.2.0 y se aplicó el cambio de clave solicitado; la mención anterior de firmware sin cargar corresponde únicamente a la primera sesión.

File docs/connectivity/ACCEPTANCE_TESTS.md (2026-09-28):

# Matriz de aceptación

Estado al 27-09-2026 por la noche. **Nada se da por pasado sin evidencia.** El equipo estaba
por USB en la Mac, bajo techo (sin fix), con firmware 0.7.11 de `los-residentes`; el cliente BLE
fue la Mac (CoreBluetooth, app de banco hecha para esto), que tiene la tabla GATT del equipo en
caché de un firmware viejo (ver KNOWN_LIMITATIONS.md). Cómo correr cada prueba:
[ACCEPTANCE_PROCEDURES.md](ACCEPTANCE_PROCEDURES.md) y `tools/ble_bench/` (Python) o `tools/ble_bench_mac/` (CoreBluetooth).

| # | Prueba | Se espera | Resultado de hoy | Estado |
| --- | --- | --- | --- | --- |
| 1 | Conexión en frío | Descubre, MTU 247, suscripciones, lista para órdenes | Conecta en ~1 s tras el escaneo; MTU 247; intervalo 30 ms; `GET /api/ble` en 40–93 ms. Con una dirección de prueba (sin caché): **5 características**, `a04c0005` con `write` + `write no response` | **Pasa** (Mac) |
| 2 | Ciclos de conexión/desconexión | Sin suscripciones duplicadas ni estado viejo | 4 conexiones seguidas de la Mac sin fallos; el equipo vuelve a anunciarse cada vez | Parcial (sin apps) |
| 3 | RTCM continuo | Cuadran bytes enviados, aceptados y escritos | Con respuesta: 55 410 B en 20 s (**≈2.8 kB/s**, tope del carril). **Sin respuesta: 24.3 kB/s** saturando (1 423 tramas válidas de 1 424, la última cortada al parar; 0 CRC) y **5 kB/s en ráfagas de una época por segundo sin una sola pérdida** (160/160) | **Pasa** hasta el UART del equipo (la fuente activa era NTRIP: el router las rechazó por fuente, a propósito, y nada llegó al UM980) |
| 4 | RTCM + telemetría | La telemetría no se atrasa | **Salud a 1 Hz exacto sin fix** (intervalos 0.96–1.05 s) durante RTCM saturado y en ráfagas; `telemetry_skipped` = 0. Sin fix no hay solución que medir | Salud: **pasa**. Solución: pendiente con fix |
| 5 | Orden durante RTCM | La orden no espera detrás del RTCM | Con respuesta: 75–93 ms → 90–153 ms. **Sin respuesta, 5 kB/s en ráfagas: mediana 67 ms, p90 126 ms, máx. 221 ms** (61 órdenes, una cada 250 ms). Sin respuesta y enlace saturado a propósito (24 kB/s): 270–510 ms | **Pasa** con tráfico real; saturar el enlace no es uso real |
| 6 | Reinicio del receptor | La app detecta, reconecta y no repite órdenes | — | Pendiente (apps) |
| 7 | Bluetooth del teléfono apagado/encendido | Reconexión con backoff, sin bucles | — | Pendiente (teléfono) |
| 8 | Fuera de alcance y vuelta | Degradado → reconexión; sin RTCM viejo | — | Pendiente (campo) |
| 9 | Segundo plano / primer plano | Según la plataforma, sin estado corrupto | — | Pendiente (teléfono) |
| 10 | Pantalla bloqueada | Igual que 9 | — | Pendiente (teléfono) |
| 11 | Corte de NTRIP con BLE arriba | Se vacía la cola, edad de correcciones sube, nada viejo al volver | — | Pendiente (apps + NTRIP real) |
| 12 | FLOTANTE → FIJO | Transiciones sin saltos ni placas equivocadas | — | Pendiente (fix) |
| 13 | Datos malformados o parciales | Se descartan y se cuentan, nada se cuelga | Pruebas unitarias del rearmado de respuestas (C++ y apps) y de la cola RTCM (C++): en verde | Pasa en pruebas; sin inyección por radio |
| 14 | Telemetría alta | Solución a 5 Hz sin huecos de secuencia | Sin fix, 0 soluciones: correcto | Pendiente (fix) |
| 15 | Sesión larga (30–60 min) | Heap estable, sin reconexiones, contadores cuadran | — | Pendiente |
| 16 | Colas saturadas | Descartes contados, las más viejas fuera, tramas enteras | `rtcm_queue_test` (2 000 vueltas del anillo, cuadre exacto) en verde | Pasa en pruebas; sin ráfaga real |

## Cifras del equipo en la prueba (firmware 0.7.11)

- Heap interno libre tras arrancar ≈ 97 KB; 0.7.10 daba ≈ 106 KB. Tras las pruebas de estrés (≈ 800 KB de RTCM por BLE sin respuesta), libre 92.9 KB y **mínimo 84.9 KB**: la biblioteca BLE reserva memoria en cada escritura; vigilarlo en la sesión larga.
- Pila libre mínima: `gnss_rx` 4.7 KB, `loopTask` 5.1 KB, `ntrip_rx` 3.9 KB, `rtcm_out` 2.9 KB.
- UART del UM980: 5 GGA/s aceptadas, 0 rechazadas, 0 errores (el cable RX está bien).
- `max_loop_gap_ms` ≤ 6 y `max_request_dispatch_ms` ≤ 2 durante las pruebas.
- Cambiar la fuente de correcciones a BLE con NTRIP activo: 409 «Detén NTRIP y espera al GPS
  antes de cambiar fuente.» Correcto; la prueba de RTCM no tocó la configuración.

## Coexistencia Wi-Fi / BLE (hipótesis descartada con esta medida)

Con dos redes Wi-Fi guardadas y ninguna al alcance, el equipo lanza un escaneo Wi-Fi completo
cada 30 s (`instrument.cpp:954-957`), y el ESP32 comparte la radio entre Wi-Fi y BLE. Medido:
220 órdenes `GET /api/ble` seguidas durante 70 s, cada 250 ms, mientras escaneaba: **mediana
40 ms, p95 98 ms, máximo 126 ms**, sin picos cada 30 s; las latencias caen en múltiplos del
intervalo de conexión (30 ms). El escaneo no explica tirones del Bluetooth. Falta medirlo con el
NTRIP del propio equipo por Wi-Fi activo al mismo tiempo que RTCM por BLE.

## Lo primero para mañana

1. Con un teléfono que nunca se haya conectado: ¿ve 5 características y `a04c0005` con
   `write no response`? Si sí, repetir 3 y 5 sin respuesta con las apps de `los-residentes`.
2. Con fix y NTRIP real (MSM4 y MSM7): 3, 4, 5, 11, 12, 14, y 15 de al menos 30 min.
3. Reconexiones: 6, 7, 8 con las dos apps.

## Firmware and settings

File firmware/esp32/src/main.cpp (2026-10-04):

#include "radio_module.h"
#include "sd_recorder.h"
#include "board_profile.h"
#include "local_display.h"
#include "power_manager.h"
#include "ntrip_input.h"
#include "correction_output.h"
#include "base_survey.h"
#include "gnss_control.h"
#include "memory_health.h"
#include <Arduino.h>
#include <ArduinoJson.h>
#include <WiFi.h>
#include <esp_http_server.h>
#include "telemetry_ws.h"
#include "gnss_visible.h"
#include <freertos/semphr.h>
#include "config_rules.h"
#include "instrument.h"
#include "gnss_receiver.h"
#include "correction_router.h"
#include "ble_transport.h"
#include "firmware_update.h"
#include "web_assets.h"

namespace {
httpd_handle_t server = nullptr;
SemaphoreHandle_t instrumentMutex;
char serialBuffer[config_rules::kMaxRequestBytes + 1];
size_t serialLength = 0;
bool serialOverflow = false;
uint32_t serialStartedAt = 0;

// El instrumento dejó de pedir clave de panel por decisión del propietario:
// es un receptor GNSS de campo y la barrera estorbaba más de lo que protegía.
// La contraseña del Wi-Fi propio es la única puerta que queda, y no sale por
// Bluetooth. Desde 0.7.13 la carga de firmware por OTA exige la firma del
// propietario: quien llegue a la red ya no puede instalar un firmware ajeno.
bool authenticated(const char*) { return true; }

int dispatch(const String& method, const String& path, JsonVariantConst body, JsonDocument& response) {
    if (xSemaphoreTake(instrumentMutex, pdMS_TO_TICKS(1000)) != pdTRUE) {
        response["error"] = "busy";
        response["message"] = "El instrumento está ocupado. Intenta de nuevo.";
        return 503;
    }
    const int code = instrument::request(method, path, body, response);
    xSemaphoreGive(instrumentMutex);
    return code;
}

void headers(httpd_req_t* request) {
    httpd_resp_set_hdr(request, "Cache-Control", "no-store");
    httpd_resp_set_hdr(request, "X-Content-Type-Options", "nosniff");
    httpd_resp_set_hdr(request, "Referrer-Policy", "no-referrer");
    httpd_resp_set_hdr(request, "Content-Security-Policy", "default-src 'self'; script-src 'self'; style-src 'self'; img-src 'self'; connect-src 'self'; frame-ancestors 'none'; base-uri 'none'; form-action 'self'");
}

esp_err_t reply(httpd_req_t* request, int code, JsonDocument& response) {
    const char* status = "500 Internal Server Error";
    switch (code) {
        case 200: status = "200 OK"; break;
        case 202: status = "202 Accepted"; break;
        case 400: status = "400 Bad Request"; break;
        case 401: status = "401 Unauthorized"; break;
        case 404: status = "404 Not Found"; break;
        case 409: status = "409 Conflict"; break;
        case 413: status = "413 Payload Too Large"; break;
        case 503: status = "503 Service Unavailable"; break;
    }
    String encoded;
    serializeJson(response, encoded);
    headers(request);
    httpd_resp_set_status(request, status);
    httpd_resp_set_type(request, "application/json; charset=utf-8");
    return httpd_resp_send(request, encoded.c_str(), encoded.length());
}

esp_err_t handleHttp(httpd_req_t* request) {
    JsonDocument response;
    // Comprobar antes de reservar memoria o leer el cuerpo de la solicitud.
    if (request->content_len > config_rules::kMaxRequestBytes) {
        response["error"] = "request_too_large";
        response["message"] = "La solicitud supera 1024 bytes.";
        reply(request, 413, response);
        return ESP_FAIL; // cerrar la conexión con datos sin consumir
    }
    if (request->method == HTTP_GET && request->content_len == 0) {
        for (const auto& asset : web_assets::all) {
            if (strcmp(request->uri, asset.path) != 0) continue;
            headers(request);
            httpd_resp_set_type(request, asset.mime);
            httpd_resp_set_hdr(request, "Content-Encoding", "gzip");
            return httpd_resp_send(request, reinterpret_cast<const char*>(asset.data), asset.size);
        }
    }
    char payload[config_rules::kMaxRequestBytes + 1];
    size_t received = 0;
    const uint32_t receiveStartedAt = millis();
    while (received < request->content_len) {
        if (config_rules::elapsed(millis(), receiveStartedAt, 5000)) return ESP_FAIL;
        const int count = httpd_req_recv(request, payload + received, request->content_len - received);
        if (count <= 0) return ESP_FAIL;
        received += count;
    }
    payload[received] = '\0';
    JsonDocument body;
    if (received && deserializeJson(body, payload, received, DeserializationOption::NestingLimit(4))) {
        response["error"] = "invalid_json";
        response["message"] = "La solicitud JSON está incompleta o no es válida.";
        return reply(request, 400, response);
    }
    const String method = request->method == HTTP_GET ? "GET" : (request->method == HTTP_PUT ? "PUT" : "POST");
    const int code = dispatch(method, request->uri, body.as<JsonVariantConst>(), response);
    return reply(request, code, response);
}

void serialReply(JsonDocument& response) {
    serializeJson(response, Serial);
    Serial.println();
}

void handleSerialLine() {
    JsonDocument input;
    JsonDocument output;
    const auto parsed = deserializeJson(input, serialBuffer, serialLength, DeserializationOption::NestingLimit(5));
    if (parsed || !input.is<JsonObject>()) {
        output["status"] = 400;
        output["body"]["error"] = "invalid_json";
        serialReply(output);
        return;
    }
    if (!input["id"].is<uint32_t>()) {
        output["status"] = 400;
        output["body"]["error"] = "invalid_id";
        serialReply(output);
        return;
    }
    output["id"] = input["id"];
    // Recuperación por acceso físico USB; esta ruta no existe por HTTP.
    if (input["method"] == "GET" && input["path"] == "/api/access") {
        output["status"] = 200;
        output["body"]["ap_ssid"] = instrument::apName();
        // Única credencial del equipo: la del Wi-Fi propio. El panel y la API no
        // piden clave y BLE va sin emparejamiento ni PIN (desde 0.6.2).
        output["body"]["ap_password"] = instrument::apPassword();
        output["body"]["ap_url"] = "http://192.168.4.1";
        // Donde vive en la red externa, que es justo lo que cuesta averiguar
        // cuando un hotspot reparte la direccion por DHCP.
        output["body"]["station_ssid"] = WiFi.SSID();
        output["body"]["station_url"] = WiFi.status() == WL_CONNECTED
            ? String("http://") + WiFi.localIP().toString() : String();
        output["body"]["mdns_url"] = "http://meridianv.local";
        serialReply(output);
        return;
    }
    JsonDocument body;
    output["status"] = dispatch(input["method"] | "", input["path"] | "", input["body"].as<JsonVariantConst>(), body);
    output["body"] = body;
    serialReply(output);
}

void pollSerial() {
    // Cuota por ciclo: una entrada continua no monopoliza el controlador.
    for (size_t count = 0; count < 256 && Serial.available(); ++count) {
        const char c = Serial.read();
        if (!serialLength && !serialOverflow) serialStartedAt = millis();
        if (c == '\n') {
            if (serialOverflow) Serial.println("{\"status\":413,\"body\":{\"error\":\"request_too_large\"}}");
            else if (serialLength) {
                serialBuffer[serialLength] = '\0';
                handleSerialLine();
            }
            serialLength = 0;
            serialOverflow = false;
        } else if (c != '\r') {
            if (serialLength < config_rules::kMaxRequestBytes && !serialOverflow) serialBuffer[serialLength++] = c;
            else serialOverflow = true;
        }
    }
    if ((serialLength || serialOverflow) && config_rules::elapsed(millis(), serialStartedAt, 5000)) {
        serialLength = 0;
        serialOverflow = false;
        Serial.println("{\"status\":408,\"body\":{\"error\":\"request_timeout\"}}");
    }
}
}

void setup() {
    // Alimentación de periféricos y señales del Soft Power Switch Mk2.
    power_manager::begin();
    local_display::begin();
    Serial.setRxBufferSize(2048);
    Serial.begin(115200);
    Serial.setTxTimeoutMs(50);
    instrumentMutex = xSemaphoreCreateMutex();
    if (!instrumentMutex) {
        Serial.println("Error: no se pudo crear el bloqueo del instrumento.");
        return;
    }
    memory_health::begin();
    gnss_control::begin();
    instrument::begin();
    sd_recorder::begin();
    gnss_receiver::begin();
    // Antes que NTRIP: si el usuario eligió BLE, la autoconexión del perfil no
    // debe quitárselo al arrancar.
    correction_router::begin();
    ntrip_input::begin();
    correction_output::begin();
    // El radio LoRa externo: servidor en la red propia, en su propia tarea.
    radio_module::begin();
    base_survey::begin();
    gnss_visible::begin();
    ble_transport::begin(dispatch, authenticated);
    httpd_config_t configuration = HTTPD_DEFAULT_CONFIG();
    configuration.uri_match_fn = httpd_uri_match_wildcard;
    configuration.stack_size = 8192;
    // Siete y no cuatro: el WebSocket de telemetría ocupa uno **de forma
    // permanente**, y con cuatro en total una descarga de grabación y el panel
    // abierto bastaban para que el purgado LRU echara al teléfono que estaba
    // midiendo. Cada socket cuesta memoria, pero echar al que mide no es un
    // compromiso aceptable.
    configuration.max_open_sockets = 7;
    configuration.lru_purge_enable = true;
    configuration.recv_wait_timeout = 2;
    configuration.send_wait_timeout = 2;
    if (httpd_start(&server, &configuration) == ESP_OK) {
        // **Antes del comodín, y no es un detalle de estilo.** El servidor
        // compara las rutas en el orden en que se registran, y "/*" engancha
        // todo: registrada después, la ruta del WebSocket no se alcanzaría
        // nunca y el apretón de manos se contestaría con un 404 en JSON.
        telemetry_ws::begin(server);
        for (const httpd_method_t method : {HTTP_GET, HTTP_PUT, HTTP_POST}) {
            httpd_uri_t route = {};
            route.uri = "/*";
            route.method = method;
            route.handler = handleHttp;
            if (httpd_register_uri_handler(server, &route) != ESP_OK) Serial.println("Error al registrar ruta HTTP.");
        }
    } else Serial.println("Error al iniciar el servidor web. Consola USB disponible.");
    local_display::servicesReady();
    Serial.printf("TresVizo RTK %s. Consola JSON USB disponible.\n", instrument::kVersion);
}

void loop() {
    if (instrumentMutex) {
        pollSerial();
        ble_transport::tick();
        telemetry_ws::tick();
        if (xSemaphoreTake(instrumentMutex, pdMS_TO_TICKS(10)) == pdTRUE) {
            power_manager::tick();
            instrument::tick();
            // Bajo el mutex: el promedio puede terminar aplicando modo base, y
            // eso toca el receptor igual que cualquier otra operación.
            base_survey::tick();
            ntrip_input::tick();
            firmware_update::tick(server != nullptr);
            xSemaphoreGive(instrumentMutex);
        }
    }
    delay(2);
}

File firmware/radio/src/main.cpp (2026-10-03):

// Módulo de radio LoRa del MeridianV (docs/radio/RADIO_MODULE.md).
//
// Tres partes en un bucle:
//   - Bluetooth: la app le da de alta (red Wi-Fi y contraseña de su MeridianV) y lo
//     configura; se anuncia como «TresVizo Radio XXXX».
//   - Wi-Fi: se une a la red propia del MeridianV y abre TCP a su puerta de enlace
//     (192.168.4.1:2102). Por ahí recibe su papel, el RTCM de la base y la
//     configuración, y manda su estado cada segundo.
//   - LoRa (SX1262 de la E22-900M30S): en base transmite el RTCM; en rover lo recibe,
//     lo rearma con el parser RTCM3 (CRC-24Q) y entrega solo tramas válidas.
#include <Arduino.h>
#include <ArduinoJson.h>
#include <BLE2902.h>
#include <BLEDevice.h>
#include <BLEServer.h>
#include <RadioLib.h>
#include <SPI.h>
#include <WiFi.h>
#include <freertos/semphr.h>
#include <esp_app_format.h>
#include <esp_image_format.h>
#include "radio_air.h"
#include "radio_config.h"
#include "signed_firmware.h"
#include "radio_link.h"
#include "rtcm3.h"

// Identidad de la imagen en la sección que ESP-IDF deja tras el descriptor de
// aplicación (byte 288: versión; byte 320: placa), igual que el MeridianV. Así el
// cargador por USB (tools/flasher/) sabe que un .bin es del módulo de radio.
static_assert(sizeof(esp_image_header_t) + sizeof(esp_image_segment_header_t) + sizeof(esp_app_desc_t) ==
              signed_firmware::kIdentityImageOffset, "la identidad va justo detras de esp_app_desc_t");
static_assert(signed_firmware::fitsIdentity(RADIO_VERSION), "la versión no cabe en la identidad");
const signed_firmware::BoardFirmwareIdentity kImageIdentity __attribute__((section(".rodata_custom_desc"), used)) =
    {signed_firmware::makeIdentity(RADIO_VERSION), RADIO_HARDWARE_ID};

namespace {
// --- Tiempos y límites (con su motivo) ---------------------------------------------
// El MeridianV corta la conexión si pasan 5 s sin estado; uno por segundo deja margen.
constexpr uint32_t kStatusPeriodMs = 1000;
// Reintento de Wi-Fi y TCP: rápido para que al encender el MeridianV se enganche
// enseguida, sin saturar al equipo si todavía no ha levantado su red.
constexpr uint32_t kReconnectMs = 2000;
// RTCM de la base más viejo que esto ya no le sirve al rover: se tira antes de
// transmitirlo (el receptor admite correcciones de pocos segundos de edad).
constexpr uint32_t kMaxFrameAgeMs = 2000;
constexpr size_t kPendingFrames = 16;
// Corriente máxima del SX1262 para la etapa que excita al amplificador de la E22.
constexpr float kCurrentLimitMilliamps = 140.0f;
constexpr uint16_t kBleMtu = 247;

// UUID del servicio de configuración del radio (docs/radio/RADIO_MODULE.md).
const char* kServiceUuid = "c04c0001-8f24-4adb-a350-77ef6339c320";
const char* kConfigUuid = "c04c0002-8f24-4adb-a350-77ef6339c320";
const char* kStatusUuid = "c04c0003-8f24-4adb-a350-77ef6339c320";

enum class Role : uint8_t { idle, base, rover };
const char* roleName(Role role) { return role == Role::base ? "base" : role == Role::rover ? "rover" : "idle"; }

radio_config::Settings settings;
Role role = Role::idle;

// --- LoRa -------------------------------------------------------------------------
SPIClass loraSpi(FSPI);
SX1262 lora = new Module(RADIO_PIN_NSS, RADIO_PIN_DIO1, RADIO_PIN_NRST, RADIO_PIN_BUSY, loraSpi);
bool loraReady = false;
int loraError = 0;
volatile bool packetArrived = false;
radio_air::Packetizer packetizer;
radio_air::Receiver receiver;
gnss::Rtcm3Parser roverParser;
uint32_t packetsSent = 0;
float lastRssiDbm = NAN, lastSnrDb = NAN;

void IRAM_ATTR onPacketReceived() { packetArrived = true; }

// --- Enlace con el MeridianV -------------------------------------------------------
WiFiClient meridianLink;
radio_link::Decoder decoder;
uint32_t lastWifiAttempt = 0, lastLinkAttempt = 0, lastStatus = 0;
bool helloSent = false;

struct PendingFrame { uint32_t arrivedMs; uint16_t length; uint8_t bytes[1029]; };
PendingFrame pending[kPendingFrames];
size_t pendingHead = 0, pendingCount = 0;
uint32_t framesExpired = 0, framesOverflow = 0;

// --- Bluetooth ---------------------------------------------------------------------
BLECharacteristic* statusCharacteristic = nullptr;
SemaphoreHandle_t bleLock = nullptr;
String bleRequest;          // lo último que escribió la app, para aplicarlo en el bucle
bool bleRequestPending = false;
String lastError;
bool bleClient = false;

void setLed(bool on) {
    if (RADIO_PIN_LED >= 0) digitalWrite(RADIO_PIN_LED, on ? HIGH : LOW);
}

// Frecuencia, potencia y red según los ajustes; el papel decide si se escucha.
void configureLora() {
    if (!loraReady) return;
    lora.standby();
    lora.setFrequency(radio_air::channelHz(settings.channel) / 1e6f);
    lora.setOutputPower(radio_air::chipDbmFor(settings.powerDbm));
    packetizer.network = settings.network;
    receiver.network = settings.network;
    receiver.reset();
    roverParser.reset();
    if (role == Role::rover) lora.startReceive();
}

void startLora() {
    loraSpi.begin(RADIO_PIN_SCK, RADIO_PIN_MISO, RADIO_PIN_MOSI, RADIO_PIN_NSS);
    loraError = lora.begin(radio_air::channelHz(settings.channel) / 1e6f, radio_air::kBandwidthHz / 1e3f,
                           radio_air::kSpreadingFactor, radio_air::kCodingRateDenominator,
                           RADIOLIB_SX126X_SYNC_WORD_PRIVATE, radio_air::chipDbmFor(settings.powerDbm),
                           radio_air::kPreambleSymbols, RADIO_TCXO_VOLTS);
    if (loraError != RADIOLIB_ERR_NONE) return;
    // La E22 no usa DIO2 para la antena: dos pines del ESP32 conmutan emisión y recepción.
    lora.setRfSwitchPins(RADIO_PIN_RXEN, RADIO_PIN_TXEN);
    lora.setCurrentLimit(kCurrentLimitMilliamps);
    lora.setCRC(2);
    lora.setPacketReceivedAction(onPacketReceived);
    loraReady = true;
    configureLora();
}

bool sendToMeridian(radio_link::Type type, const uint8_t* payload, size_t length) {
    if (!meridianLink.connected()) return false;
    uint8_t wire[radio_link::kHeaderBytes + radio_link::kMaxPayloadBytes];
    const size_t n = radio_link::encode(type, payload, length, wire, sizeof(wire));
    return n && meridianLink.write(wire, n) == n;
}

bool sendJson(radio_link::Type type, JsonDocument& doc) {
    char text[512];
    const size_t n = serializeJson(doc, text, sizeof(text));
    return n && n < sizeof(text) && sendToMeridian(type, reinterpret_cast<const uint8_t*>(text), n);
}

String radioId() {
    uint8_t mac[6];
    WiFi.macAddress(mac);
    char text[18];
    snprintf(text, sizeof(text), "%02X%02X%02X%02X%02X%02X", mac[0], mac[1], mac[2], mac[3], mac[4], mac[5]);
    return text;
}

const char* airState() {
    if (!loraReady) return "radio_error";
    if (role == Role::base) return "transmitting";
    if (role == Role::rover) return receiver.accepted ? "receiving" : "listening";
    return "idle";
}
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

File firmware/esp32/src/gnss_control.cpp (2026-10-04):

#include "firmware_update.h"
#include "sd_recorder.h"
#include "receiver_baseline.h"
#include "gnss_control.h"
#include "gnss_receiver.h"
#include "correction_router.h"
#include <atomic>
#include "command_handoff.h"
namespace gnss_control {
namespace {
constexpr unsigned kMaxCommands = 20;
// Presupuesto total del trabajo. El limite por comando solo corre una vez
// enviado; sin este, un puerto que nunca acepte escritura dejaba el trabajo
// en "running" para siempre y bloqueaba NTRIP, grabacion y cambio de clave.
constexpr uint32_t kJobBudgetMs = 20000;
constexpr uint32_t kCommandTimeoutMs = 4000;

SemaphoreHandle_t mutex;
String commands[kMaxCommands], mode, version, action, failure;
String expectedMode;
String maskReadback;
unsigned count=0, index=0;
bool sent=false, ack=false, readback=false, overflowed=false;
uint32_t started=0, launched=0, job=0;
std::atomic<uint32_t> modeAt{0};
std::atomic<bool> running{false}, rover{false}, base{false}, wantsBase{false}, draining{false};
protocol::CommandHandoff handoff;
uint32_t supersededJobs=0, supersededJob=0;
// Referencia de la altura que entrega el receptor. **Sin confirmar al arrancar**
// (reauditoría de 0.7.13, R02): antes arrancaba en «MSL del receptor» y solo
// cambiaba con el OK de un `CONFIG UNDULATION` enviado; un receptor que ya tenía
// guardado 0.0000 no recibía la orden y se publicaba como MSL una altura
// elipsoidal. Ahora la fija también la lectura de CONFIG de la reconciliación.
enum class Undulation : uint8_t { unknown, ellipsoid, receiverMsl };
std::atomic<uint8_t> undulation{static_cast<uint8_t>(Undulation::unknown)};
bool bootQueried=false;
// Tiempo que se espera a que CONFIG termine de escupir sus lineas.
constexpr uint32_t kConfigSettleMs = 700;
const char* phase="idle";
char line[1024]; size_t length=0;

// Configuracion avanzada conocida. Solo se actualiza cuando el receptor
// confirma el comando; no se muestra como estado leido si no se leyo.
struct Profile {
    double elevation_deg = 5.0;      // valor por defecto del receptor segun manual N4
    bool elevation_known = false;
    bool gps = true, bds = true, glo = true, gal = true, qzss = true;
    bool constellations_known = false;
    String outputs;                  // resumen de salidas NMEA aplicadas
    String rtcm;                     // resumen del perfil RTCM aplicado
    int dgps_timeout_s = -1;         // -1 = desconocido
    // Lo que el receptor tiene ahora esta guardado en su NVM: el ultimo trabajo
    // que escribio configuracion termino con un SAVECONFIG contestado con OK.
    // Se pone a falso al lanzar cualquier trabajo que escriba y con cada OK de
    // una escritura; solo el OK del SAVECONFIG lo pone a verdadero. Hasta 0.7.12
    // lo ponia `commitProfile` por el nombre de la accion, y `applyBase` —que no
    // enviaba SAVECONFIG— salia con `saved:true`.
    bool saved = false;
    // Tasa de GGA de la ultima `telemetry` u `outputs` confirmada. La usa
    // `rover` para reponer las salidas que su UNLOG quita. 0 = ninguna en esta
    // sesion del ESP32: `addPositionOutputs` usa entonces el tope del producto
    // (kDefaultGgaRateHz).
    unsigned gga_rate_hz = 0;
} profileState;

// Reconciliación: qué se leyó del receptor, qué difería y qué se corrigió.
//
// Se guarda el informe completo, no solo el resultado, porque «se arregló» sin
// decir qué estaba mal no permite distinguir un equipo recién montado de uno que
// alguien reconfiguró por su cuenta. Lo primero es normal; lo segundo hay que
// saberlo.
struct Reconciliation {
    bool ran = false;
    bool reading = false;            // fase de lectura en curso
    // La del arranque no toca las preferencias del usuario. Ver
    // `applyReconciliation`: forzar la mascara al arrancar le borraria al
    // operador la que acaba de poner, y sin decirselo.
    bool atBoot = false;
    uint32_t readStartedAt = 0;
    String readback;                 // líneas $CONFIG,... tal como llegaron
    String differences;              // clave: leído -> esperado, separadas por " | "
    unsigned checked = 0, fixed = 0;
    String summary;
} reconciliation;

/// El valor que el receptor tiene para una clave, según lo leído. Vacío si esa
/// clave no apareció, que para un receptor de fábrica es lo normal y **no es lo
/// mismo que tener un valor distinto**: una clave ausente puede significar que
/// el receptor usa su valor por defecto, y ese defecto puede ser el correcto o no.
String readValueFor(const String& key) {
    const String marca = "$CONFIG," + key + ",";
    int desde = 0;
    while(true) {
        const int i = reconciliation.readback.indexOf(marca, desde);
        if(i < 0) return "";
        const int fin = reconciliation.readback.indexOf('\n', i);
        String linea = fin < 0 ? reconciliation.readback.substring(i)
                               : reconciliation.readback.substring(i, fin);
        linea.trim();
        return linea.substring(marca.length());
    }
}

void finish(const char* state, const char* error="") { phase=state;failure=error;running=false; }
bool add(const String& c) { if(count>=kMaxCommands){overflowed=true;return false;} commands[count++]=c; return true; }
// Las consultas: leen y no cambian nada. Todo lo demas escribe configuracion.
bool isQuery(const String& c) { return c=="MODE" || c=="VERSIONA" || c=="MASK" || c=="CONFIG"; }
bool needsReply() { return isQuery(commands[index]); }

// Tasas admitidas por el UM980 segun manual N4: 1/2/5/10/20 Hz -> 1/0.5/0.2/0.1/0.05.
// No se usa 1.0/hz con un decimal porque 20 Hz necesita dos.
const char* rateFor(unsigned hz) {
    switch (hz) {
        case 1: return "1";
        case 2: return "0.5";
        case 5: return "0.2";
        case 10: return "0.1";
        case 20: return "0.05";
        default: return nullptr;
    }
}
// **Nada por encima de 5 Hz** hacia el ESP32, aunque el UM980 admita 10 y 20.
// Es el mismo tope que la telemetria hacia el telefono
// (`protocol::kMaxSolutionRateHz`): a 10 Hz el Bluetooth se quedaba en unos 8,
// y el propietario fijo 5 Hz para todo el camino (27-09-2026).
constexpr unsigned kMaxOutputRateHz = 5;
constexpr const char* kRateCapMessage = "La frecuencia maxima es 5 Hz: el enlace con el telefono no sostiene mas.";
bool validRate(unsigned hz) { return rateFor(hz) != nullptr && hz <= kMaxOutputRateHz; }
// Tasa de GGA cuando esta sesion del ESP32 aun no ha aplicado ninguna: el tope
// del producto, que es tambien la que ponen las apps.
constexpr unsigned kDefaultGgaRateHz = kMaxOutputRateHz;
// Tasa de GGA pedida por el trabajo en curso; se apunta al confirmarse.
unsigned pendingGgaHz = 0;
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

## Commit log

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2026-09-19 Initialize ESP32 RTK firmware scaffold
    This commit adds the initial ESP32-S3 instrument firmware skeleton, including PlatformIO configuration, partitioning, config validation helpers, a basic WebServer/USB JSON API, and embedded web asset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
    [partitions.csv]
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2026-09-20 Add 0.3.0 operations sections and base planning
    Release 0.3.0 adds three new panel sections (Base/rover, Recording/PPK, Corrections) with UI controls and plan preparation endpoints. Implements base station validation with ellipsoidal height ARP calculation and supports both known coordinates and autonomous averaging modes. Adds comprehensive documentation for NTRIP architecture, UM980 command investigation, recording workflow, and coordinate reference systems. Includes 27-check smoke test for operations API without persisting changes or commanding the receiver. All recording, UART, microSD, and NTRIP transport remain pending integration. Mechanical CAD updated with nut retention geometric ve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
    [AntennaSupport.step, Base.step, ESPPlate.step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]
2026-09-20 Add redesign concept diagram and renderer
    Add mechanical/research redesign concept assets: an SVG and PNG (redesign-concept.svg/.png) plus a Python renderer (render_redesign_concept.py). The script uses Matplotlib to draw an unscaled functional schematic and exports both PNG and SVG for review of the proposed A4 architecture and assembly notes.
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2026-09-20 Add TresVizo symbol branding to A4 case
    Adds logo engraving (symbol 3 + hexagon from tresvizo.com) to MainShell with 0.6 mm radial depth. Includes vector symbol extraction (trace_logo.py), branding application module (case_branding.py), and macOS launch bundle (Abrir A4.app) for FreeCAD 1.0.2. GUI validation completed with FreeCAD 1.0.2 (Qt 5.15.15); documents FreeCAD 1.1.3/Qt 6.8.3 stability issues on this Mac for reference.
    [MainShell-ORIENTED-REVIEW.stl, MainShell.step, TresVizo-case-A4-EXPLODED.FCStd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]
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2026-09-20 Add power-board docs and mechanical integration
    Agrega documentación y artefactos para la Power Board: USB_NATIVE_REVIEW.md, VALIDATION.md, datasheets (ESP32-S3-Tiny, Tiny-Adapter) y tres imágenes. Añade POWER_BOARD_INTEGRATION.md bajo mechanical,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
    [TresVizo-A5.FCStd]
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2026-09-20 Arreglo de archivos basura
    [01-cuerpo.stl, 02-chasis-base.stl, 03-cuna-bateria-imu.stl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]
2026-09-21 Mejora de grabador SD y parser RTCM3
    Se actualiza el grabador SD para recibir bloques (feed(const uint8_t*, size_t)) y así evitar llamadas al kernel por cada byte; se añade control de inFlight, conteo de bytes descartados y envío en bloque al stream buffer. En rtcm3 se añade resync() para saltar rápidamente al siguiente 0xD3 y evitar memmoves cuadráticos, se incorpora contador overflow y se usa resync en errores/CRC rechazados. Además se corrige uso indefinido de isxdigit con chars >0x7F y se renombra variable de ruta en la lectura de sesiones.
    Archivos modificados: firmware/esp32/include/sd_recorder.h, firmware/esp32/src/sd_recorder.cpp, firmware/esp32/lib/gnss/src/rtcm3.h.
    [gnss_control.cpp, gnss_receiver.cpp, sd_recorder.cpp]
2026-09-21 Fix NTRIP header parsing and validation
    This patch hardens the NTRIP client by guarding base64 credential encoding, switching the response-header scan to a fixed-size buffer to avoid quadratic String growth, and checking HTTP headers without swallowing RTCM payload bytes. It also fixes unsigned-char safety in host and mount validation to avoid undefined behavior.
2026-09-21 Separate AP credentials and expose GNSS health
    This release separates the Wi-Fi AP password from the API access key so joining the instrument's access point no longer grants control over the device. A random AP password is generated and persisted, and the API exposes the Wi-Fi credentials independently from the API key.
    It also expands the status payload with GNSS health counters and HDOP, and adds a profile endpoint for the receiver configuration. These additions improve diagnostics and make it clearer whether RTCM and native GNSS frames are actually reaching the UM980.
    [instrument.cpp]
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2026-09-22 Nuevo case y arreglo NTRIP
    [01-base-rosca.step, 01-base-rosca.stl, 01-cuerpo.step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]
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2026-09-25 Reconciliar la configuracion del UM980 contra la que debe tener
    Montar un receptor nuevo era acordarse de memoria de quince comandos y
    escribirlos a mano. La primera vez que faltara uno, el equipo funcionaria
    "casi bien", que es la peor clase de averia.
    Ahora hay una tabla de lo que un UM980 de MeridianV DEBE tener
    (receiver_baseline.h) y una accion "reconcile" en /api/gnss/control que lee la
    configuracion real con CONFIG y MASK, la compara, y encola solo los comandos
    que difieran. El informe queda en /api/gnss/profile: cuantos se comprobaron,
    cuantos se corrigieron y cual era el valor leido frente al esperado.
    Probado contra un equipo real: detecto un unico ajuste mal y lo corrigio.
    UN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
    [gnss_control.cpp]
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2026-09-26 Domo con antena ArduSimple sobre V2.1 y documentación al día
    Opción de diseño (no V3) en mechanical/option-oem-dome: tapa-plato a 35 grados
    con la antena ArduSimple OEM Survey Tripleband y domo elíptico con junta 130x2.
    Ahora usa el cuello largo y el cierre horario de V2.1, el refuerzo de 7.5 mm del
    seguro, entrada suave de la falda para la junta, y comprueba contra el STEP
    real el recorrido del coaxial (radio de curvatura 13 mm) y la holgura de la
    caja del LNA.
    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
    [07-oem-antenna-lid.step, 07-oem-antenna-lid.stl, 08-oem-dome.step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]
2026-09-27 Add tracked-satellites telemetry and stack fix
    This release adds tracked-satellite reporting from GSV to status, BLE health, and WebSocket telemetry, and updates the field panel to show used/tracked counts. It also raises the UART task stack to avoid GNSS stack corruption, documents the 0.7.1/0.7.2 findings, and bumps the firmware version to 0.7.2.
    [gnss_receiver.cpp, instrument.cpp]
2026-09-27 Align GNSS telemetry and source persistence
    This release updates the BLE/WebSocket health payloads to report tracked satellites and the worst horizontal axis, while preserving used satellites in byte 10. It also stores the user-selected correction source in NVS so BLE survives reboot, exposes north/east sigma values in status, and updates the panel, docs, and tests to match the 0.7.5 telemetry semantics.
    [instrument.cpp, main.cpp]
2026-09-27 Cap GNSS telemetry to 5 Hz
    This change enforces a 5 Hz ceiling for GNSS output and solution telemetry across the ESP32 stack. It adds shared rate limits for BLE and WebSocket solution updates, validates GNSS output requests with a clearer 5 Hz cap message, and updates the web UI and version metadata to match the new operating point. The goal is to avoid Bluetooth saturation while preserving stable telemetry delivery.
    [gnss_control.cpp]
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2026-09-28 Matriz de aceptación con el RTCM sin respuesta medido en el equipo: 24 kB/s sin pérdidas, 5 kB/s en ráfagas con órdenes a 67 ms de mediana, salud a 1 Hz sin fix; y la dirección nueva como arreglo pos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
2026-09-28 Versiones del protocolo: el aviso de las apps de main con 0.7.11 es correcto y conservador, y por qué la versión subió a 3 sin cambiar ningún formato
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2026-09-28 WebSocket: la salud sale a 1 Hz por su cuenta, como por Bluetooth, y ya no se queda detrás de la puerta de la solución
    Iba después de los return de la solución (sin GGA, época repetida o tope de
    5 Hz), así que sin fix o con el receptor mudo el WebSocket dejaba de mandar
    la edad de las correcciones y el latido. Ahora se arma primero, con el reloj
    leído tras la instantánea y la caducidad de 2 s de la calidad y la precisión,
    y la solución sigue con su puerta de siempre (500 ms, ya con nombre).
2026-09-28 WebSocket: envía la tarea httpd con httpd_queue_work y la lista de clientes es solo suya; el bucle principal ya no se para con un cliente lento
    broadcast leía y encogía la lista desde loopTask mientras el manejador la
    cambiaba desde httpd, sin cerrojo (un forget doble podía dejar clientCount en
    SIZE_MAX y salirse del arreglo), y enviaba en el acto por el socket: un
    cliente que dejaba de confirmar paraba BLE y consola hasta 2 s. Ahora tick
    solo arma la solución y la salud de la pasada en una tanda reservada con
    malloc y la encola; un atómico de «en vuelo» impide apilar otra (se reintenta
    con lo más nuevo) y si no se puede encolar se libera en el acto. sendWork
    comprueba que el descri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
2026-09-28 0.7.13: arreglos de la auditoría del 28-09 (base, salud, WebSocket, contraseñas por BLE y OTA firmada), notas de versión y textos que quedaban viejos
    El panel pide firmware-signed.bin y ya no dice que la imagen va sin firma; el BOM ya no dice
    que la PSRAM esté desactivada (ESP32-S3FH4R2, PSRAM de 2 MB activada y comprobada); la
    arquitectura dice que el envío del WebSocket lo hace la tarea httpd.
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2026-09-28 Meridian3: generador de la carcasa a Ø54 con los arreglos de V2.1, pila de alturas desde los componentes y comprobaciones de encaje, USB-C y bayoneta
    Carpeta nueva mechanical/meridian3, derivada de V2.1 sin tocar v2 ni v2.1.
    Cinco piezas: base, tubo, tapa de antena, trineo y tapa del panel con la
    abertura del USB-C y la repisa de la Tiny-Adapter. La altura sale de
    stack.py; con latiguillo coaxial queda en 150.6 mm (43.7 más que V2).
    capacity_check.py comprueba paso por el collar, componentes contra piezas,
    conectores del carrier, coaxial, sobremolde USB-C, montaje de la tapa del
    panel, centrado del anillo, sentido y recorrido de la bayoneta, seguros,
    paredes entre tornillos y rigidez frent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
    [01-threaded-base.step, 01-threaded-base.stl, 02-logo-tube.step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]
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2026-10-03 Fuera el Meridian3: el propietario lo canceló; el firmware, la carcasa, el cargador y los documentos vuelven a ser solo del MeridianV
    Se quitan el perfil de compilación meridian3, lib/protocol/src/product.h y su prueba, los
    campos product, product_name y hardware_features de /api/status, el nombre del panel tomado
    del equipo, el entorno de firmware_package.py, mechanical/meridian3, su BOM y
    docs/meridian3.md. Se quedan los arreglos de la reauditoría (R01 y R02) y el cargador por
    USB, que ahora solo ofrece el MeridianV y está preparado para añadir otros equipos con su
    hardware_id. 0.7.14 no llegó a ningún equipo con el Meridian3.
    [01-threaded-base.step, 01-threaded-base.stl, 02-logo-tube.step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]
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2026-10-03 Carcasa V2.2: Ø79 y 20 mm más de cuerpo, panel frontal con la OLED de 0.96 in y el botón de 12 mm, respaldo de amarre en vez del trineo e IMU incrustado en la tapa con el chip en el eje
    El tubo lleva en su cara trasera un respaldo ranurado, unido a la pared por dos costillas y
    con un canal detrás, al que se amarra todo con bridas; el frente queda libre para la
    pantalla, el botón, el USB-C y sus cables. La plataforma del IMU entra por abajo en el cuello
    de la tapa y la retienen tres uñas con precarga, en una sola orientación.
    V2.1 ponía en el eje la recta de los agujeros del BMI088 y dejaba el chip 5.65 mm fuera.
    V2.2 coloca la placa por sus agujeros (pilotos en x = -9.0 y +9.5, y =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
    [01-threaded-base.step, 01-threaded-base.stl, 02-logo-tube.step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]
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2026-10-04 Refuerza OLED y transporte Wi-Fi/BLE en firmware 0.8.2
    Conserva fragmentos BLE ante rechazo, descarta líneas vencidas hasta LF y mantiene
    el id de errores 413. Acota respuestas atascadas, verifica notificaciones y
    completa la respuesta antes de desactivar BLE. Corrige frescura de WebSocket y
    continuidad de OTA frente a tareas del arranque. Conserva el contrato de las apps.
    Arranque OLED con plazo único de 10 s, transferencia completa comprobada y
    reinicio coordinado. La validación visual sigue pendiente: OLED no detectada.
    Validación: compilación, firma y carga USB; 32 suites C++ con UBSan, 86 pruebas
    del banco BLE y 35 del contrato; 644 comprobaciones estáticas y 320 en equipo.
    Dos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
    [gnss_control.cpp, instrument.cpp]
2026-10-04 Carcasa V2.2: tuerca hexagonal 5/8"-11 de latón para el jalón y conector de carga JST-XH en el panel
    La rosca del jalón deja el inserto de McMaster, que solo entraba pausando la impresión: ahora es una tuerca estándar de latón metida por dentro de la base, en un alojamiento hexagonal, apoyada en un anillo de 2 mm y detenida por dos M3x8 con arandela ancha. La altura no cambia (ARP a 129.9 mm). En el panel, un JST-XH de 2 pines a ras en lugar del USB-C. 15 tornillos. Modelo regenerado: piezas cerradas, sin interferencias y capacity_check sin fallos.
    [01-threaded-base.step, 01-threaded-base.stl, 02-logo-tube.step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]
2026-10-04 Placa principal exploratoria en KiCad: UM980, ESP32-S3, BQ25798 1S/2S, BMI088 y microSD, ruteada y lista para cotizar en JLCPCB
    hardware/main-board: 50 × 76 mm, 4 capas (JLC04161H-7628), para el interior de la carcasa V2.2
    sin cambiar su exterior. UM980 soldado con su antena (línea de 50 Ω y alimentación limitada),
    ESP32-S3-MINI-1 con los GPIO del firmware 0.8.x, BMI088 sobre el eje del jalón, microSD, carga
    USB-C a 1 A con BQ25798 (usar y cargar a la vez, modo ship como apagado, 1S o 2S cambiando
    resistencias), TPS62903 a 3.3 V y conectores JST para panel, OLED, batería y COM1.
    Todo sale de scripts: circuit.py (esquemático), layout.py (colocación, prerruteos, zonas),
    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
    [gnss.kicad_sch, gpio_map.csv, io.kicad_sch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]
2026-10-05 Placa principal: el modelo 3D del u.FL (J301) estaba girado 180° y se veía corrido 1.5 mm de sus pads
    El modelo de EasyEDA traía rotate 180; con 0 queda centrado entre los pads de GND y con la
    pata de señal sobre su pad, como en el patrón de Hirose U.FL-R-SMT-1. Los pads, los gerbers
    y el CPL no cambian. Se revisaron los demás modelos de LCSC (conectores JST, microSD, ESP32
    con su antena, bobinas, CI): coinciden con sus pads. README: el ERC y el DRC necesitan las
    bibliotecas estándar de KiCad en las tablas globales.
    [tresvizo-main.kicad_pcb]
2026-10-05 Placa principal v0.2: UM980 y BMI088 por cable, conectores hacia cantos o zonas libres, placa panel-usb y un solo panel para JLCPCB
    - 46 x 64 mm, 4 capas. El UM980 queda en su carrier BDLX por J301 (GH 8) con 5 V conmutable
    (TPS63070, GPIO45) y el BMI088 vuelve a la tapa por I2C en un segundo bus (J405, GH 7).
    - Todos los conectores de cable son GH o SH de 8 pines o menos (kit del propietario), salvo la
    batería (PH 2). Cada uno apunta a un canto o a una zona libre con sitio para la clavija
    enchufada y su cable: áreas de regla clavija_* en el DRC y kicad/plugs.json para el CAD.
    - La placa sube 2.5 mm en el tubo (z 23.5-87.5) para que las clavijas del canto inferior tengan
    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
    [gnss.kicad_sch, io.kicad_sch, mcu.kicad_sch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]
2026-10-05 Placa principal v0.2: J404 montado con puente JP101, USB-C de la panel-usb más volado, correcciones de la auditoría y logotipo
    - J404 (NTC) se monta de fábrica y la NTC queda opcional. Sin ella, R106 (10 kΩ) va a GND por
    JP101, un puente de soldadura cerrado de fábrica, y el cargador ve 25 °C. Para usar la NTC se
    corta JP101 («cortar JP101» en la serigrafía, sobre el puente). R115 baja junto a R113 para
    dejar sitio a esa línea.
    - panel-usb: el canto de la lengüeta retrocede 0.8 mm (v = 0.89) y el USB-C sobresale 1.29 mm; su
    cara sigue a ras de la tapa. El cobre queda a 0.41 mm del canto. En el panel la fresa frente al
    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
    [io.kicad_sch, power.kicad_sch, tresvizo-main-bom-jlcpcb.csv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]
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2026-10-06 Placa principal v0.2: ESP32-S3-WROOM-1-N16R2 en lugar del MINI-1 y sin LEDs del panel
    - U201 = ESP32-S3-WROOM-1-N16R2 (C2913205): 16 MB de flash y 2 MB de PSRAM quad. Huella y
    modelos de LCSC; el .step se corrió 3.65 mm para que coincida con su .wrl y la huella.
    - GPIO nuevos para rutear el módulo en la misma placa: microSD CLK 6, CMD 7, D0 5, D1 4, D2 16,
    D3 15 y detección 17; UART del GNSS TX 8 / RX 9; PPS 10, EVENT 11, RESET 12; I2C 13/14;
    IMU 41/42 con INT1 2 e INT3 1; botón 18; puntos de prueba en 35, 36 y 37. README y pinout
    con el mapa para el firmware.
    - Fuera J406, sus resistencias y la del STAT del cargador: la carcasa V2.3 no lleva LEDs.
    - Misma placa de 46 x 64 mm. H1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
    [01-threaded-base.step, 02-logo-tube.step, 03-antenna-cap.step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]
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2026-10-13 Firmware 0.9.0 del MeridianV: arreglos de la auditoría, identidad y placa v0.3
    - Auditoría de fluidez (la misma del MeridianVI): la microSD ya no bloquea /api/status
    ni el BLE, watchdog del bucle principal, escaneos Wi-Fi espaciados,
    correction_hold_max_ms; el caster local lee la cabecera del rover por pasadas y la
    autoconexión NTRIP espera a que haya Wi-Fi.
    - Sourcetable por una conexión aparte sin soltar el NTRIP activo; parser RTCM3 que
    descarta al instante una trama a medias cuando llega una válida y a 1 s si se queda sola.
    - Identidad del receptor (model, serial, unit_name, capabilities y datos de fabricante en
    el escaneo BLE); sigue anunciando MeridianV.
    - Entorno meridi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
